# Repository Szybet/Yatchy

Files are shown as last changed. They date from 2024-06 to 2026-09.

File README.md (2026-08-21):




<h1 align="center">
  Yatchy
</h1>
<p align="center">
  <b>Y</b>our W<b>atchy</b>, fixed and improved, even made modular
</p>

<p float="left" align="middle">
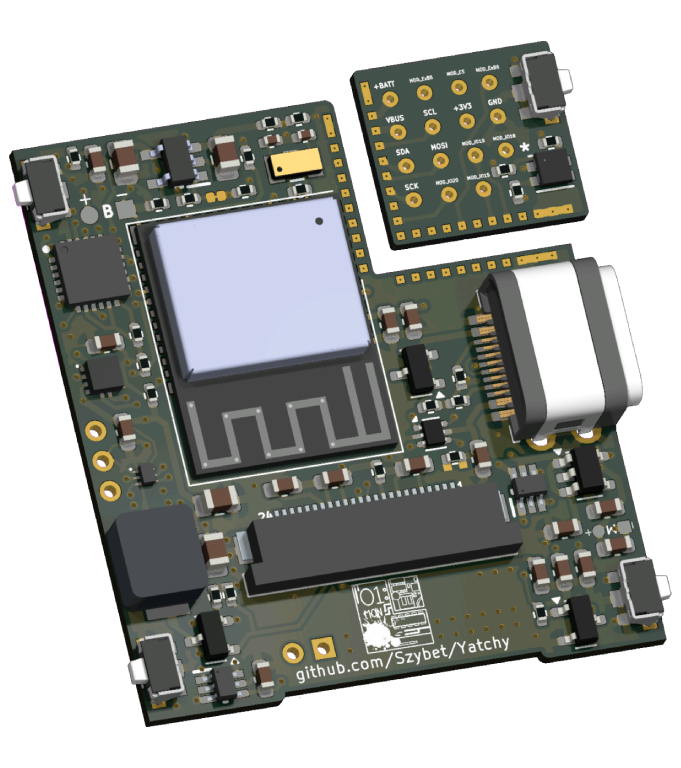
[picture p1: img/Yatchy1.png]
  
</p>

Yatchy is a DIY watch, heavily inspired by the well known [watchy](https://watchy.sqfmi.com/). It focuses on fixing known issues and expanding the potential of it.

#### Key points:
- USBC instead of micro usb
- Better buttons, they won't break easily
- [Better battery life](https://github.com/Szybet/Yatchy/blob/main/hardware/power-consumption/README.md)
- Hardware hackable, easier to self assemble from scratch
- Fixed many issues and improved minor things
- A backlight is possible, *[kind of](https://github.com/Szybet/Yatchy/blob/main/3D/cases/README.md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)* and many other "extensions"
- [Smaller](https://github.com/Szybet/Yatchy/blob/main/faq.md#dimensions) form factor

<details>
  <summary><h3>Pictures</h3></summary>
The coolest yatchy, contributed by a community member!


<sub>My Yatchy, with a [titanium anodized case, the rotated variant](https://github.com/Szybet/Yatchy/blob/main/3D/cases/JLC3D.md#anodyzed-slm-titanium-tc4-no-polishing)</sub>

<p>
  
  
</p>

<sub>The battery is on the side because it's easier for me to measure power consumption, there are [cases with the battery inside](https://github.com/Szybet/Yatchy/tree/main/3D/cases)</sub>



<sub>A clean soldering job, with some alternative components (compability!)<sub>, yes, I know there is a short on the flex cable, it fell off when cleaning after the picture</sub></sub>


Watchy one the left yatchy on the right, yatchy is smaller (yes, the battery is outside, but it would only increase height, not width/length



<sub>Picture contributed, thanks!</sub>

</details>

## Yatchy features in more detail:

<h4>For regular users</h4>

- Heavy increase in battery life, even with the screen updating every minute <sub>(The esp32c6 has a riscv lp core, which i connected to the screen, which means the device never really wakes up fully to only update the screen, not only that i fixed sqfmi flaws (Using 2 voltage dividers for example) I also use the external crystal clock for the RTC which means no RTC IC... and many more such things)</sub>
- Better buttons, more solid, shouldn't and probably won't break that much if at all. They are also very quiet. If you like the tactile feel of the original buttons, you won't like these ones. Luckly vibration motor feedback is possible.
- Solid USB-C port <sub>(It's THT soldered)</sub>
- no more usb compability problems <sub>(Because the esp32c6 uses native jtag programming)</sub>
- better detection of charging, charge finishing. <sub>(In software it was hacky on the original watchy, there were problems with it, never worked good)</sub>
- support for more wireless protocols, home automation ones, wifi 6 too
- TVS diodes, voltage spike protection - which means no more destroyed devices because watchy doesn't follow any USB spec and allows your device to burn down...
- More precise time, based on some loose math and experiments, it should drift only a minute after a month, compared to the watchy its a lot better, **from experience it's even better than that**

<details>
  <summary><h4>For advanced users</h4></summary>

- Detailed ordering and assembly [guide](https://github.com/Szybet/Yatchy/tree/main/hardware/create-your-own)
- Detailed soldering and testing [guide](https://github.com/Szybet/Yatchy/blob/main/hardware/create-your-own/assembling.md)
- **A module area**, with almost all exposed pins from the esp, power lines, and many gpio pins thanks to the expander IC - You can create your own module, increase the capability of you yatchy without modifying everything inside - solar panel module, encoder instead of the button, sd card module, frontlight module, torchlight module, speaker module, microphone module, some environmental sensors. The only limitation is your imagination (And the size of the module)
   - The default module (In the picture above) allows for for attaching small things without the need for a custom PCB
- All the components are newer, still available and produced. They are also listed, with links to mauser / tme. Ordering a Yatchy PCB and the parts, soldering them themself is possible and easier than the watchy
- All QFN packages IC's on the board have increased pad sizes, so if you are skilled enough to solder QFN packages, here it will be easier
- I used traces teardrops, so more solid traces & pads
- A [hardware test program](https://github.com/Szybet/Yatchy/tree/main/hardware/create-your-own/test-program), which allows testing if all the pads of the esp32c6, which is the hardest part to solder are soldered correctly
- JTAG debugging via usb, yay

</details>

<details>
  <summary><h4>Flaws</h4></summary>

- No battery connector, the module pads are small - so it's not for everyone, harder to use / assembly (solder!) for beginners
- There is no dedicated place for the motor, it needs a dedicated place in the case. Soldering the motor cables also is not easy
- It's watchy like but not watchy case compatible, the size and form factor is the same but the obvious obstacle is USBC, even with it the buttons are different and placed a little off to save some space
- It's a 4 layer PCB, so a bit more costly (With JLCPCB it's still cheap)
- No easy hard reset option, you will need to short pins, but you probably won't need it. <sub>When developing the Yatchy, I only once needed a full reset</sub>
- A complicated license (but still open source!)

</details>

## Software
It's fully supported by [InkWatchy](https://github.com/Szybet/InkWatchy). Maybe a rust firmware in the future? We will see...

## Hardware sources, buying, reselling, license, battery life, time accuracy
Everything explained [here](https://github.com/Szybet/Yatchy/tree/main/hardware)

## Cases, 3D files of the pcb
[Cases here](https://github.com/Szybet/Yatchy/tree/main/3D/cases) and [pcb 3D model here](https://github.com/Szybet/Yatchy/tree/main/3D/pcb)

## [FAQ](https://github.com/Szybet/Yatchy/blob/main/faq.md)

# Community
Create a github issue or get in touch with me on the discord server or matrix space (on top of this read are links)

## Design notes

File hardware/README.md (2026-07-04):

# Other related docs:
1. [Power consumption](https://github.com/Szybet/Yatchy/tree/main/hardware/power-consumption)
2. [Time accuracy](https://github.com/Szybet/Yatchy/blob/main/hardware/time-accuracy.md)
3. [Create your own](https://github.com/Szybet/Yatchy/tree/main/hardware/create-your-own)

## License
<sub>Read all of it :)</sub>

This work is licensed under a [Creative Commons (4.0 International License) Attribution—Noncommercial—Share Alike](https://creativecommons.org/licenses/by-nc-sa/4.0/)

Don't scream "IT'S NOT OPEN SOURCE", let me explain myself.

- First, this work is not a watchy fork, it's a complete redesign obviously inspired by the watchy form factor, but nothing more.
- I don't want SQFMI to steal this design and sell it. Not even if I could profit of it. His bad software, bad communication, sometimes bad and questionable hardware decisions have killed so much potential of the watchy.
- I don't want someone to just make money off it and give nothing back to the project. With that said, calm down, more on that in the commercial section below.
- I don't want for someone to rename it and take the credit for the hard work.

Is it too much to ask for? The whole issue above I have is very known in the open source world, you can see it everywhere around us, here is [Jeff](https://youtu.be/4aaF2HgTVe8?t=84) talking about it. If there appears a open source license which fixes this issue, I will switch to it. 

Oh did I mention **it's is open source anyway?\*\*\*** I share the full source, the schematic, the PCB source files, the needed* (more on it below) software. It's just not the pure open source definition, but the literal interpretation of it. Element of open source like contributing, forking etc. are still allowed and welcome, but with the restrictions above.

<details>
  <summary>Further thoughts about it:</summary>

On https://opensource.org/osd we can see, in the first point "Free Redistribution" and well, first "as a component" hardware can't be a component really, so this point doesn't apply to hardware. The whole point doesn't work for hardware, we know how the world works, it works for software, that's why [InkWatchy](https://github.com/Szybet/InkWatchy) is GPL3. Let's search further, on https://www.oshwa.org/faq/#what-license-to-use we can see the question "Won’t people rip me off?" exactly what I have been searching for! The answer is "Maybe"... ugh... Well their explanation is good but a maybe is too much for me... There is also that: https://mifactori.de/non-commercial-is-not-open-source/

The blog post just shows a general opinion / statement on the internet about this topic, some of the points there make sense to me but some not at all, like `Yes, you do. But so does every patent` Wtf even is this? Sharing something to file a patent is completly different from sharing everything to be reproductible. Also patents can't be compared to hardware things most often because patents say you created something new, but hardware is often a combination of other creations, not entirely new things. Open source is not just "It's commercial, you can ripp me off", it's more than that...

so the entire situation is a joke for me. I can't have a "open source" hardware license without someone "Maybe" ripping me off. So it looks like that:

What I want from "Open source":
- To allow people modify, build their own from scratch, even sell the hardware to some extend, do deep repairs etc. (Which I do, but I'm forced to use the `Creative Commons (4.0 International License) Attribution—Noncommercial—Share Alike` license.)

What I don't want:
- People ripping me off

Sad, it just looks like someone long time ago took a software license, applied it to hardware which doesn't work in the real world and started calling out everyone "Uh oh, it's actually not open source because you are not allowing people to ripp you off"

Rant end, here is what you are left with:

A device that is not open source from the strict definition, but has the bare source for replication available, with elements of open source allowed and the author is open about this all.

* * *

It's not only me having this opinion, other makers also share it:
- https://github.com/o7-machinehum/flipper-blackhat-a33#license

:)

</details>

Update 2026:

Prusa released the [Open community license](https://github.com/OpenCommunityLicence/OpenCommunityLicence) which is basically what I'm saying above but I allow a bit of commerciallity, so that's cool, if they release a plugin like the Micro Business one, but smaller (Nano business?) then I would switch fully to it, so it's less confussion.

## The design of the Yatchy
Yatchy was designed to:
- Be created by yourself. That means it's adjusted to be hand solderable. Sooo that means changed footprints for easier hand soldering. If you can solder SMD without a problem and QFN packets aren't scary for you, but BGA is a bit, then it's for you
- Extremely hackable and modular. The main point is the module and all exposed pads for it
- Optimisation of the ammount of different components, so cheaper
- I tried to use widely available IC's and components. For example, while using some highly mauser only specific IC could improve power consumption a small bit, I preffered the simplicity and availability of the current design

Those design choices have their own flaws:
- It's not possible to order a assembled yatchy from a manufacturer. Not only because of the module, but the modified footprints have not adjusted solder mask (And I don't have the experience and money to test it). **Also to be clear, a stencil is also untested, probably won't work for the reasons explained a sentence ago, you have been warned.** - And with that in mind, let's go to the commercial section

## Commercial
As mentioned above, It's not possible to manufacture yatchy on a mass scale (The original vision ones, doing a "regular" one, sure i gues). I don't even want to, I'm a student, I won't just start a company. I plan to sell a few Yatchy to community members and that's it.

But if you plan to create a Yatchy for yourself (because you have the skills required) you are fully allowed to do so! I will support it fully, you should also consider creating some for people who can't do that. I will fully support it too! Just remember to contribute some docs, code, help, small donation if you create some more and it will be fine :D

So "Commercial use" for the yatchy as in: using it as a cash grab, without giving anything back, which is not allowed.

If you plan to really mass produce them, then we should talk I ques.

**So you want to create your own? There is a doc for that: [Creating your own](https://github.com/Szybet/Yatchy/blob/main/hardware/create-your-own/README.md)**

## The ability to enforce the license
First some explanation:

Yatchy uses esp32c6 which has a lpcore which allows for updating time on the screen in a more efficient way, in a seperate program.

So all this talking is cool but it's just on paper, I can't enforce it, let's be real. That's why I will lock the full source code of the Yatchy lp program until I make back of what I invested. It costed more than I hoped for. Yatchy can still fully function without the lp core, just the battery life will be worse. I will share the source code partially to all yatchy users (also from other potential sellers) to allow to modify it, like the font used. Then I will simply compile it for them. **Yes, it could be converted into a binary library with a header api**, it was simply not done yet as the program is complicated and has a complicated structure. So that scenario is upon a possible request

More details [here](https://github.com/Szybet/Yatchy/blob/main/hardware/lpcore.md)

## The source files
Kicad version 9.0.3 is suggested.

In the kicad folder inside this directory are the design files for the yatchy v1, not yet tested

they (PCB's) are also a bit messy, not fully profesionall, but they do the job, I hope, as I will order them

Yes, the source files reference watchy in a few places, that's because the name "Yatchy" came after, at first this project was planned to be a small watchy fork.

Schematic, iBom can be seen here: https://szybet.github.io/Yatchy/hardware/read-only/index.html

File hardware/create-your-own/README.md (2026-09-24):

## **A reminder, all of this is provided without any warranty. If something goes wrong and the PCB is bad, wrong components, not my fault**

# [Ordering components & Price](./ordering.md)

# Viewing the PCB & schematic
It's available [here](https://szybet.github.io/Yatchy/hardware/read-only/index.html) but I advice using kicad directly anyway, as this site could be outdated

or [kicanvas](https://kicanvas.org/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)!

# [Assembling Yatchy](./assembling.md)

## Binner.io
~~I started using Binner.io, if you want to manage your Yatchy parts in it, [here](https://github.com/Szybet/Yatchy/blob/main/hardware/BinnerParts.xlsx) is the export with all the parts. Yes, it could be outdated.~~ Don't use it: https://github.com/replaysMike/Binner/issues/397 :(

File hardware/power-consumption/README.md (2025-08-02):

## Note
Obiously this is outdated, constant updates and improvements will make those numbers better (not by a lot but hey), but probably not make it worse (not by a lot but hey) so this is just a very general overview

## TLDR: Please read this document to understand that measuring battery life is challenging. The best-case scenario calculations are provided at the end. This document explains the results, emphasizing that they do not tell the whole story. Your actual battery life may be worse than indicated, and I want to clarify that I take no responsibility for this (For anything really)

Once again, **once again** and ***once again and again*** those measurements are not in lab quality - I measured things again after a few months and it showed 3 times more. Did the humidity change? Did saturn catch mercury in a 10 degrees of happiness? Did the meassuring tool catch some dust? Idk? **What I can say I just used it for a while and those results are reasonably mirrored in real life, so take this doc as a best case scenario**. Also did I mention using different components from different batches can result in worse battery life from nowhere? That's also fun, so your Yatchy can work worse. Or better :)

Ok, first, measuring power at such low values is extremely hard, temperature, humidity can affect the values. Not only that, your touch, sight, planet position, random things can affect the results. What I'm trying to say, it's extremely hard, those are not 100% scientific values. But I took them many times to make sure they are similar and they have been taken on the nordic power profiler kit II, so it's valid enough I think.

The best example of problems I'm facing is that I used some nail polish to make it more water resistant, this improved the power consumption by -20uA. It could be that, my best ques at least... It's really random and hard

[Here](https://github.com/Szybet/Yatchy/blob/main/hardware/power-consumption/Where%20is%20my%20current%20-%20The%20game.pdf) you can see my latest fight with the demons of power consumption, the enemy who stabbed me from the back was... the LED diode (But I fixed it, now it's a lot better).

Also, a funny video demonstrating how measuring such low currents is hard, it's just my hand, no magnets or anything

https://github.com/user-attachments/assets/14860d4f-65ae-4cec-a94b-b5c265fb9386

Now that we know to not worship those results, some important things first:
- Yatchy obviously uses the lp core
- Those are only during time updates, not interacting with the watch. Any interaction will obviously drain a lot of battery, so the final battery consumption will be heavily based how much you just look at the time or just interact with the watch
- The `.doc` files in this dir can be used to calculate the power consumption for your settings, battery. But to understand what is going on there, first you need to read the rest of this document. **Oh and the docs screenshoots are at the bottom of this document if you don't want to change anything but you are too lazy to look it up**
- Those files are chaotic, I know, I don't care, they do their job
- For watchyv2-calculations.ods to match this: https://github.com/Szybet/InkWatchy/wiki/InkWatchy-battery-life-measurements you need to take into account that the measurments there had a night delay, while those calculations don't. To make those results match, set the wakeups in one hour to 43. Yatchy doesn't need such optimisations, that's why I skip them ;)

Devices used:
- Yatchy v1 without an accelerometer. If you want to "simulate" adding of the acc, add a few uA to the full sleep value
- Watchy v2, regular one.

Description of functioning of those devices

Yatchy:
- "Regular lp core time update" Is the most regular time update, it happens most often, almost every minute
- "First time update lp core" Happens after "hp core update"
- "hp core update" Is when the main program, in this case InkWatchy is launched. You can control how often this happens, at default it's every 29 minutes so 2 times an hour. It takes the most amount of battery, but it's important as it updates other things on the watch, not only the time.

Watchy:
- Here it's just "hp core update" all the time, as Watchy v2 (or even v3) can't use the lp/ulp core to update the time

# Conclusions
I'm happy with it

Now some images that explain the values in the docs

# Yatchy
Full sleep


Lp core regular time update


Lp core first time update


Hp core wakeup (In the future, it could be 1s smaller)


# Watchy v2
Full sleep

Umm this looks a bit much, well, power consumption magic, maybe my connections is somewhere off, maybe something something is off. Previous reads, which I don't have saved gived me reads of around 130-160uA so let's treat it like this, this picture is anomaly

Hp core wakeup (It matches in timing the one from Yatchy & 


## SS
yatchy calculations:

watchy calculations:


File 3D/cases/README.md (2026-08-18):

# Yatchy cases
If you create your own model, fork one, or anything else, please (in addition to putting it in your repository, on a 3D model website, if you feel like it, etc.) contribute it here so it won't get lost in the ether of poor search engines. Sharing files that can be modified easily (STEPs, not STLs) is also suggested, but not required.

### The files are in the folders in this directory

### JLC3D
If someone doesn't have a printer or wants some premium quality (materials), [Here is a review of JLC3D for yatchy cases](./JLC3D.md) (Not sponsored)

<h1>$${\color{red}Patches}$$</h1>
Because of the tight tolerances and different printers, filaments, some cases might have alternative parts that might fix your issues, read their description and decide for yourself, generally, I would advice using them

## Szybet's side case
<p align="center">
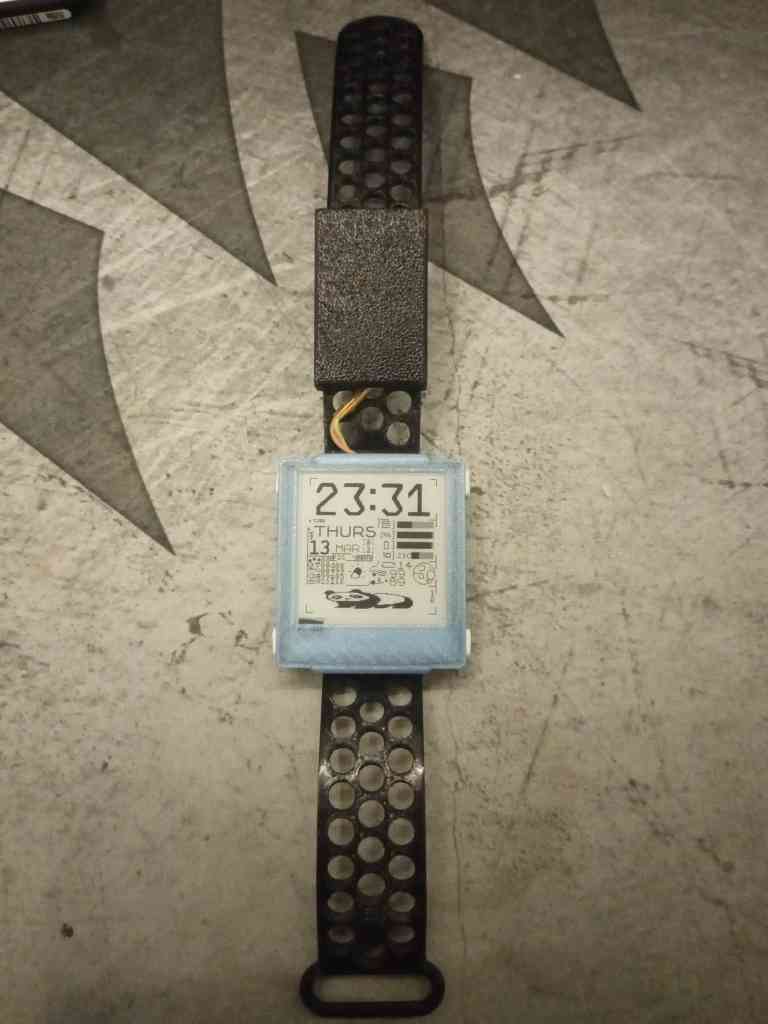
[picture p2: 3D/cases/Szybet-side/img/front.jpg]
  
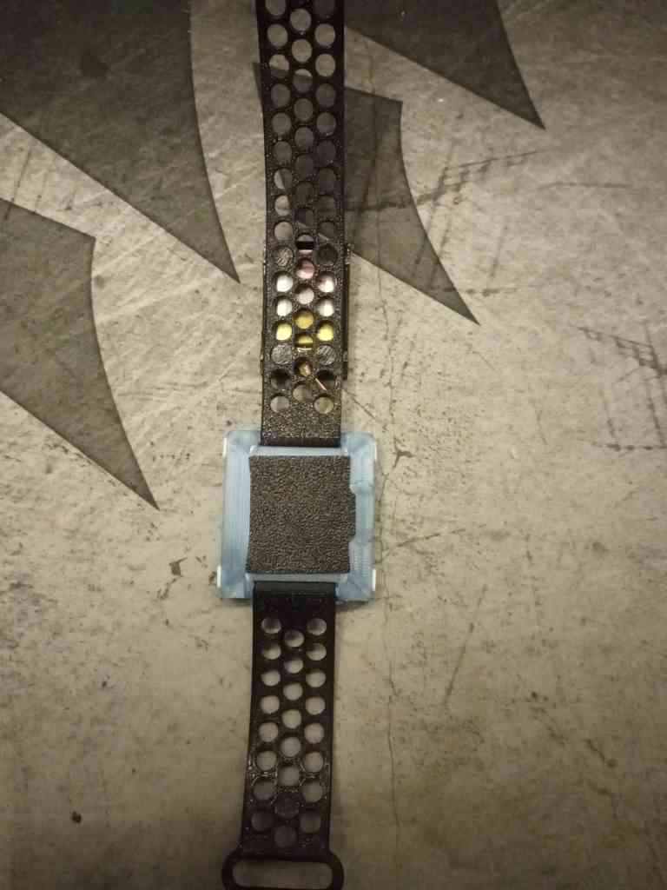
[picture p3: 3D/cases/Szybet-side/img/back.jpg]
  
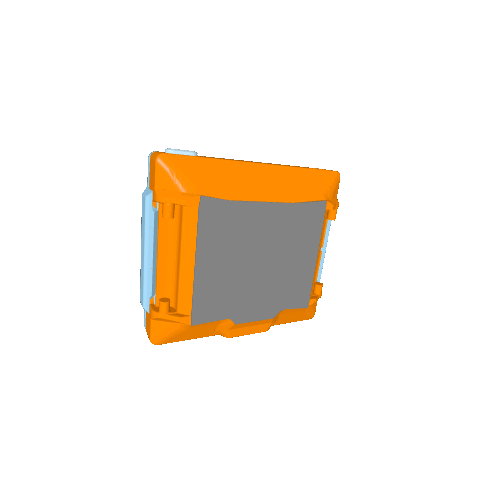
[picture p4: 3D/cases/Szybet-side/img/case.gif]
  
</p>

<details>
<summary>Fit and dissasembly demo</summary>
  
<p align="center">

https://github.com/user-attachments/assets/d5af4c48-378c-4553-9d58-3c49acbb4d74

</p>

</details>

Notes:
- Yes, it's designed for the battery to be on the side (and more space for module hackery), yes you can modify it for your needs
- The top snaps into the bottom case, no screws, it's tight and easy to dismantle
- The strap & battery case is printed from a flexible material, TPU in this example.
- Requires a 0.2 nozzle, a **very good 3D printer**. The tolerances are very tight. - for the case, the layer adhesion must be good otherwise it could break when buttons are inserted. (Semi transparent PETG has good layer adhesion, I think)
- The motor cover is for this motor: https://pl.aliexpress.com/item/1005004948677826.html?gatewayAdapt=glo2pol
- The module led cover is for the led to redirect the light to the side. I used a silver marker for better effect
- The side battery case has many files in it, they all should be printed as they are
- Needs strong layer adhesion, otherwise it will break near the edges. Some glue on the inside or transparent PETG does the job
- Patches nr 1 apply

License:

[Creative Commons (4.0 International License) Attribution—Noncommercial—Share Alike](https://creativecommons.org/licenses/by-nc-sa/4.0/)

### Szybet's brick case
<div align="center" style="white-space: nowrap; overflow-x: auto;">
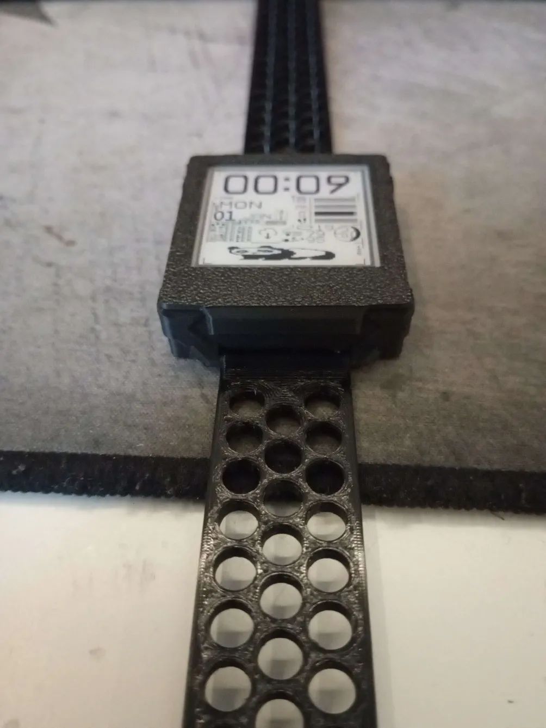
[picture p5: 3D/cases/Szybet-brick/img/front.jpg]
  
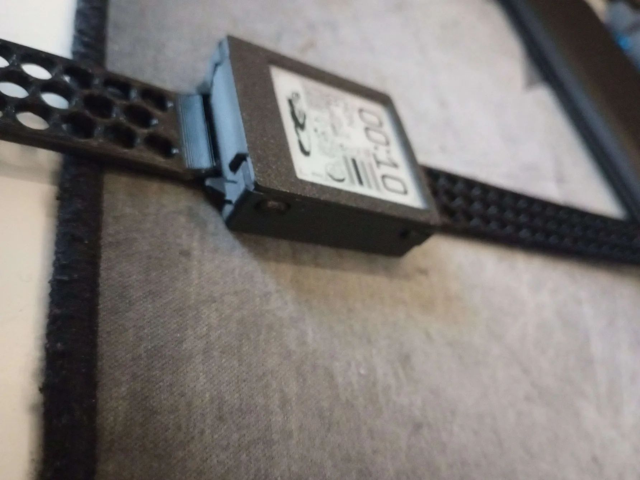
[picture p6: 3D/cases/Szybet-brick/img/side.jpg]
  
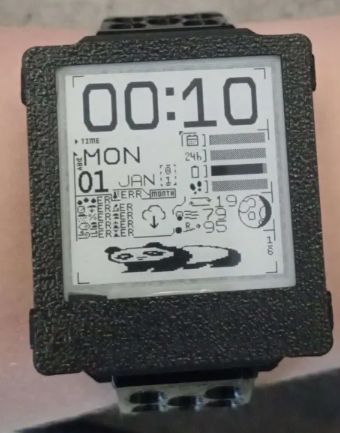
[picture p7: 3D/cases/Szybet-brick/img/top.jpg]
  
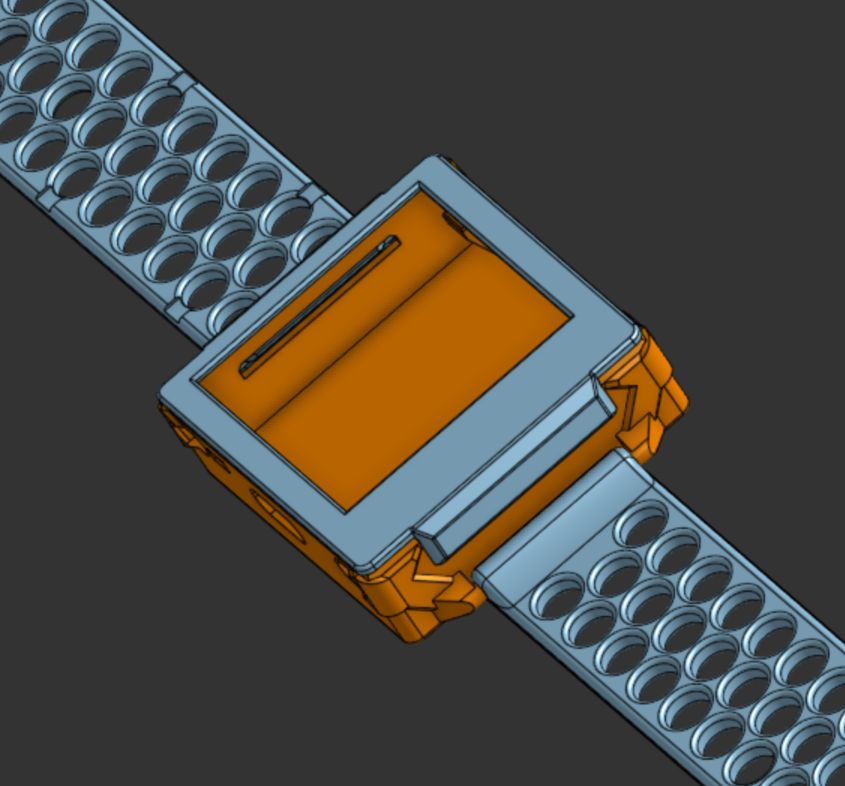
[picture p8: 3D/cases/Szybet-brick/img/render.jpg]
  
</div>

Notes:
- This is a fork of "Szybet's side case", most of the notes from there apply here (license too), the design of the buttons, top is the same
- Yes, it's a simple brick, based on the side case, it's a base for modifying it for other cases with the battery inside
- The texture on the corners is for making them stronger, less breakable
- The strap still has cutouts for attaching something to them
- If the battery is inserted in a wrong way and the cables will touch the buttons, they might get stuck
- Patches nr 1 apply

### KitKat's rotated case
<div align="center" style="white-space: nowrap; overflow-x: auto;">
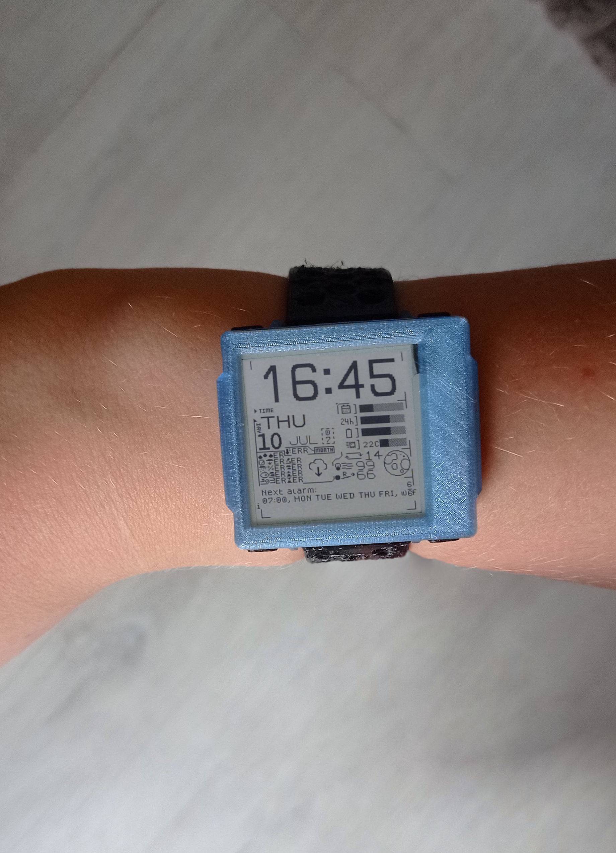
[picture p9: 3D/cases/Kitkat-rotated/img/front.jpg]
  
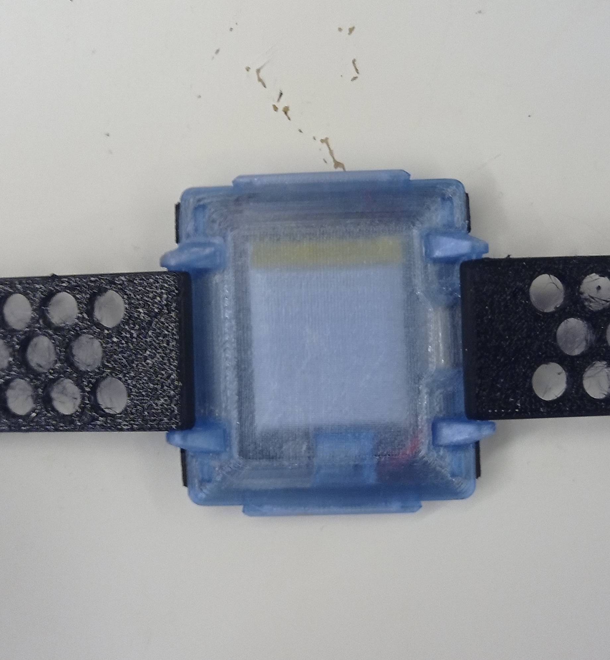
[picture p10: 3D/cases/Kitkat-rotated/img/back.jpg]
  
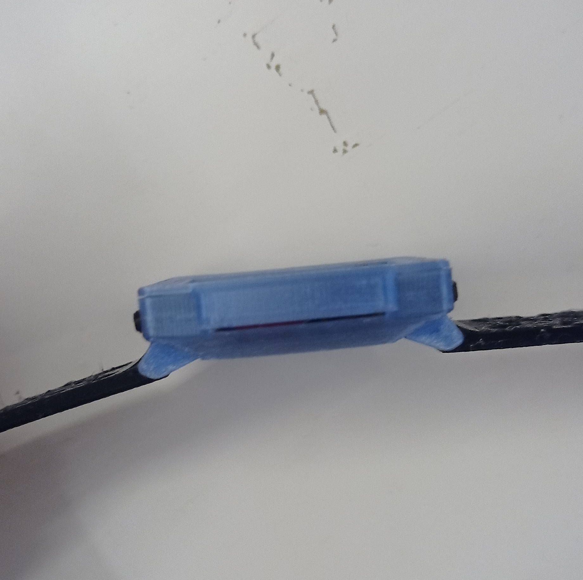
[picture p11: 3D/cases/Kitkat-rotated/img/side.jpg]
  
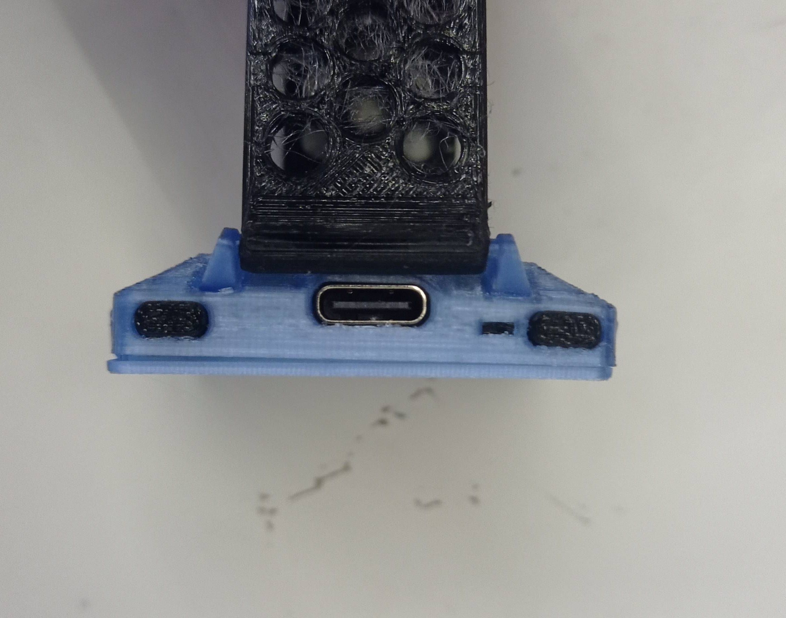
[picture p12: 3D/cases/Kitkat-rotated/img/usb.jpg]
  
</div>
<div align="center" style="white-space: nowrap; overflow-x: auto;">
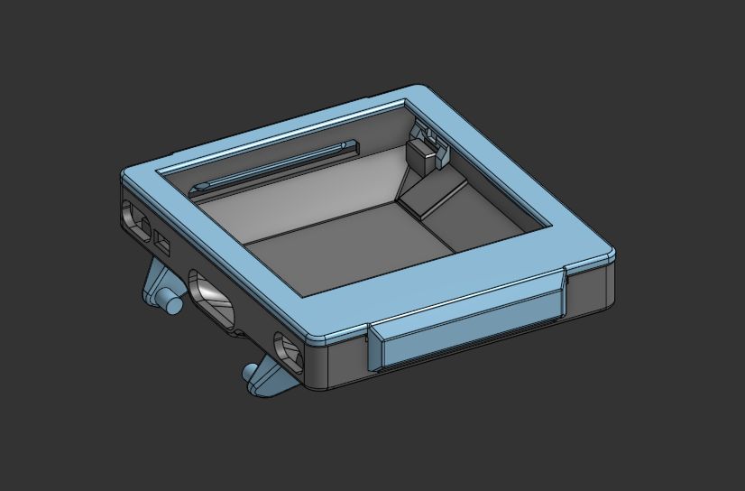
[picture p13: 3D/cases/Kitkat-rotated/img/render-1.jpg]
  
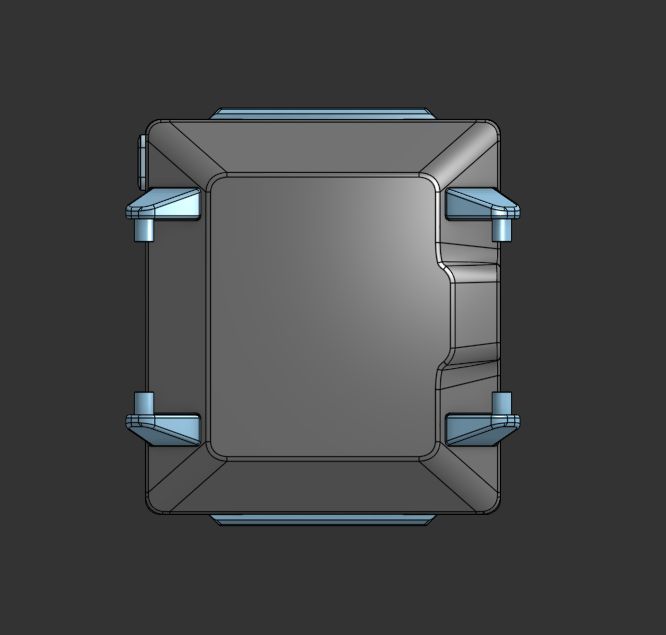
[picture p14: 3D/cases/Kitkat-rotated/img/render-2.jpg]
  
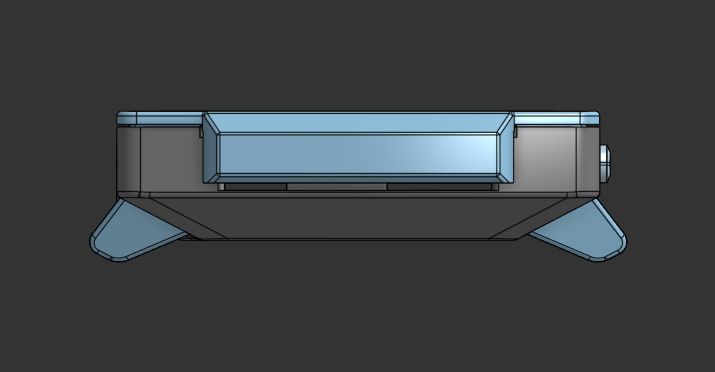
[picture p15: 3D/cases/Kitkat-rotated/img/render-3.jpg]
  
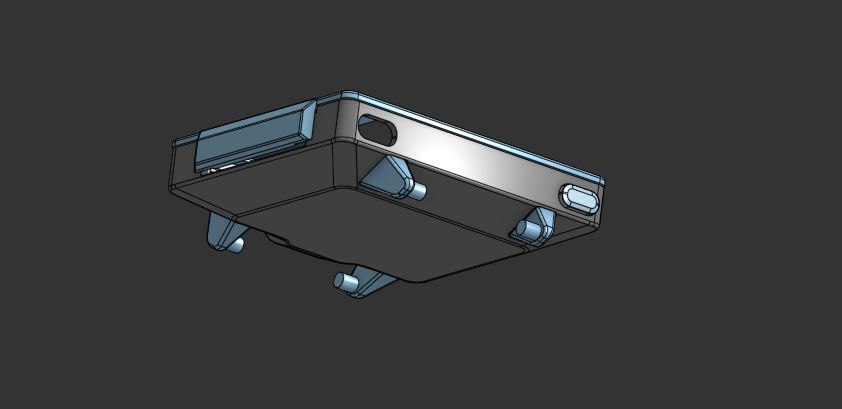
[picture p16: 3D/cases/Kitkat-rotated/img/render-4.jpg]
  
</div>

**The Images above are for the 150Mah case version**
<div align="center" style="white-space: nowrap; overflow-x: auto;">
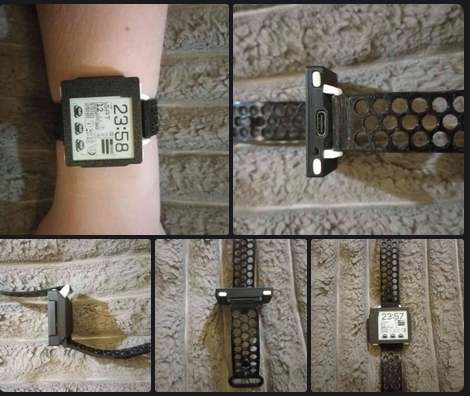
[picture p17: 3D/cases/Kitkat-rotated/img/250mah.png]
  
</div>

**The Image above is for the 250 mah case version**

#### Proof of concept: Glow in the dark transparent filament (With the rotated case)
<div align="center">

https://github.com/user-attachments/assets/10055fae-86bb-440f-bbc3-9d33e8c1605a

</div>
  
- Kind of a backlight, I can read the time. It could be improved in many ways (Increase led brightness, use a reflective tape inside the case)
- The glow in the dark filament looks better in reality than on camera

Notes (About this case in general):
- The 250 mah battery is 30 x 20 x 5 mm and the 150 mah battery is 25 x 20 x 4 mm
- The strap holders on the 250 mah version are assymetric
- This is a fork of "Szybet's side case", most of the notes from there apply here (license too), the design of the buttons, top is the same
- Requires changing the config in Inkwatchy so the screen is rotated properly
- The pieces that hold the straps need to be glued onto the main body using superglue
- The strap still has cutouts for attaching something to them
- The battery fits inside but requires short wires for it to fit properly 
- The motor is attached to the inside of the case which can make it more difficult to dissasemble
- Larger USB-C plugs may not fit due to strap clearance
- case_front_v2 and better_strap_dot from patches 1 applies
- Those are pictures of a prototype
- **The buttons are objectively easier to access**
- The LED now shines outside of your wrist, not on it                                                                                                                                         

### Glaucon1984's Brick case remix
<div align="center" style="white-space: nowrap; overflow-x: auto;">
  
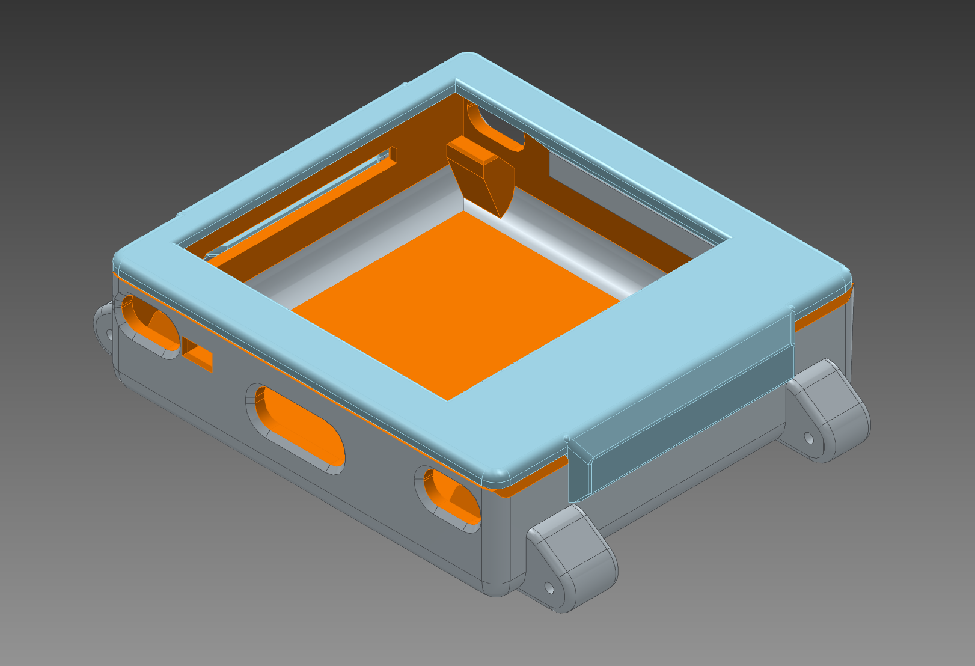
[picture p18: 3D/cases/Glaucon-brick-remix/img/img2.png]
  
  
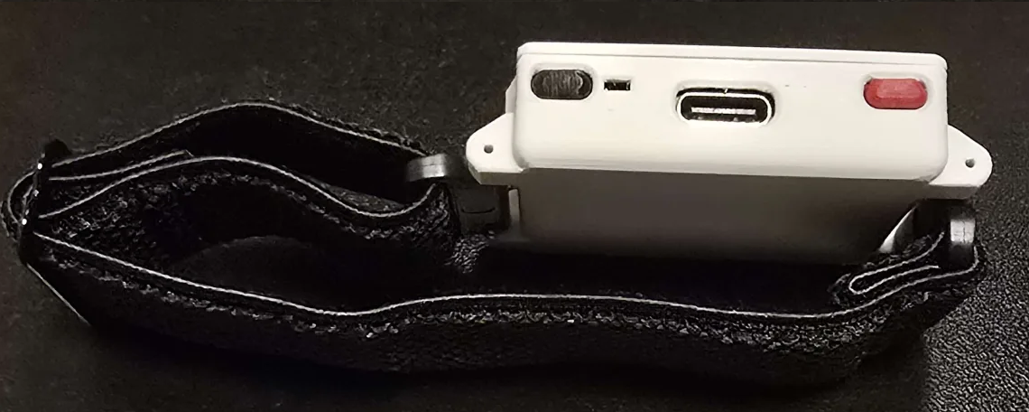
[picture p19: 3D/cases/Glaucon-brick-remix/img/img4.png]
  
</div>

Notes:
- The main purpose of this remix is to be able to use regular watch straps, make the case a bit stronger and have smoother edges, these are the main changes:
- Based on Szybet's brick case
- Made thicker walls and bottom
- Smooth edges
- Added prongs to attach a 22mm strap
  - It uses a standard 22mm watch strap, the one in the picture is this one: https://www.amazon.co.uk/dp/B0C2414BMX (nothing special about it, I think it was one of the cheapest ones)  
- Added some geometry to centre the circuit board
- The front panel hides a bit more of the bottom of the screen (you can see the picture)
- Buttons are slightly longer to account for the thicker walls in the case
- The holes for the buttons and the USB-C port are chamfered to hide the imperfection from 3D-printing supports
- The top case is slightly thicker
- The 3MF contains print settings, but just in case, it must be printed with a 0.2 mm nozzle. It's been tested only with PLA and it works great. I recommend a 0.6 mm layer heigh for precision. There's very little infill in the model but I would recommend to use gyroid at 30%. The watch case should be printed on the flat side of each part, the buttons should have this side touching the build plate:


- Creator's [makerworld page](https://makerworld.com/en/@glaucon1984) and [makerworld page for this case](https://makerworld.com/en/models/1798293-yatchy-brick-case-remix)

### Glowy's Thicc boi  

<div align="center" style="white-space: nowrap; overflow-x: auto;">
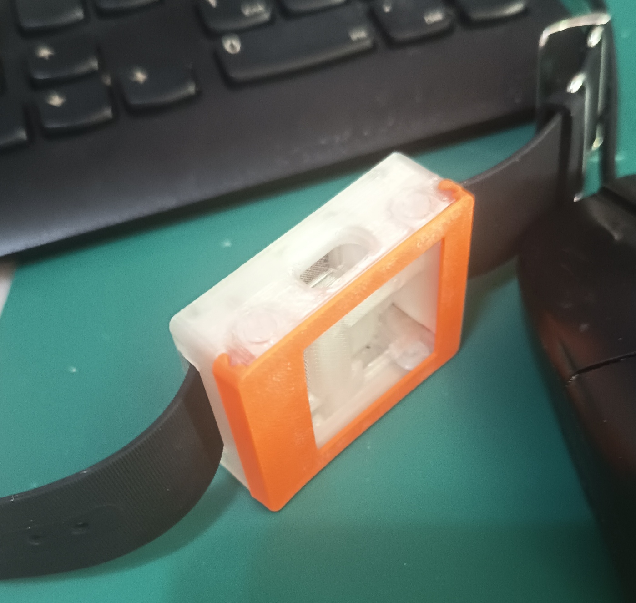
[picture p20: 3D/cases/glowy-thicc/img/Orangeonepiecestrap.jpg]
  
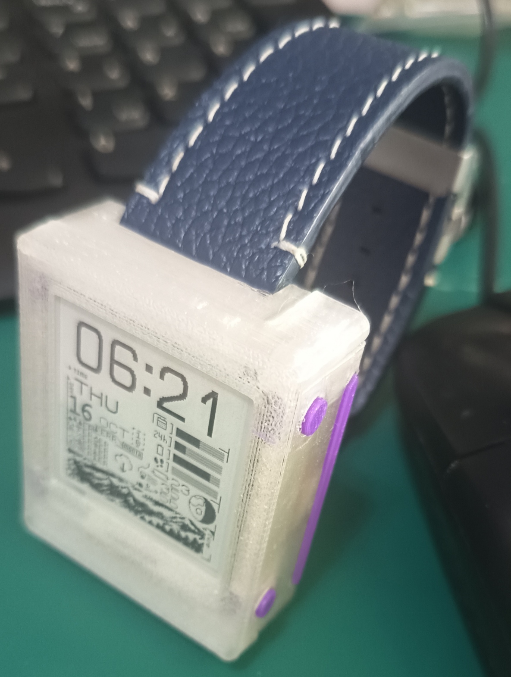
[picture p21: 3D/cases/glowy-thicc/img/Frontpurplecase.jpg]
  
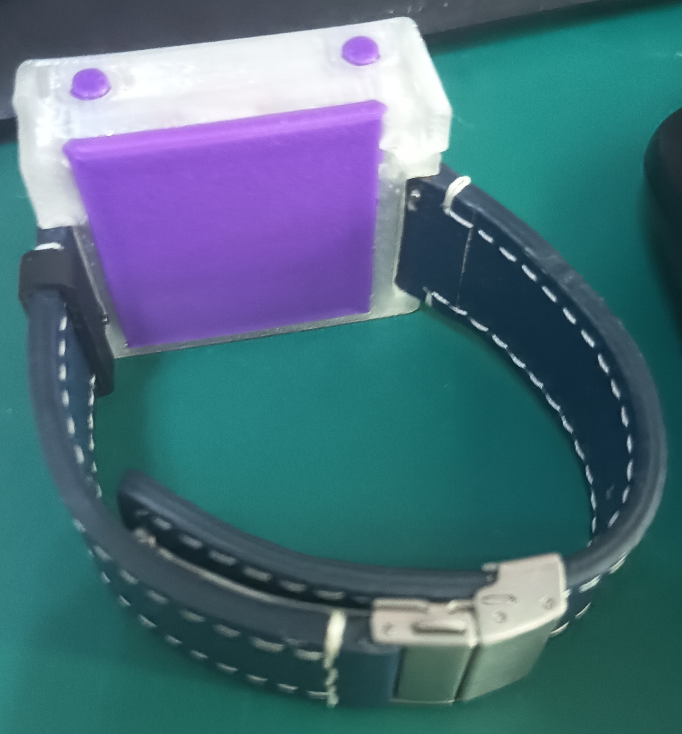
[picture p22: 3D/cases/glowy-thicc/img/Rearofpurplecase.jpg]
  
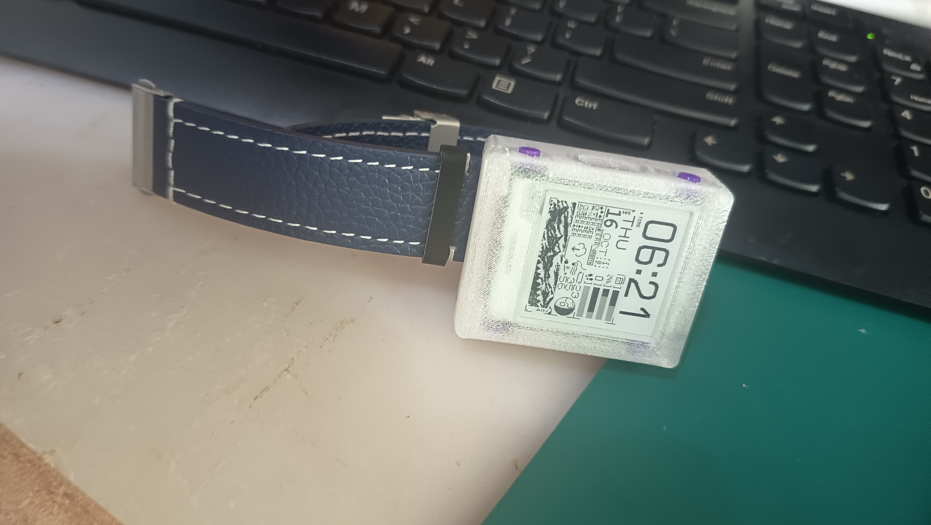
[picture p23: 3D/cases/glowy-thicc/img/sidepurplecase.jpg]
  
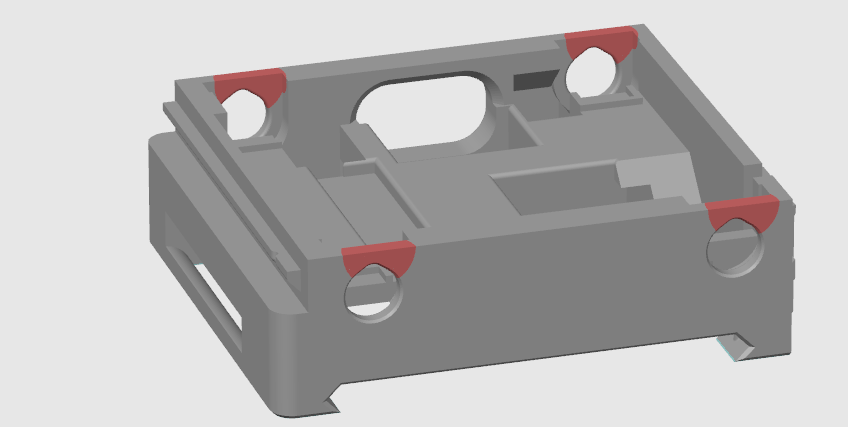
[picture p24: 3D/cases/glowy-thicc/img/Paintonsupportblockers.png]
  
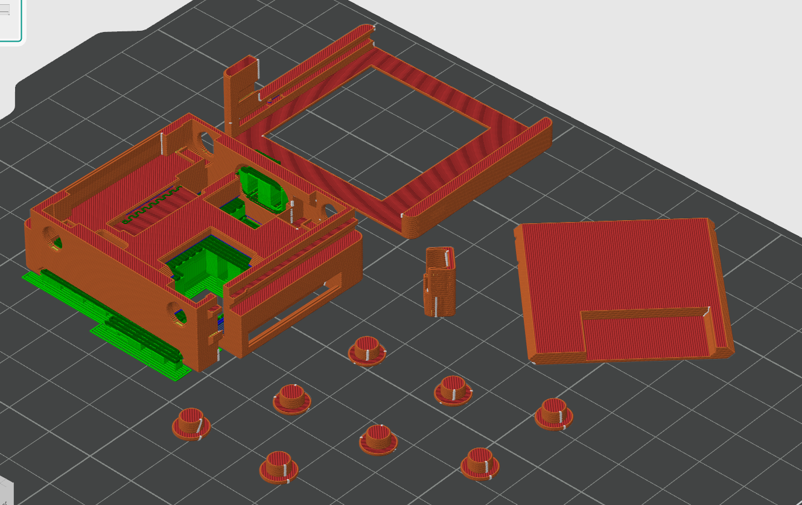
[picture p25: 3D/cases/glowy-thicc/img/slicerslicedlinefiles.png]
  
</div>

**Notes:**  
- This design was **created entirely from scratch**, not based on any previous Yatchy case or remix.  
- The **walls are thicker**, offering more protection and a sturdy feel.  
- A **light-reflecting patch** allows illumination through translucent filament — or use aluminum tape to redirect the light outward instead of into your hand.  
- The **faceplate is easily removable and customizable**, and no glue is needed during assembly.  
- Designed for **quick part swaps and battery replacements** without modifying the model.  
- The case remains **comfortable and ergonomic** despite its thicker construction.  
- The **battery compartment** fits packs up to *33.9 × 25.9 × 5.4 mm* (tested with a 250 mAh cell).  
- The case has been **impact tested** — with an acrylic faceplate, it even survived a 200 fps 1 g projectile.  
- The **strap shown** in the pictures is a *24 mm leather watch strap*,  [this one on Aliexpress](https://www.aliexpress.com/item/1005005510563576.htmlhttps://www.aliexpress.com/item/1005005510563576.html) — though any standard 24 mm strap works fine.
- For the one piece strap you can use any 22 mm x 1.6~mm thick strap [this one on Aliexpress](https://www.aliexpress.com/item/1005007712667222.htmlhttps://www.aliexpress.com/item/1005007712667222.html)

If any issues arise, or you would like to use another type of strap, feel free to reach out on Printables or Discord, glowyglowbug.  

**View on Printables:**  
Thicc Yatchy Case (https://www.printables.com/model/1443956-thicc-yatchy-case)

**Watch the Demo:**  
Watch the Demo (https://www.youtube.com/watch?v=wA29wyvOd8w)

### Michal's gameboy
<div align="center" style="white-space: nowrap; overflow-x: auto;">
  
  
</div>

- More info at: https://github.com/Michal-Szczepaniak/watchy-case/tree/master
- Fits the 450mAh 303040 LiPo
- Inspired by the watchy gameboy case

### Case comparison
- without top case or the pieces that hold the straps

| Case | Height (mm) |
|---|---|
| Kitkat's Rotated 250 mAh version | 10.29477 |
| Kitkat's Rotated 150 mAh version | 8.70611 |
| Szybet's Side | 9.55611 |
| Szybet's and Glaucon1984's Brick | 10.96346 |
| Glowy's Thicc Boi | 15.3 |
| Michal's gameboy | 11.2 |

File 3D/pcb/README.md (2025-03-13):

This model is a simplified (so not so heavy, while keeping geometry) model of v1 Yatchy pcb, screen and flex cable.

Notes:
- not the V1.1, if you want a more precise one, just export it from Kicad.
- also the module is included with it
- you might want to add a small offset from the pcb to the screen, as double sided tape is in between. In practice, if your tolerances are right (so, any, small ones) this should just work and be tight

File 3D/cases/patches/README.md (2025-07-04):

## 1
- case_front_v2.step - a more tighter version of the front part of the case. Useful when tolerances are bad enough that buttons click each other
- motor_cover_thinner.step - Thinner motor cover, harder to use and place but takes less space
- better_strap_dot.stl - easier to insert strap dot

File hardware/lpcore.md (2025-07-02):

## A more technical explanation

The ESP32-C6 in Yatchy has an LP core, which is a coprocessor optimized for efficiency and runs in RTC memory. It has a maximum of 16KB of memory (without any allocation) or just 8KB for easy compatibility with Watchy firmware, which uses the other 8KB.  

I wrote a program in Rust for this core that displays the time on the screen. This required setting up or modifying:  
- Getting Rust to run on it  
- Log mechanics (to monitor what's happening, disabled in release)  
- RTC memory handling (basic communication with the HP core, i.e., the main program)  
- RTC register access to retrieve time  
- Software SPI (since there's no native SPI)  
- Display driver  
- Minimalist font rendering via partial updates with a small buffer  
- HPCore wakeup  

All of this fits in ~~just 8KB (technically 7KB).~~ Now in 9KB (For better fonts)

It was quite a bit of work, and no one else has done it before. However, for reasons I outlined in my repo—mainly to prevent others from copying the design and selling it without giving anything back—I plan to release only the font rendering part.

Oh, and once I recover the money I invested in developing Yatchy, I'll release everything publicly—no questions asked.

## Font

Because of size constaints, the font is simply some points connecting in lines, like that:

```rust
pub fn draw_zero(fb: &mut wepd::Framebuffer<NUMBER_WIDTH, NUMBER_HEIGHT>) {
    let start = Point::new(6, 4);
    let right_top = Point::new(26, 4);
    let right_t = Point::new(29, 10);
    let right_b = Point::new(29, 38);
    let right_bottom = Point::new(26, 44);
    let left_bottom = Point::new(6, 44);
    let left = Point::new(3, 38);
    let left_top = Point::new(3, 10);

    let points = [
        start,
        right_top,
        right_t,
        right_b,
        right_bottom,
        left_bottom,
        left,
        left_top,
        start,
    ];
    draw_lines(&points, fb);
}
```

But thanks to a [contribution from someone](https://github.com/themkoi) there is now svg to code above automatic conversion, so there are many fonts and they are easier to modify and add. They also look better now, as someone tinkered more with them.

### Creating your own font
(for your own watchface, or simply to adjust for inkfield)

The svg files are up to request, but there are some thing to keep in mind while modifying them:

TODO

***

Let's showcase the ones that are there now, keep in mind:
- Those are codenames and probably outdated codenames
- They are all based on one design, only with minor changes

### Font2


### Font2_bold


### Font_szybet


### Font2_opt


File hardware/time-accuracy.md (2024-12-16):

Test devices:
- watchy v2 with PCF8536 (which in my experience worked better than for other v2 users) 
- yatchy with 20 ppm quartz

Further notes:
- This test is just me making `currentSeconds - ntpCorrectSeconds` in clock debug menu, no fancy scientific stuff
- There are no drift corrections applied, they would help with the stable temperature test but not with the changing temperature test.

## In room temperature
Test time: 1d 9h 27m

Drift:
- watchy v2 - 19 seconds
- yatchy - 2 seconds

Conclusions:
- This watchy v2 would drift a full minute after around 3 days, which matches my experience and usage of it
- This yatchy would drift a full minute after around 31 days, which matches my calculations

## In normal, temperature changing usage
So, outdoor, indoor like a lot, around 0°C

Test time: 20h 6m

Drift:
- watchy v2 - 11 seconds
- yatchy - 4 seconds

Conclusions:

Both drift more, as this test took less time. Yatchy drifts more than I thought but less than some thought and I feared. So yes, the drift will depend on your usage and the temperature outside. But it's still better than watchy.

## End conclusions & Future
It's a bit worse than I thought, but it's okay, but you should decide for your own. I will probably in the future use 5ppm quartz instead of 20ppm ones. The 5 ppm are harder to source, but are 4 times better than the 20ppm ones (Any 32khz quartz will fit, it just needs to be 12.5pF)

If you feel like it, you could just create a module / do some hacky soldering an attach a modern rtc ic to yatchy via the module pins and use that ;)

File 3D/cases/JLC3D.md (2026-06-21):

### SLM Titanium TC4

|  |  |  |
| --- | --- | --- |

<sub>the inside is coated with nail polish in this picture for it to not conduct electricity</sub>

##### Anodyzed SLM Titanium TC4 (No polishing)
|  |  |  |
| :---: | :---: | :---: |

### SLA 8001 Resin transparent
|  |  |  |
| --- | --- | --- |

|  |  |  |
| --- | --- | --- |

### MJF PA12-HP Nylon
|  |  |  |  |
| --- | --- | --- | --- |

### SLA JLC Black Resin
|  |  |  |
| --- | --- | --- |

### FDM Transparent TPU
|  |
| ---------------------------------------------------------------------------------------------------------------------- |

### Notes:
- The case printed is a modified rotated case, with a thicker bottom
- Almost all of the cases are a bit deformed, that's normal, as the whole case was in the "warning" section, as it's thin everywhere. They are still usable, sometimes some tools are needed to adjust them (hot glue, dremel, hot air, forge, file(the tool), death star)
- It's really cheap, just shipping costs a lot
- Toleramces are tough anyway, order only checked design that you are sure about

Invidual notes for choosen technologies:

**Titanium TC4:**
- The surface is not perfect but good enough, anodyzing, electro polish is also an option for chemistry knowing people
- It conducts electricity, so it's advised to coat it with something in the inside. I did with nail polish, but it turned sluggish and yellow so I removed it (works so far, but assemble was stressfull, not advised), but the process was fun:

https://github.com/user-attachments/assets/9837bda7-dd3d-4c27-bf5d-23caa2c6a187

- Top cover is not possible, as it's metal, obviously
- Motor place needed to be dremelled to fit the motor, so needs more adjusting if anyone plans to order it (as nothing will bend even a little)
- The only case where a deformation hurts the most, luckly it fitted for me
- Wifi signal is 30% worse, so still perfectly usable

**SLA 8001 Resin transparent:**
- It looks the best, it's perfect quality
- A bit on the squishy side :D
- ~~I hope it doesn't turn yellow at some point~~ It did after 5 months of use. Also it broke on one screen edge, for some reason...

**MJF PA12-HP Nylon:**
- Interesting texture, stiff but solid, cool
- I tried SLS nylon some time ago and the tolerances were horrible. Maybe they fixed it, MJF is fine

**SLA JLC Black Resin:**
- Looks almost perfectly smooth, some places are less smooth then others
- Pretty stiff
- A bit transparent when wall is thin
- but cool anyway
- The front case broke for me after a while of using, so less strong than FDM

**FDM Transparent TPU:**
- The quality is good, but it's FDM soooo don't go with transparent, go with black or something
- Suprisingly expensive compared to others, and it's just regular FDM?

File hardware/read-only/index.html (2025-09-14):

# Yatchy Project Hardware Files

## Yatchy

### Interactive Bill of Materials (iBOM)

- An interactive bill of materials for Yatchy.
  View iBOM

### Schematic (PDF)

- Main schematic in PDF format.
  View PDF

### Schematic (SVG)

- Scalable vector schematic.
  View SVG

## Module Default

### Interactive Bill of Materials (iBOM)

- Interactive bill of materials for the default module.
  View iBOM

### Schematic (PDF)

- Schematic of the default module in PDF format.
  View PDF

### Schematic (SVG)

- Scalable vector schematic of the default module.
  View SVG

## Module BTBMHM

### Interactive Bill of Materials (iBOM)

- Interactive bill of materials for the BTBMHM module.
  View iBOM

### Schematic (PDF)

- Schematic of the BTBMHM module in PDF format.
  View PDF

### Schematic (SVG)

- Scalable vector schematic of the BTBMHM module.
  View SVG

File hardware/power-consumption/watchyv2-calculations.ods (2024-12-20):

Power consumptions in certain situations | uA | in ms | Whole time took, ms |  | settings | value | other
Full sleep | 130 | - | 3438000 |  | Wakeups per hour | 60 | Whole time 1h in ms | 3600000
hp core update | 32500 | 2700 | 162000 |  | Battery capacity In mAh | 200
Final power consumption in uA: | 1586.65
Battery life in h | 126.052 |  |  | calculations
Battery life formatted | 0 months, 5 days 6.1 h |  |  |  | uA x time
 |  |  |  |  | 446940000
 |  |  |  |  | 5265000000
 |  |  |  | Sum | 5711940000

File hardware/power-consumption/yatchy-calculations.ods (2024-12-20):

Power consumptions in certain situations | uA | in ms | Whole time took, ms |  | settings | value | other
Full sleep | 44 | - | 3550000 |  | Wakeups every x minutes | 29 | Whole time 1h in ms | 3600000
Regular lp core time update | 2800 | 500 | 28000 |  | Battery capacity In mAh | 200
First time update lp core | 2500 | 7500 | 15000
hp core update | 16000 | 3500 | 7000
Final power consumption in uA: | 106.694
Battery life in h | 1874.52 |  |  | calculations
Battery life formatted | 2 months, 18 days 2.5 h |  |  |  | wakeups in hour | 2
 |  |  |  |  | uA x time
 |  |  |  |  | 156200000
 |  |  |  |  | 78400000
 |  |  |  |  | 37500000
 |  |  |  |  | 112000000
 |  |  |  | Sum | 384100000

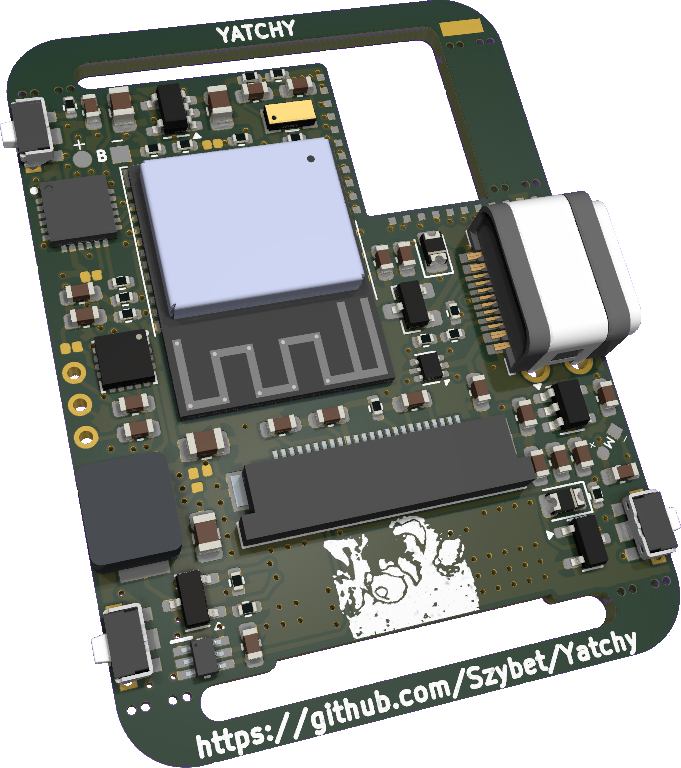
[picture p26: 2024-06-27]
img/Yatchy.png

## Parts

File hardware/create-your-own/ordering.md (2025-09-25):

## **A reminder, all of this is provided without any warranty. If something goes wrong and the PCB is bad, wrong components, not my fault**

# Ordering components & Price
There is a spreadsheet for it: https://github.com/Szybet/Yatchy/blob/main/hardware/components-calc.ods

**I already miscalculated the components in this spreadsheet a few times, so here is another disclaimer for you:**

While it's scary, simply checking with the latest Kicad files is a good idea anyway.

You need to adjust all values for yourself, after that it will give you a approximation of how much will it cost. Why it's not precise?
- Sometimes you need to order 1 component where the minimum is 5, so you order 5 (That's the case with pcb's)
- Sometimes it's advised to buy spare components if you screw something up (I Usually buy spares for all of them)
- Sometimes when ordering minimum + spares you hit the next price point, then it drops
- Sometimes, prices change
- Random taxes, discounts, shipping magic etc.
- Ordering things for more than 1 yatchy will make things cheaper, again, price tresholds, again, economy of scale (Small scale but scale). Also shipping will be splitteb between yatchies

So it's save to say it's precise up to +-15$, maybe even 20$

If you feel extra insecure and you don't trust me **(You shouldn't)** check the kicad files if the document misses a component

For me, the cost is arround 70-80$, without the labour and things like solder / flux

Also to note, mauser is not required, I was able to buy everything with TME + falstad (Without the accelerometer, lol). Also digikey looks like it has all the components

#### Note about accelerometers
the PCB supports both BMA530 and BMA456 (even BMA423... but this one is impossible to get). Generally, only BMA456 is suggested, the BMA530 is there as a backup if BMA456 is not available. Sadly, BMA530 is harder to solder, it's basically BGA (but BMA530 is 2 times more precise than BMA456, while BMA456 is 2 times more precise than BMA423 - the precission doesn't really matter for normal usage / step tracking)

### Choosing alternative components
If you want to choose alternative components (we are talking about capacitors / resistors, for transistors etc. you are on your own) follow this:
1. Follow the excel file, not the BOM file.
2. Generally, 5% tolerance is good, but there are exceptions:
- For the quartz capacitors, get the max possible tolerance (1%?)
- For screen circuit things, get better tolerances if it doesn't cost you much, because if something will not work, it will be hell to debug

### Motor
There is no dedicated place for the vibration motor. So it's simply yeet it on top of components (Isolation in between!). Also a small one is advised. I bought these ones: https://aliexpress.com/item/1005004948677826.html smallest ones I could find, they work, they do their job

# Ordering the PCB
### Warning
The PCB you are ordering might not be real life tested as I apply patches regularly but I don't order them, so as everything, all of this is provided without any warranty 

1. Install kicad version (specified in hardware/README.md) or later
2. Install this plugin https://github.com/bouni/kicad-jlcpcb-tools
3. Clone the repo / open the pcb project so you will see something like this (PCB on the pic is outdated)
- Of you don't understand the above, here is a step by step:
   - Get all the files from this repo, for example like this (Download zip)



   - Extract it
   - Open in kicad the file "Yatchy.kicad_pro"
   - Then in kicad open the pcb file



4. Click this:



5. Click this



6. Now in the logs you will see where the magic zip file is



7. Log into JLCPCB with an account
8. Go to https://jlcpcb.com/ and add the zip file



9. You should see something like this



10. Now make sure those settings are matched:
- Layers: 4
- PCB Thickness: 1.0mm
- Mark on PCB: Remove mark (If it charges you more money for this option, then just switch back to Order number)

The rest defaults should be fine, but you can explore and check if everything is fine. A huge red flag is when it costs a lot (>12$ let's say), it shouldn't.

Now repeat the process with the module you want to attach, then order them rogether (The default module is here: https://github.com/Szybet/Yatchy/tree/main/hardware/kicad/modules/default)

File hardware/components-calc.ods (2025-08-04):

Component | component name | Quantity for one Yatchy | Price for one in $ (at lowest quantity price from mouser) | Price of components For one yatchy | tme link | mouser links
MCU | ESP32-C6-MINI-1-N4 | 1 | $2.51 | $2.51 | https://www.tme.eu/pl/details/esp32-c6-mini-1-n4/moduly-iot-wifi-bluetooth/espressif/ | https://www.mouser.com/ProductDetail/Espressif-Systems/ESP32-C6-MINI-1-N4?qs=Jm2GQyTW%2FbjiJX9bVadqSw%3D%3D
voltage regulator | TLV75533PDBVR | 1 | $0.32 | $0.32 | https://www.tme.eu/pl/details/tlv75533pdbvr/stabilizatory-napiecia-nieregulowane-ldo/texas-instruments/ | https://www.mouser.com/ProductDetail/Texas-Instruments/TLV75533PDBVR?qs=55YtniHzbhAKEwqeO2xJXQ%3D%3D | https://eu.mouser.com/ProductDetail/Texas-Instruments/TLV75733PDYDR?qs=ZcfC38r4PovvOY4HwNOrpQ%3D%3D | better alternative
Flex connector | SFV24R-4STBE1HLF/C | 1 | $0.48 | $0.48 | https://www.tme.eu/pl/details/sfv24r-4stbe1hlf_c/zlacza-ffc-fpc-raster-0-5mm/amphenol-communications-solutions/sfv24r-4stbe1hlf/ | https://www.mouser.com/ProductDetail/Amphenol-FCI/SFV24R-4STBE1HLF?qs=QjFvEcVG8GQ6%252BQ2kqwpo9g%3D%3D
TVS diodes | STS521050B331 | 3 | $0.27 | $0.81 | https://www.tme.eu/pl/details/sts521050b331-ea/diody-tvs-smd-dwukierunkowe/eaton-electric/sts521050b331/ | https://www.mouser.com/ProductDetail/Eaton-Electronics/STS521050B331?qs=DPoM0jnrROWVGwJAwV8sJA%3D%3D
usb c connector | USB4730-GF-A-KIT | 1 | $2.43 | $2.43 | https://www.tme.eu/pl/details/usb4730-gf-a-kit/zlacza-usb-i-ieee1394/global-connector-technology-gct/ | https://www.mouser.com/ProductDetail/GCT/USB4730-GF-A-KIT?qs=Z%252BL2brAPG1IoU%252BBwnQ%2FE8Q%3D%3D
Battery charger | MCP73831T-2ATI/OT | 1 | $0.76 | $0.76 | https://www.tme.eu/pl/details/mcp73831t-2ati_ot/kontrolery-baterii-i-akumulatorow-uklady/microchip-technology/ | https://www.mouser.com/ProductDetail/Microchip-Technology/MCP73831T-2ATI-OT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
Buttons | EVPAKE31A | 4 | $0.57 | $2.28 | https://www.tme.eu/pl/details/evpake31a/mikroprzelaczniki-tact/panasonic/ | https://www.mouser.com/ProductDetail/Panasonic/EVP-AKE31A?qs=EU6FO9ffTwe%252BJzX5LvvHqA%3D%3D
0,1µF/25V capacitor | CC0603KRX7R8104 | 5 | $0.10 | $0.50 | https://www.tme.eu/pl/details/cc0603krx7r8104/kondensatory-mlcc-smd/yageo/cc0603krx7r8bb104/ | https://www.mouser.com/ProductDetail/YAGEO/CC0603KRX7R8BB104?qs=AgBp2OyFlx%252B4QOgEm%2Fb3YQ%3D%3D
4,7µF/50V capacitor | CL21A475KBQNNNE | 4 | $0.20 | $0.80 | https://www.tme.eu/pl/details/cl21a475kbqnnne/kondensatory-mlcc-smd/samsung/ | https://www.mouser.com/ProductDetail/Samsung-Electro-Mechanics/CL21A475KBQNNNE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
1µF/50V capacitor | C1608X5R1H105KAB | 10 | $0.14 | $1.40 | https://www.tme.eu/pl/details/c1608x5r1h105kab/kondensatory-mlcc-smd/tdk/c1608x5r1h105k080ab/ | https://www.mouser.com/ProductDetail/TDK/C1608X5R1H105K080AB?qs=NRhsANhppD%252BLmxnPDqAv3A%3D%3D
10µF/25V capacitor | GRM188R61E106KA73J | 1 | $0.28 | $0.28 | https://www.tme.eu/pl/details/grm188r61e106ka73j/kondensatory-mlcc-smd/murata/ | https://www.mouser.com/ProductDetail/Murata-Electronics/GRM188R61E106KA73J?qs=5aG0NVq1C4xEV8YyiSS7mg%3D%3D
18pF/50V capacitor | 04025A180FAT2A | 2 | $0.50 | $1.00 | https://www.tme.eu/pl/details/04025a180fat2a/kondensatory-mlcc-smd/kyocera-avx/ | https://www.mouser.com/ProductDetail/KYOCERA-AVX/04025A180FAT2A?qs=tGdZP2ZdRP3fTrCUmwWkrw%3D%3D
5.1k/0.1W resistor | ERJ2GEJ512X | 5 | $0.10 | $0.50 | https://www.tme.eu/pl/details/erj2gej512x/rezystory-smd/panasonic/ | https://www.mouser.com/ProductDetail/Panasonic/ERJ-2GEJ512X?qs=H7k1u0Mp9JRPI6U5wQ9G8w%3D%3D
10k/62.5mW resistor | AA0402JR-0710KL | 2 | $0.10 | $0.20 | https://www.tme.eu/pl/details/aa0402jr-0710kl/rezystory-smd/yageo/ | https://www.mouser.com/ProductDetail/YAGEO/AA0402JR-0710KL?qs=xr7y9OPABx3CCYSFp51edw%3D%3D
1k/0.1W resistor | ERJ2GEJ102X | 2 | $0.10 | $0.20 | https://www.tme.eu/pl/details/erj2gej102x/rezystory-smd/panasonic/ | https://www.mouser.com/ProductDetail/Panasonic/ERJ-2GEJ102X?qs=6%252BUraArZVSD3KiPIyQqOzg%3D%3D
806k/0.1W resistor | ERJ2RKF8063X | 2 | $0.10 | $0.20 | https://www.tme.eu/pl/details/erj2rkf8063x/rezystory-smd/panasonic/ | https://www.mouser.com/ProductDetail/Panasonic/ERJ-2RKF8063X?qs=iBwFsHVUAOfyQY3B09OGhA%3D%3D
300k/0.1W resistor | ERJ2RKF3003X | 1 | $0.10 | $0.10 | https://www.tme.eu/pl/details/erj2rkf3003x/rezystory-smd/panasonic/ | https://www.mouser.com/ProductDetail/Panasonic/ERJ-2RKF3003X?qs=YMBIwoNQYdWIe2pK7q5euA%3D%3D
10M/0.1W resistor | ERJ2GEJ106X | 1 | $0.10 | $0.10 | https://www.tme.eu/pl/details/erj2gej106x/rezystory-smd/panasonic/ | https://www.mouser.com/ProductDetail/Panasonic/ERJ-2GEJ106X?qs=6%252BUraArZVSBCZmk3hNWmDQ%3D%3D
100k/0.1W resistor | ERJ2GEJ104X | 5 | $0.10 | $0.50 | https://www.tme.eu/pl/details/erj2gej104x/rezystory-smd/panasonic/ | https://www.mouser.com/ProductDetail/Panasonic/ERJ-2GEJ104X?qs=6%252BUraArZVSCJP%2FfQqKULtw%3D%3D
3/0.1W resistor | ERJ2GEJ3R0X | 1 | $0.10 | $0.10 | https://www.tme.eu/pl/details/erj2gej3r0x/rezystory-smd/panasonic/ | https://www.mouser.com/ProductDetail/Panasonic/ERJ-2GEJ3R0X?qs=YMBIwoNQYdVf89MEAo18sQ%3D%3D
10uH/2.1A inductor | HPI0530-100 | 1 | $0.40 | $0.40 | https://www.tme.eu/pl/details/hpi0530-100/dlawiki-smd-mocy/ferrocore/ | https://www.mouser.com/ProductDetail/Vishay/IFSC2020BZER100M01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
3 schotchy diodes | BAT54TW-7-F | 2 | $0.32 | $0.64 | https://www.tme.eu/pl/details/bat54tw-7-f/diody-schottky-smd/diodes-incorporated/ | https://www.mouser.com/ProductDetail/Diodes-Incorporated/BAT54TW-7-F?qs=L5VEu7YQllu6J%252BSuuoewUw%3D%3D
N-Mosfet | AO3400A | 1 | $0.39 | $0.39 | https://www.tme.eu/pl/details/ao3400a/tranzystory-z-kanalem-n-smd/alpha-omega-semiconductor/ | https://www2.mouser.com/ProductDetail/Diodes-Incorporated/DMN3052L?qs=Ledwo0gu0jj5VJliI6LTSw%3D%3D | https://eu.mouser.com/ProductDetail/Infineon-Technologies/IRLML6344TRPBF?qs=9%2BKlkBgLFf2w4qS48UOXVw%3D%3D | possible replacement not checked
P-Mosfet | FDN304PZ | 1 | $0.88 | $0.88 | https://www.tme.eu/pl/details/fdn304pz/tranzystory-z-kanalem-p-smd/onsemi/ | https://www.mouser.com/ProductDetail/onsemi-Fairchild/FDN304PZ?qs=MA%252B40jw2YMpyjgZQyVD8yA%3D%3D
Crystal | 9HT10D-32.768KDZF | 1 | $0.52 | $0.52 | https://www.tme.eu/pl/details/9ht10d-32.768kdzf/rezonatory-kwarcowe-smd/txc/9ht10d-32-768kdzf-t/ | Untested → | https://www2.mouser.com/ProductDetail/ECS/ECX-.327-CDX-1293?qs=Mv7BduZupUhhIpiFqP8JVA%3D%3D
NPN transistor | BC817-25,215 | 1 | $0.10 | $0.10 | https://www.tme.eu/pl/details/bc817-25.215/tranzystory-npn-smd/nexperia/bc817-25-215/ | https://www.mouser.com/ProductDetail/Nexperia/BC817-25215?qs=me8TqzrmIYUj67JkTBzlfg%3D%3D
Gpio expander | MCP23018-E/MJ | 1 | $2.40 | $2.40 | -- | https://www.mouser.com/ProductDetail/Microchip-Technology/MCP23018-E-MJ?qs=rTzW0HAgjYMWkSwZCYFBCg%3D%3D
rgb | CLMVC-FKA-CL1D1L71BB7C3C3 | 1 | $0.23 | $0.23 | -- | https://www.mouser.com/ProductDetail/Cree-LED/CLMVC-FKA-CL1D1L71BB7C3C3?qs=fSnNYG2PaKLJAXXrLOgMiQ%3D%3D
300/62.5mW resistor | AC0402JR-07330RL | 3 | $0.10 | $0.30 | https://www.tme.eu/pl/details/erj2gej301x/rezystory-smd/panasonic/ | https://www.mouser.com/ProductDetail/YAGEO/AC0402JR-07330RL?qs=ygRr%2FtkhtetxWVqYupgf1A%3D%3D
BMA456 or BMA530 |  | 1 | $1.66 | $1.66 | -- | httpshttps://www.mouser.com/ProductDetail/Bosch-Sensortec/BMA530 or
screen | GDEY0154D67 | $8.21 | YOU SHOULD STILL CHECK WITH THE LATEST KICAD FILES THIS IS JUST A APPROXIMATION DON’T ORDER COMPONENTS BASED ONLY ON THIS DO ANYTHING (ORDERING) AT YOUR OWN RISK!
screen shipping |  | $2.22
pcb |  | $2.63
pcb shipping |  | $9.98
battery |  | $4.19
battery shipping |  | $0.00
Tax | 23.00%
Tax price | $5.29
Shipping cost Of components | $10.00
Price of only components Without tax | $23.00
Price of only components With Tax | $28.29
price with tax and Pcb screen and battery | $43.32
Price of all with shipping | $65.52
assembly cost | $30.00
final shipping cost | $10.00
Final price | $105.52

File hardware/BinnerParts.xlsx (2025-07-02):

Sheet: Parts
PartId | Quantity | LowStockThreshold | Cost | Currency | PartNumber | DigiKeyPartNumber | MouserPartNumber | ArrowPartNumber | TmePartNumber | Description | PartTypeId | MountingTypeId | PackageType | ProductUrl | ImageUrl | LowestCostSupplier | LowestCostSupplierUrl | ProjectId | Keywords | DatasheetUrl | Location | BinNumber | BinNumber2 | Manufacturer | ManufacturerPartNumber | SwarmPartNumberManufacturerId | UserId | SymbolName | FootprintName | ExtensionValue1 | ExtensionValue2 | DateCreatedUtc
37542 | 0 | 5 | 0.1 | USD | 100nF |  | CC0603KRX7R8BB104 |  |  | 0.1uF | 2 | 2 |  | https://www.mouser.com/ProductDetail/YAGEO/CC0603KRX7R8BB104?qs=AgBp2OyFlx%252B4QOgEm%2Fb3YQ%3D%3D | https://www.mouser.com/images/vishay/images/VJ_Commercial_DSL.JPG | Mouser | https://www.mouser.ca/ProductDetail/TAIYO-YUDEN/MAJCU168BB7104KTEA01?qs=ZcfC38r4PovJ4zMRJqa98Q%3D%3D | 0 |  |  |  |  |  |  | CC0603KRX7R8BB104 | 0 | 14319 |  |  |  |  | 2025-05-13 15:44
37543 | 0 | 1 | 0.28 | USD | 10uF |  | GRM188R61E106KA73J |  |  |  | 2 | 2 |  | https://www.mouser.com/ProductDetail/Murata-Electronics/GRM188R61E106KA73J?qs=5aG0NVq1C4xEV8YyiSS7mg%3D%3D | https://www.mouser.com/images/murata/images/GCM_series_SPL.jpg | Mouser | https://www.mouser.ca/ProductDetail/KYOCERA-AVX/KGM05CS60J106MH?qs=9vOqFld9vZXSfhl2b2Q2gQ%3D%3D | 0 |  |  |  |  |  | Murata Electronics | GRM188R61E106KA73J | 0 | 14319 |  |  |  |  | 2025-05-12 22:14
37544 | 0 | 2 | 0.5 | USD | 18pF |  | 04025A180FAT2A |  |  |  | 2 | 2 |  | https://www.mouser.com/ProductDetail/KYOCERA-AVX/04025A180FAT2A?qs=tGdZP2ZdRP3fTrCUmwWkrw%3D%3D |  |  |  | 0 |  |  |  |  |  |  | 04025A180FAT2A | 0 | 14319 |  |  |  |  | 2025-05-12 22:18
37545 | 0 | 10 | 0.14 | USD | 1uF |  | C1608X5R1H105KAB |  |  |  | 2 | 2 |  | https://www.mouser.com/ProductDetail/TDK/C1608X5R1H105K080AB?qs=NRhsANhppD%252BLmxnPDqAv3A%3D%3D |  |  |  | 0 |  |  |  |  |  |  | C1608X5R1H105KAB | 0 | 14319 |  |  |  |  | 2025-05-12 22:20
37546 | 0 | 4 | 0.2 | USD | 4.7uF |  | CL21A475KBQNNNE |  |  |  | 2 | 2 |  | https://www.mouser.com/ProductDetail/Samsung-Electro-Mechanics/CL21A475KBQNNNE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 |  |  |  | 0 |  |  |  |  |  |  | CL21A475KBQNNNE | 0 | 14319 |  |  |  |  | 2025-05-12 22:21
37548 | 0 | 1 | 0.32 | USD | TLV75533PDBVR | 296-50411-1-ND | TLV75533PDBVR |  |  | IC REG LINEAR 3.3V 500MA SOT23-5 Linear Voltage Regulator IC Positive Fixed 1 Output 500mA SOT-23-5 | 27 | 2 |  | https://www.mouser.com/ProductDetail/Texas-Instruments/TLV75533PDBVR?qs=55YtniHzbhAKEwqeO2xJXQ%3D%3D | https://mm.digikey.com/Volume0/opasdata/d220001/medias/images/5790/296%7E4214839%7EDBV%7E5_.jpg | DigiKey | https://www.digikey.pl/en/products/detail/texas-instruments/TLV75533PDBVR/9356541 | 0 |  |  |  |  |  | Texas Instruments | TLV75533PDBVR | 0 | 14319 |  |  |  |  | 2025-05-13 16:28
37549 | 0 | 2 | 0.48 | USD | SFV24R-4STBE1HLF | 609-5202-1-ND | SFV24R-4STBE1HLF/C |  |  | CONN FPC TOP 24POS 0.5MM R/A 24 Position FPC Connector Contacts, Top 0.020" (0.50mm) Surface Mount, Right Angle | 13 | 2 |  | https://www.digikey.pl/en/products/detail/amphenol-cs-fci/SFV24R-4STBE1HLF/4270657 | https://mm.digikey.com/Volume0/opasdata/d220001/medias/images/2266/SFV24R-4STBE1HLF.JPG | DigiKey | https://www.digikey.pl/en/products/detail/amphenol-cs-fci/SFV24R-4STBE1HLF/4270657 | 0 | connector,mount,sfv24r-4stbe1hlf,conn,fpc,top,24pos,none | https://cdn.amphenol-cs.com/media/wysiwyg/files/documentation/datasheet/flex/flexconnectors_050mm_sfvr.pdf |  |  |  | Amphenol ICC (FCI) | SFV24R-4STBE1HLF | 0 | 14319 |  |  |  |  | 2025-05-13 16:17
37550 | 0 | 3 | 0.27 | USD | STS521050B331 | 283-STS521050B331CT-ND |  |  |  | TVS DIODE 5VWM 18VC SOD523 18V Clamp 20A (8/20µs) Ipp Tvs Diode Surface Mount SOD-523 | 73 | 2 | SC-79, SOD-523 | https://www.mouser.com/ProductDetail/Eaton-Electronics/STS521050B331?qs=DPoM0jnrROWVGwJAwV8sJA%3D%3D | https://mm.digikey.com/Volume0/opasdata/d220001/medias/images/6295/283%7ESOD523%7E%7E2.jpg | DigiKey | https://www.digikey.pl/en/products/detail/eaton-electronics-division/STS521050B331AH/24612361 | 0 | diode,ic,mount,sts521050b331,tvs,5vwm,18vc,sod523,surfacemount |  |  |  |  | Eaton - Electronics Division | STS521050B331 | 0 | 14319 |  |  |  |  | 2025-05-13 16:20
37551 | 0 | 1 | 2.51 | USD | ESP32-C6-MINI-1-N4 | 1965-ESP32-C6-MINI-1-N4CT-ND | ESP32-C6-MINI-1-N4 |  |  | RF TXRX MOD BT WIFI PCB TH SMD 802.15.4, Bluetooth, WiFi 802.11ax, Bluetooth v5.0, Zigbee® Transceiver Module 2.4GHz PCB Trace Surface Mount | 15 | 2 | 53-SMD Module | https://www.mouser.com/ProductDetail/Espressif-Systems/ESP32-C6-MINI-1-N4?qs=Jm2GQyTW%2FbjiJX9bVadqSw%3D%3D | https://mm.digikey.com/Volume0/opasdata/d220001/medias/images/4908/MFG_ESP32-C6-MINI-1-N4.jpg | DigiKey | https://www.digikey.pl/en/products/detail/espressif-systems/ESP32-C6-MINI-1-N4/17885796 | 0 | module,mount,esp32-c6-mini-1-n4,rf,txrx,mod,bt,surfacemount | https://www.espressif.com/sites/default/files/documentation/esp32-c6-mini-1_mini-1u_datasheet_en.pdf |  |  |  | Espressif Systems | ESP32-C6-MINI-1-N4 | 0 | 14319 |  |  |  |  | 2025-05-13 16:26
37552 | 0 | 1 | 0.44 | USD | USBLC6-2P6 | 497-5026-1-ND | USBLC6-2P6 |  |  | Old TVS diode. TVS DIODE 5.25VWM 17VC SOT666 17V Clamp 5A (8/20µs) Ipp Tvs Diode Surface Mount SOT-666 | 73 | 2 | SOT-563, SOT-666 | https://www.mouser.pl/ProductDetail/STMicroelectronics/USBLC6-2P6?qs=6ARB0lp6jlViGcbUSvj1Mw%3D%3D | https://mm.digikey.com/Volume0/opasdata/d220001/medias/images/4837/USBLC6-2P6.JPG | DigiKey | https://www.digikey.pl/en/products/detail/stmicroelectronics/USBLC6-2P6/1007440 | 0 | diode,ic,mount,usblc6-2p6,tvs,5.25vwm,17vc,sot666,surfacemount | https://www.st.com/content/ccc/resource/technical/document/datasheet/06/1d/48/9c/6c/20/4a/b2/CD00050750.pdf/files/CD00050750.pdf/jcr:content/translations/en.C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 |  |  |  | STMicroelectronics | USBLC6-2P6 | 0 | 14319 |  |  |  |  | 2025-05-13 16:19
37553 | 0 | 1 | 2.43 | USD | USB4730-GF-A-KIT | 2073-USB4730-GF-A-KITCT-ND | USB4730-GF-A-KIT |  |  | USB 2.0 TYPE C RECEPTACLE KIT, G USB-C (USB TYPE-C) USB 2.0 Receptacle Connector 24 (16+8 Dummy) Position Surface Mount, Right Angle; Through Hole | 13 | 1 |  | https://www.mouser.com/ProductDetail/GCT/USB4730-GF-A-KIT?qs=Z%252BL2brAPG1IoU%252BBwnQ%2FE8Q%3D%3D | https://mm.digikey.com/Volume0/opasdata/d220001/medias/images/5731/MFG_2073-USB4730-GF-A-KIT.jpg | DigiKey | https://www.digikey.pl/en/products/detail/gct/USB4730-GF-A-KIT/21838842 | 0 | connector,kit,mount,usb4730-gf-a-kit,usb,2.0,type,c,none | https://gct.co/files/drawings/USB4730.pdf |  |  |  | GCT | USB4730-GF-A-KIT | 0 | 14319 |  |  |  |  | 2025-05-13 16:16
37554 | 0 | 1 | 0.76 | USD | MCP73831T-2ATI/OT | MCP73831T-2ATI/OTCT-ND |  |  |  | IC BATT CNTL LI-ION 1CEL SOT23-5 Charger IC Lithium Ion/Polymer SOT-23-5 | 34 | 2 | SC-74A, SOT-753 | https://www.digikey.pl/en/products/detail/microchip-technology/MCP73831T-2ATI-OT/964303 | https://mm.digikey.com/Volume0/opasdata/d220001/medias/images/6658/150%7EC04-091%7ECT%2COT%7E5.jpg | DigiKey | https://www.digikey.pl/en/products/detail/microchip-technology/MCP73831T-2ATI-OT/964303 | 0 | ic,mcp73831t-2ati/ot,batt,cntl,li-ion,1cel,surfacemount | https://ww1.microchip.com/downloads/en/DeviceDoc/MCP73831-Family-Data-Sheet-DS20001984H.pdf |  |  |  | Microchip Technology | MCP73831T-2ATI/OT | 0 | 14319 |  |  |  |  | 2025-05-13 16:17
37555 | 0 | 4 | 0.59 | USD | EVPAKE31A | P123437CT-ND | EVPAKE31A |  |  | SWITCH TACTILE SPST-NO 0.02A 15V Tactile Switch SPST-NO Side Actuated Surface Mount, Right Angle | 11 | 1 |  | https://www.mouser.com/ProductDetail/Panasonic/EVP-AKE31A?qs=EU6FO9ffTwe%252BJzX5LvvHqA%3D%3D | https://mm.digikey.com/Volume0/opasdata/d220001/medias/images/903/EVP-AKB11A.JPG | DigiKey | https://www.digikey.pl/en/products/detail/panasonic-electronic-components/EVP-AKE31A/8568272 | 0 | ic,switch,mount,evp-ake31a,tactile,spst-no,0.02a,15v,none | https://www3.panasonic.biz/ac/cdn/e/control/switch/light-touch/catalog/sw_lt_eng_3819s_side.pdf |  |  |  | Panasonic Electronic Components | EVP-AKE31A | 0 | 14319 |  |  |  |  | 2025-05-13 16:15
37556 | 0 | 2 | 0.1 | USD | 806k |  | ERJ2RKF8063X |  |  |  | 1 | 2 |  | https://www.mouser.com/ProductDetail/Panasonic/ERJ-2RKF8063X?qs=iBwFsHVUAOfyQY3B09OGhA%3D%3D | https://mm.digikey.com/Volume0/opasdata/d220001/medias/images/5034/MFG_CR1206FB820KS1.jpg | DigiKey | https://www.digikey.pl/en/products/detail/nextgen-components/CR0603JB5K1S01/18158117 | 0 |  |  |  |  |  |  | ERJ2RKF8063X | 0 | 14319 |  |  |  |  | 2025-05-13 15:52
37557 | 0 | 2 | 0 | USD | 10k |  | AA0402JR-0710KL |  |  |  | 1 | 2 |  | https://www.mouser.com/ProductDetail/YAGEO/AA0402JR-0710KL?qs=xr7y9OPABx3CCYSFp51edw%3D%3D |  |  |  | 0 |  |  |  |  |  |  | AA0402JR-0710KL | 0 | 14319 |  |  |  |  | 2025-05-13 15:51
37558 | 0 | 2 | 0.1 | USD | 1k |  | ERJ2GEJ102X |  |  |  | 1 | 2 |  | https://www.mouser.com/ProductDetail/Panasonic/ERJ-2GEJ102X?qs=6%252BUraArZVSD3KiPIyQqOzg%3D%3D |  |  |  | 0 |  |  |  |  |  |  | ERJ2GEJ102X | 0 | 14319 |  |  |  |  | 2025-05-13 16:06
37559 | 0 | 1 | 0.1 | USD | 300k |  | ERJ2RKF3003X |  |  |  | 1 | 2 |  | https://www.mouser.com/ProductDetail/Panasonic/ERJ-2RKF3003X?qs=YMBIwoNQYdWIe2pK7q5euA%3D%3D |  |  |  | 0 |  |  |  |  |  |  | ERJ2RKF3003X | 0 | 14319 |  |  |  |  | 2025-05-13 15:53
37560 | 0 | 1 | 0.1 | USD | 10M |  | ERJ2GEJ106X |  |  |  | 1 | 2 |  | https://www.mouser.com/ProductDetail/Panasonic/ERJ-2GEJ106X?qs=6%252BUraArZVSBCZmk3hNWmDQ%3D%3D |  |  |  | 0 |  |  |  |  |  |  | ERJ2GEJ106X | 0 | 14319 |  |  |  |  | 2025-05-13 15:50
37561 | 0 | 5 | 0.1 | USD | 100k |  | ERJ2GEJ104X |  |  |  | 1 | 2 |  | https://www.mouser.com/ProductDetail/Panasonic/ERJ-2GEJ104X?qs=6%252BUraArZVSCJP%2FfQqKULtw%3D%3D |  |  |  | 0 |  |  |  |  |  |  | ERJ2GEJ104X | 0 | 14319 |  |  |  |  | 2025-05-13 15:59
37562 | 0 | 1 | 0.1 | USD | 3R |  | ERJ2GEJ3R0X |  |  |  | 1 | 2 |  | https://www.mouser.com/ProductDetail/Panasonic/ERJ-2GEJ3R0X?qs=YMBIwoNQYdVf89MEAo18sQ%3D%3D |  |  |  | 0 |  |  |  |  |  |  | ERJ2GEJ3R0X | 0 | 14319 |  |  |  |  | 2025-05-13 15:47
37563 | 0 | 1 | 0 | USD | 10uH Coil |  | HPI0530-100 |  |  |  | 3 | 2 |  | https://www.mouser.com/ProductDetail/Vishay/IFSC2020BZER100M01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 |  |  |  | 0 |  |  |  |  |  |  | HPI0530-100 | 0 | 14319 |  |  |  |  | 2025-05-13 16:09
37564 | 0 | 2 | 0.32 | USD | 3 schotky diodes |  | BAT54TW-7-F$0.32 |  |  |  | 64 | 2 |  | https://www.mouser.com/ProductDetail/Diodes-Incorporated/BAT54TW-7-F?qs=L5VEu7YQllu6J%252BSuuoewUw%3D%3D |  |  |  | 0 |  |  |  |  |  |  | BAT54TW-7-F | 0 | 14319 |  |  |  |  | 2025-05-13 16:18
37565 | 0 | 1 | 0.46 | USD | AO3400A | 785-1000-1-ND | AO3400A |  |  | MOSFET N-CH 30V 5.7A SOT23-3L N-Channel 30 V 5.7A (Ta) 1.4W (Ta) Surface Mount SOT-23-3 | 75 | 2 | 3-SMD, SOT-23-3 Variant | https://www2.mouser.com/ProductDetail/Diodes-Incorporated/DMN3052L?qs=Ledwo0gu0jj5VJliI6LTSw%3D%3D | https://mm.digikey.com/Volume0/opasdata/d220001/medias/images/6348/785%7EPO-00001%7E%7E3.jpg | DigiKey | https://www.digikey.pl/en/products/detail/evvo/AO3400A-EV/26221089 | 0 | mount,mosfet,ao3400a,n-ch,30v,5.7a,sot23-3l,surfacemount | https://mm.digikey.com/Volume0/opasdata/d220001/medias/docus/1133/AO3400A_ds.pdf |  |  |  | Alpha & Omega Semiconductor Inc. | AO3400A | 0 | 14319 |  |  |  |  | 2025-05-13 16:25
37566 | 0 | 1 | 0.88 | USD | FDN304PZ | FDN304PZCT-ND | FDN304PZ |  |  | MOSFET P-CH 20V 2.4A SUPERSOT3 P-Channel 20 V 2.4A (Ta) 500mW (Ta) Surface Mount SOT-23-3 | 75 | 2 | TO-236-3, SC-59, SOT-23-3 | https://www.mouser.com/ProductDetail/onsemi-Fairchild/FDN304PZ?qs=MA%252B40jw2YMpyjgZQyVD8yA%3D%3D | https://mm.digikey.com/Volume0/opasdata/d220001/medias/images/6164/488%7EMKT-MA03B%7E%7E3.jpg | DigiKey | https://www.digikey.pl/en/products/detail/onsemi/FDN304PZ/975235 | 0 | mount,mosfet,fdn304pz,p-ch,20v,2.4a,supersot3,surfacemount | https://www.onsemi.com/pub/Collateral/FDN304PZ-D.PDF |  |  |  | onsemi | FDN304PZ | 0 | 14319 |  |  |  |  | 2025-05-13 16:25
37567 | 0 | 1 | 0.7 | USD | Quartz ECX-.327-CDX-1293 |  | ECX-.327-CDX-1293 |  |  |  | 9 | 2 |  | https://eu.mouser.com/ProductDetail/ECS/ECX-.327-CDX-1293?qs=Mv7BduZupUhhIpiFqP8JVA%3D%3D | https://mm.digikey.com/Volume0/opasdata/d220001/medias/images/4322/MFG_J31SMT-A-D-K-32K768.jpg | DigiKey | https://www.digikey.pl/en/products/detail/jauch-quartz/J31SMT-A-D-K-32K768/14663444 | 0 |  |  |  |  |  |  |  | 0 | 14319 |  |  |  |  | 2025-05-13 16:13
37568 | 0 | 1 | 0.1 | USD | BC817-25 | 2156-BC817-25LT1-ONTR-ND | BC817-25,215 |  |  | TRANS NPN 45V 0.5A SOT23-3 Bipolar (BJT) Transistor NPN 45 V 500 mA 100MHz 300 mW Surface Mount SOT-23-3 (TO-236) | 6 | 2 | TO-236-3, SC-59, SOT-23-3 | https://www.mouser.com/ProductDetail/Nexperia/BC817-25215?qs=me8TqzrmIYUj67JkTBzlfg%3D%3D | https://mm.digikey.com/Volume0/opasdata/d220001/medias/images/5883/488%7E318-08%7EET%2CL%2CLT%2CSF%2CSN%7E3.jpg | DigiKey | https://www.digikey.pl/en/products/detail/mcc-micro-commercial-components/BC817-25-TP/1959411 | 0 | transistor,mount,bjt,bc817-25lt1,trans,npn,45v,0.5a,surfacemount | https://www.onsemi.com/pdf/datasheet/bc817-16lt1-d.pdf |  |  |  | onsemi | BC817-25LT1 | 0 | 14319 |  |  |  |  | 2025-05-13 16:12
37569 | 0 | 1 | 2.04 | USD | MCP23018-E/MJ | MCP23018-E/MJ-ND | MCP23018-E/MJ |  |  | IC XPNDR 3.4MHZ I2C 24QFN I/O Expander 16 I2C 3.4 MHz 24-QFN (4x4) | 14 | 2 | 24-VFQFN Exposed Pad | https://www.mouser.com/ProductDetail/Microchip-Technology/MCP23018-E-MJ?qs=rTzW0HAgjYMWkSwZCYFBCg%3D%3D | https://mm.digikey.com/Volume0/opasdata/d220001/medias/images/4849/150_24-VFQFN%20Exposed%20Pad.jpg | DigiKey | https://www.digikey.pl/en/products/detail/microchip-technology/MCP23018-E-MJ/1999503 | 0 | ic,mcp23018-e/mj,xpndr,3.4mhz,i2c,24qfn,surfacemount | https://ww1.microchip.com/downloads/aemDocuments/documents/APID/ProductDocuments/DataSheets/MCP23018-Data-Sheet-DS20002103.pdf |  |  |  | Microchip Technology | MCP23018-E/MJ | 0 | 14319 |  |  |  |  | 2025-05-13 16:27
37570 | 0 | 1 | 0.23 | USD | RGB CLMVC-FKA-CL1D1L71BB7C3C3 | CLMVC-FKA-CL1D1L71BB7C3C3CT-ND | CLMVC-FKA-CL1D1L71BB7C3C3 |  |  | LED RGB CLEAR 4PLCC SMD Red, Green, Blue (RGB) 622nm Red, 530nm Green, 470nm Blue LED Indication - Discrete 2V Red, 3V Green, 3V Blue 4-SMD, J-Lead | 5 | 2 | 4-SMD, J-Lead | https://www.mouser.com/ProductDetail/Cree-LED/CLMVC-FKA-CL1D1L71BB7C3C3?qs=fSnNYG2PaKLJAXXrLOgMiQ%3D%3D | https://mm.digikey.com/Volume0/opasdata/d220001/medias/images/902/MFG_CLMVC-FKA-CL1D1L71BB7C3C3.jpg | DigiKey | https://www.digikey.pl/en/products/detail/cree-led/CLMVC-FKA-CL1D1L71BB7C3C3/4794065 | 0 | ic,led,scr,clmvc-fka-cl1d1l71bb7c3c3,rgb,clear,4plcc,smd,surfacemount | https://downloads.cree-led.com/files/ds/h/HB-CLMVC-FKA.pdf |  |  |  | Cree LED | CLMVC-FKA-CL1D1L71BB7C3C3 | 0 | 14319 |  |  |  |  | 2025-05-13 16:10
37571 | 0 | 3 | 0.1 | USD | 330R |  | AC0402JR-07330RL |  |  |  | 1 | 2 |  | https://www.mouser.pl/ProductDetail/YAGEO/AC0402JR-07330RL?qs=ygRr%2FtkhtetxWVqYupgf1A%3D%3D | https://mm.digikey.com/Volume0/opasdata/d220001/medias/images/6585/MFG_CR12JA330R.jpg | DigiKey | https://www.digikey.pl/en/products/detail/yageo/RC0402JR-13330RL/14008183 | 0 |  |  |  |  |  |  | AC0402JR-07330RL | 0 | 14319 |  |  |  |  | 2025-05-13 16:05
37572 | 0 | 1 | 1.96 | USD | BMA456 | 828-1075-1-ND | BMA456 |  |  | ACCEL 2-16G I2C/SPI 12LGA Accelerometer X, Y, Z Axis ±2g, 4g, 8g, 16g 5.06Hz ~ 684Hz 12-LGA (2x2) | 10 | 2 | 12-WFLGA | https://www.mouser.pl/ProductDetail/Bosch-Sensortec/BMA456?qs=sGAEpiMZZMu3sxpa5v1qroZc48vGwABcDz2hlBU72LM%3D | https://mm.digikey.com/Volume0/opasdata/d220001/medias/images/6336/828%7E12LGA-.70-2X2%7E%7E12.jpg | DigiKey | https://www.digikey.pl/en/products/detail/bosch-sensortec/BMA456/7401315 | 0 | sensor,bma456,accel,2-16g,i2c/spi,12lga,surfacemount |  |  |  |  | Bosch Sensortec | BMA456 | 0 | 14319 |  |  |  |  | 2025-05-13 16:13
37601 | 0 | 5 | 0.1 | USD | 5.1k |  | ERJ2GEJ512X |  |  |  | 1 | 2 |  | https://www.mouser.com/ProductDetail/Panasonic/ERJ-2GEJ512X?qs=H7k1u0Mp9JRPI6U5wQ9G8w%3D%3D | https://mm.digikey.com/Volume0/opasdata/d220001/medias/images/639/0805-RMCF-Series.jpg | DigiKey | https://www.digikey.pl/en/products/detail/stackpole-electronics-inc/RMCF0805JT1K10/1757802 | 0 |  |  |  |  |  |  | ERJ2GEJ512X | 0 | 14319 |  |  |  |  | 2025-05-13 16:03

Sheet: PartTypes
PartTypeId | ParentPartTypeId | Name | DateCreatedUtc | UserId | OrganizationId
12 | 0 | Cable | 2022-04-14 21:26 | 0 | 0
2 | 0 | Capacitor | 2022-04-14 21:26 | 0 | 0
13 | 0 | Connector | 2022-04-14 21:26 | 0 | 0
9 | 0 | Crystal | 2022-04-14 21:26 | 0 | 0
4 | 0 | Diode | 2022-04-14 21:26 | 0 | 0
16 | 0 | Evaluation | 2022-04-14 21:26 | 0 | 0
17 | 0 | Hardware | 2022-04-14 21:26 | 0 | 0
14 | 0 | IC | 2022-04-14 21:26 | 0 | 0
3 | 0 | Inductor | 2022-04-14 21:26 | 0 | 0
201 | 0 | Kit | 2022-04-14 21:26 | 0 | 0
5 | 0 | LED | 2022-04-14 21:26 | 0 | 0
15 | 0 | Module | 2022-04-14 21:26 | 0 | 0
18 | 0 | Other | 2022-04-14 21:26 | 0 | 0
7 | 0 | Relay | 2022-04-14 21:26 | 0 | 0
1 | 0 | Resistor | 2022-04-14 21:26 | 0 | 0
10 | 0 | Sensor | 2022-04-14 21:26 | 0 | 0
11 | 0 | Switch | 2022-04-14 21:26 | 0 | 0
8 | 0 | Transformer | 2022-04-14 21:26 | 0 | 0
6 | 0 | Transistor | 2022-04-14 21:26 | 0 | 0
202 | 2 | CapacitorKit | 2022-04-14 21:26 | 0 | 0
39 | 2 | CeramicCapacitor | 2022-04-14 21:26 | 0 | 0
40 | 2 | ElectrolyticCapacitor | 2022-04-14 21:26 | 0 | 0
41 | 2 | FilmCapacitor | 2022-04-14 21:26 | 0 | 0
42 | 2 | MicaCapacitor | 2022-04-14 21:26 | 0 | 0
43 | 2 | NonPolarizedCapacitor | 2022-04-14 21:26 | 0 | 0
45 | 2 | PaperCapacitor | 2022-04-14 21:26 | 0 | 0
199 | 2 | SafetyCapacitor | 2022-04-14 21:26 | 0 | 0
44 | 2 | SupercapacitorCapacitor | 2022-04-14 21:26 | 0 | 0
200 | 2 | TantalumCapacitor | 2022-04-14 21:26 | 0 | 0
46 | 2 | VariableCapacitor | 2022-04-14 21:26 | 0 | 0
74 | 4 | CrystalDiode | 2022-04-14 21:26 | 0 | 0
203 | 4 | DiodeKit | 2022-04-14 21:26 | 0 | 0
69 | 4 | GunnDiode | 2022-04-14 21:26 | 0 | 0
66 | 4 | LargeSignalDiode | 2022-04-14 21:26 | 0 | 0
68 | 4 | PeltierDiode | 2022-04-14 21:26 | 0 | 0
64 | 4 | Schottky | 2022-04-14 21:26 | 0 | 0
67 | 4 | Shockley | 2022-04-14 21:26 | 0 | 0
65 | 4 | SmallSignalDiode | 2022-04-14 21:26 | 0 | 0
71 | 4 | StepRecoveryDiode | 2022-04-14 21:26 | 0 | 0
73 | 4 | TransientVoltageSuppressionDiode | 2022-04-14 21:26 | 0 | 0
70 | 4 | TunnelDiode | 2022-04-14 21:26 | 0 | 0
72 | 4 | VaractorDiode | 2022-04-14 21:26 | 0 | 0
63 | 4 | Zener | 2022-04-14 21:26 | 0 | 0
124 | 16 | Alchitry | 2022-04-14 21:26 | 0 | 0
125 | 16 | Amica | 2022-04-14 21:26 | 0 | 0
119 | 16 | Arduino | 2022-04-14 21:26 | 0 | 0
141 | 16 | AsusTinker | 2022-04-14 21:26 | 0 | 0
132 | 16 | BasicEvaluation | 2022-04-14 21:26 | 0 | 0
120 | 16 | BeagleBoard | 2022-04-14 21:26 | 0 | 0
135 | 16 | LattePanda | 2022-04-14 21:26 | 0 | 0
123 | 16 | Launchpad | 2022-04-14 21:26 | 0 | 0
131 | 16 | MikroElektronika | 2022-04-14 21:26 | 0 | 0
121 | 16 | NVidiaJetson | 2022-04-14 21:26 | 0 | 0
134 | 16 | Odriod | 2022-04-14 21:26 | 0 | 0
142 | 16 | OtherEvaluation | 2022-04-14 21:26 | 0 | 0
126 | 16 | Particle | 2022-04-14 21:26 | 0 | 0
129 | 16 | Pic | 2022-04-14 21:26 | 0 | 0
133 | 16 | Pine | 2022-04-14 21:26 | 0 | 0
140 | 16 | PocketBeagle | 2022-04-14 21:26 | 0 | 0
128 | 16 | Qwiic | 2022-04-14 21:26 | 0 | 0
118 | 16 | RaspberryPi | 2022-04-14 21:26 | 0 | 0
138 | 16 | RockPi | 2022-04-14 21:26 | 0 | 0
136 | 16 | Seeeduino | 2022-04-14 21:26 | 0 | 0
137 | 16 | SiliconLabs | 2022-04-14 21:26 | 0 | 0
127 | 16 | Sparkfun | 2022-04-14 21:26 | 0 | 0
130 | 16 | STM32 | 2022-04-14 21:26 | 0 | 0
122 | 16 | Teensy | 2022-04-14 21:26 | 0 | 0
139 | 16 | Udoo | 2022-04-14 21:26 | 0 | 0
143 | 17 | Adapter | 2022-04-14 21:26 | 0 | 0
150 | 17 | BallBearing | 2022-04-14 21:26 | 0 | 0
158 | 17 | Belt | 2022-04-14 21:26 | 0 | 0
151 | 17 | Bracket | 2022-04-14 21:26 | 0 | 0
149 | 17 | Coupler | 2022-04-14 21:26 | 0 | 0
192 | 17 | Enclosure | 2022-04-14 21:26 | 0 | 0
160 | 17 | Fan | 2022-04-14 21:26 | 0 | 0
148 | 17 | Gear | 2022-04-14 21:26 | 0 | 0
177 | 17 | Grommet | 2022-04-14 21:26 | 0 | 0
159 | 17 | Hub | 2022-04-14 21:26 | 0 | 0
157 | 17 | Mount | 2022-04-14 21:26 | 0 | 0
146 | 17 | Nut | 2022-04-14 21:26 | 0 | 0
155 | 17 | Plate | 2022-04-14 21:26 | 0 | 0
156 | 17 | RawMaterial | 2022-04-14 21:26 | 0 | 0
162 | 17 | Robotics | 2022-04-14 21:26 | 0 | 0
144 | 17 | Screw | 2022-04-14 21:26 | 0 | 0
152 | 17 | Shaft | 2022-04-14 21:26 | 0 | 0
153 | 17 | Spacer | 2022-04-14 21:26 | 0 | 0
176 | 17 | Spring | 2022-04-14 21:26 | 0 | 0
147 | 17 | Standoff | 2022-04-14 21:26 | 0 | 0
154 | 17 | Tube | 2022-04-14 21:26 | 0 | 0
145 | 17 | Washer | 2022-04-14 21:26 | 0 | 0
161 | 17 | Wheel | 2022-04-14 21:26 | 0 | 0
26 | 14 | ADC | 2022-04-14 21:26 | 0 | 0
20 | 14 | Amplifier | 2022-04-14 21:26 | 0 | 0
30 | 14 | AudioIc | 2022-04-14 21:26 | 0 | 0
25 | 14 | ClockIc | 2022-04-14 21:26 | 0 | 0
31 | 14 | ComparatorIc | 2022-04-14 21:26 | 0 | 0
32 | 14 | CounterIc | 2022-04-14 21:26 | 0 | 0
36 | 14 | DataAcquisitionIc | 2022-04-14 21:26 | 0 | 0
33 | 14 | DividerIc | 2022-04-14 21:26 | 0 | 0
37 | 14 | EmbeddedIc | 2022-04-14 21:26 | 0 | 0
28 | 14 | EnergyMeteringIc | 2022-04-14 21:26 | 0 | 0
163 | 14 | FlipFlopIc | 2022-04-14 21:26 | 0 | 0
35 | 14 | FPGA | 2022-04-14 21:26 | 0 | 0
23 | 14 | InterfaceIc | 2022-04-14 21:26 | 0 | 0
29 | 14 | LedDriverIc | 2022-04-14 21:26 | 0 | 0
22 | 14 | LogicIc | 2022-04-14 21:26 | 0 | 0
21 | 14 | MemoryIc | 2022-04-14 21:26 | 0 | 0
24 | 14 | Microcontroller | 2022-04-14 21:26 | 0 | 0
19 | 14 | OpAmp | 2022-04-14 21:26 | 0 | 0
34 | 14 | PMIC | 2022-04-14 21:26 | 0 | 0
38 | 14 | SpecializedIc | 2022-04-14 21:26 | 0 | 0
27 | 14 | VoltageRegulatorIc | 2022-04-14 21:26 | 0 | 0
164 | 3 | AdjustableInductor | 2022-04-14 21:26 | 0 | 0
55 | 3 | AirCoreInductor | 2022-04-14 21:26 | 0 | 0
60 | 3 | BobbinInductor | 2022-04-14 21:26 | 0 | 0
57 | 3 | FerriteCoreInductor | 2022-04-14 21:26 | 0 | 0
204 | 3 | InductorKit | 2022-04-14 21:26 | 0 | 0
56 | 3 | IronCoreInductor | 2022-04-14 21:26 | 0 | 0
58 | 3 | IronPowderInductor | 2022-04-14 21:26 | 0 | 0
59 | 3 | LaminatedCoreInductor | 2022-04-14 21:26 | 0 | 0
62 | 3 | MultiLayerCeramicInductor | 2022-04-14 21:26 | 0 | 0
61 | 3 | ToroidalInductor | 2022-04-14 21:26 | 0 | 0
115 | 15 | ArduinoShield | 2022-04-14 21:26 | 0 | 0
112 | 15 | CurrentVoltageModule | 2022-04-14 21:26 | 0 | 0
116 | 15 | EvaluationModule | 2022-04-14 21:26 | 0 | 0
113 | 15 | ExperimentModule | 2022-04-14 21:26 | 0 | 0
117 | 15 | OtherModule | 2022-04-14 21:26 | 0 | 0
114 | 15 | RaspberryPiShield | 2022-04-14 21:26 | 0 | 0
111 | 15 | WirelessModule | 2022-04-14 21:26 | 0 | 0
81 | 7 | ElectromagneticRelay | 2022-04-14 21:26 | 0 | 0
89 | 7 | HighVoltageRelay | 2022-04-14 21:26 | 0 | 0
82 | 7 | LatchingRelay | 2022-04-14 21:26 | 0 | 0
84 | 7 | ReedRelay | 2022-04-14 21:26 | 0 | 0
88 | 7 | RotaryRelay | 2022-04-14 21:26 | 0 | 0
87 | 7 | SequenceRelay | 2022-04-14 21:26 | 0 | 0
83 | 7 | SolidStateRelay | 2022-04-14 21:26 | 0 | 0
86 | 7 | ThermalRelay | 2022-04-14 21:26 | 0 | 0
85 | 7 | TimeRelay | 2022-04-14 21:26 | 0 | 0
47 | 1 | CarbonFilmResistor | 2022-04-14 21:26 | 0 | 0
193 | 1 | CeramicResistor | 2022-04-14 21:26 | 0 | 0
194 | 1 | CurrentSenseResistor | 2022-04-14 21:26 | 0 | 0
195 | 1 | HighFrequencyResistor | 2022-04-14 21:26 | 0 | 0
48 | 1 | MetalFilmResistor | 2022-04-14 21:26 | 0 | 0
196 | 1 | MetalFoilResistor | 2022-04-14 21:26 | 0 | 0
50 | 1 | MetalOxideResistor | 2022-04-14 21:26 | 0 | 0
51 | 1 | MetalStripResistor | 2022-04-14 21:26 | 0 | 0
198 | 1 | Potentiometer | 2022-04-14 21:26 | 0 | 0
52 | 1 | PowerResistor | 2022-04-14 21:26 | 0 | 0
53 | 1 | ResistorArray | 2022-04-14 21:26 | 0 | 0
197 | 1 | ResistorKit | 2022-04-14 21:26 | 0 | 0
54 | 1 | VariableResistor | 2022-04-14 21:26 | 0 | 0
49 | 1 | WirewoundResistor | 2022-04-14 21:26 | 0 | 0
185 | 10 | AccelerationSensor | 2022-04-14 21:26 | 0 | 0
184 | 10 | AirQualitySensor | 2022-04-14 21:26 | 0 | 0
179 | 10 | AudioSensor | 2022-04-14 21:26 | 0 | 0
107 | 10 | BiometricSensor | 2022-04-14 21:26 | 0 | 0
106 | 10 | CapacitiveSensor | 2022-04-14 21:26 | 0 | 0
167 | 10 | ColorSensor | 2022-04-14 21:26 | 0 | 0
99 | 10 | CurrentSensor | 2022-04-14 21:26 | 0 | 0
102 | 10 | DistanceSensor | 2022-04-14 21:26 | 0 | 0
108 | 10 | EnvironmentSensor | 2022-04-14 21:26 | 0 | 0
170 | 10 | FlowSensor | 2022-04-14 21:26 | 0 | 0
103 | 10 | ForceSensor | 2022-04-14 21:26 | 0 | 0
169 | 10 | GasSensor | 2022-04-14 21:26 | 0 | 0
187 | 10 | GyroscopeSensor | 2022-04-14 21:26 | 0 | 0
182 | 10 | HallEffectSensor | 2022-04-14 21:26 | 0 | 0
168 | 10 | HumiditySensor | 2022-04-14 21:26 | 0 | 0
98 | 10 | ImagingSensor | 2022-04-14 21:26 | 0 | 0
188 | 10 | InclineSensor | 2022-04-14 21:26 | 0 | 0
191 | 10 | InfraredSensor | 2022-04-14 21:26 | 0 | 0
97 | 10 | LightSensor | 2022-04-14 21:26 | 0 | 0
180 | 10 | LiquidSensor | 2022-04-14 21:26 | 0 | 0
101 | 10 | LoadSensor | 2022-04-14 21:26 | 0 | 0
181 | 10 | MagneticSensor | 2022-04-14 21:26 | 0 | 0
105 | 10 | MotionSensor | 2022-04-14 21:26 | 0 | 0
110 | 10 | OtherSensor | 2022-04-14 21:26 | 0 | 0
166 | 10 | Photodiodes | 2022-04-14 21:26 | 0 | 0
186 | 10 | PositionSensor | 2022-04-14 21:26 | 0 | 0
165 | 10 | PressureSensor | 2022-04-14 21:26 | 0 | 0
172 | 10 | ProximitySensor | 2022-04-14 21:26 | 0 | 0
109 | 10 | RadiationSensor | 2022-04-14 21:26 | 0 | 0
104 | 10 | RfSensor | 2022-04-14 21:26 | 0 | 0
96 | 10 | SensorAssembly | 2022-04-14 21:26 | 0 | 0
183 | 10 | SmokeSensor | 2022-04-14 21:26 | 0 | 0
189 | 10 | SpeedSensor | 2022-04-14 21:26 | 0 | 0
173 | 10 | TemperatureSensor | 2022-04-14 21:26 | 0 | 0
171 | 10 | TiltSensor | 2022-04-14 21:26 | 0 | 0
174 | 10 | TouchSensor | 2022-04-14 21:26 | 0 | 0
175 | 10 | UltrasonicSensor | 2022-04-14 21:26 | 0 | 0
190 | 10 | VibrationSensor | 2022-04-14 21:26 | 0 | 0
100 | 10 | VoltageSensor | 2022-04-14 21:26 | 0 | 0
95 | 8 | AudioTransformer | 2022-04-14 21:26 | 0 | 0
92 | 8 | IsolationTransformer | 2022-04-14 21:26 | 0 | 0
94 | 8 | RfTransformer | 2022-04-14 21:26 | 0 | 0
93 | 8 | SolidStateTransformer | 2022-04-14 21:26 | 0 | 0
90 | 8 | StepDownTransformer | 2022-04-14 21:26 | 0 | 0
91 | 8 | StepUpTransformer | 2022-04-14 21:26 | 0 | 0
178 | 6 | BJT | 2022-04-14 21:26 | 0 | 0
79 | 6 | DIAC | 2022-04-14 21:26 | 0 | 0
76 | 6 | IGBT | 2022-04-14 21:26 | 0 | 0
77 | 6 | JFET | 2022-04-14 21:26 | 0 | 0
75 | 6 | MOSFET | 2022-04-14 21:26 | 0 | 0
78 | 6 | SCR | 2022-04-14 21:26 | 0 | 0
80 | 6 | TRIAC | 2022-04-14 21:26 | 0 | 0

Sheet: Projects
ProjectId | Name | Description | Location | Color | Notes | DateCreatedUtc | DateModifiedUtc | UserId

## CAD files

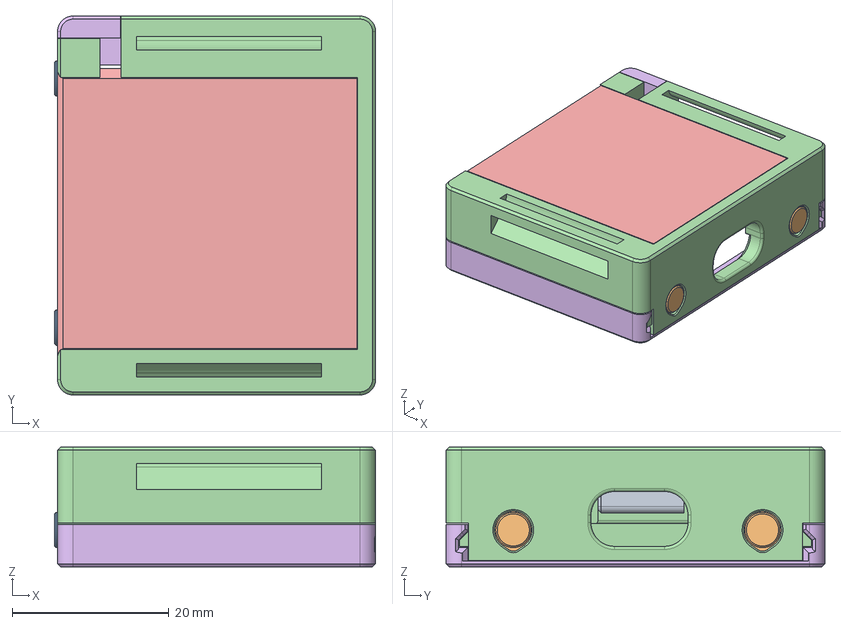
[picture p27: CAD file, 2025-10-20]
3D/cases/glowy-thicc/3D/thicc-case-for-20mm-one-piece-strap.step
41.0 x 48.4 x 15.3 mm
button (1)

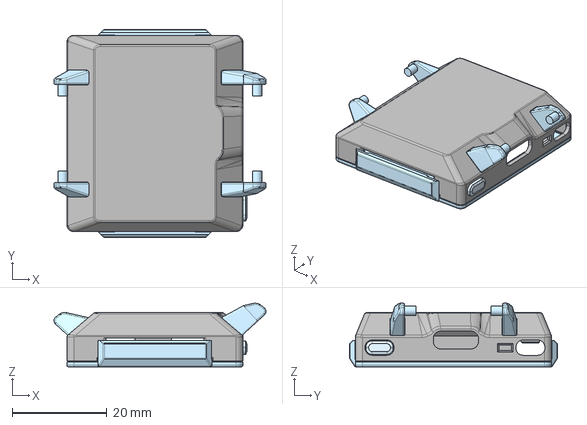
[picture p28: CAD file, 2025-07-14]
3D/cases/Kitkat-rotated/3D/rotated-250mah.step
44.7 x 43.8 x 13.4 mm

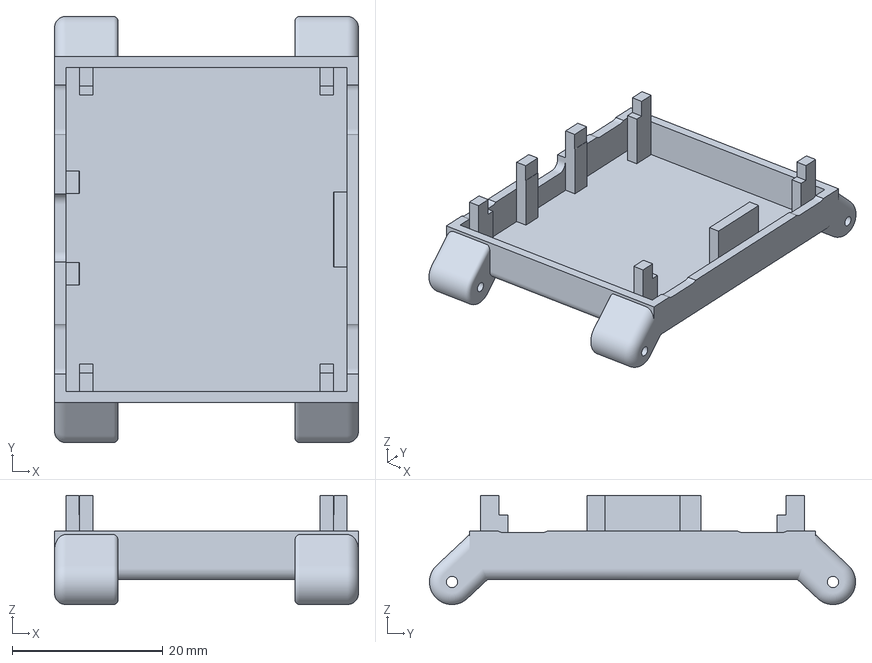
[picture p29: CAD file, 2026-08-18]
3D/cases/Michal-gameboy/3D/michal-gameboy-bottom.3mf
40.4 x 56.6 x 14.5 mm

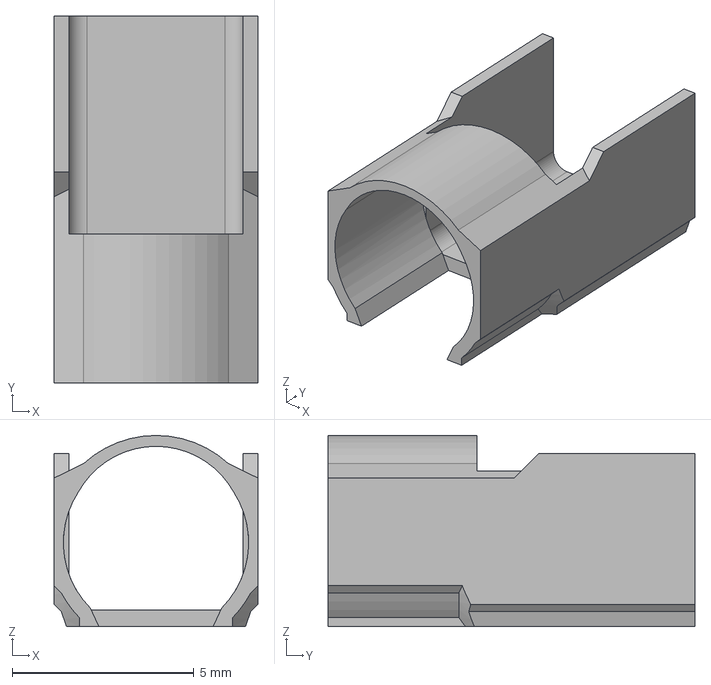
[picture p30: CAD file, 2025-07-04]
3D/cases/patches/1/motor_cover_thinner.step
5.61 x 10.1 x 5.26 mm

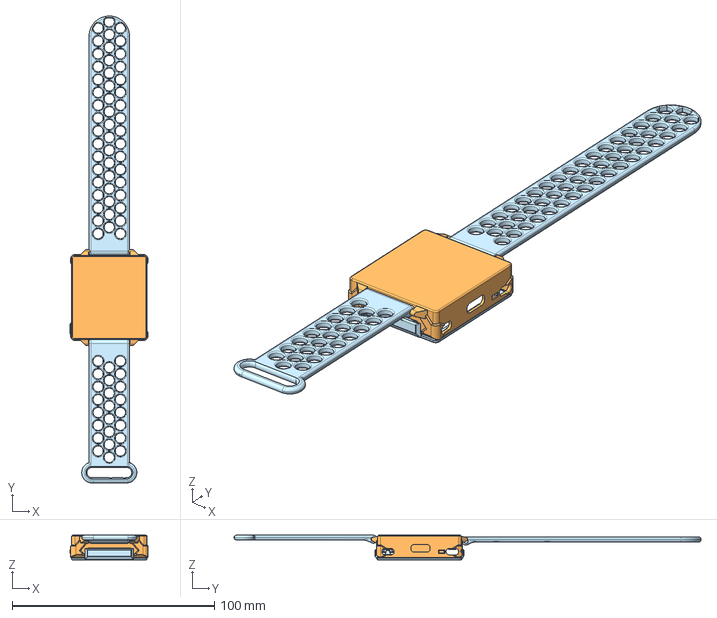
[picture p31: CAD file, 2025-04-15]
3D/cases/Szybet-brick/3D/Brick case for 30x20x5mm.step
38.5 x 230.8 x 12.2 mm

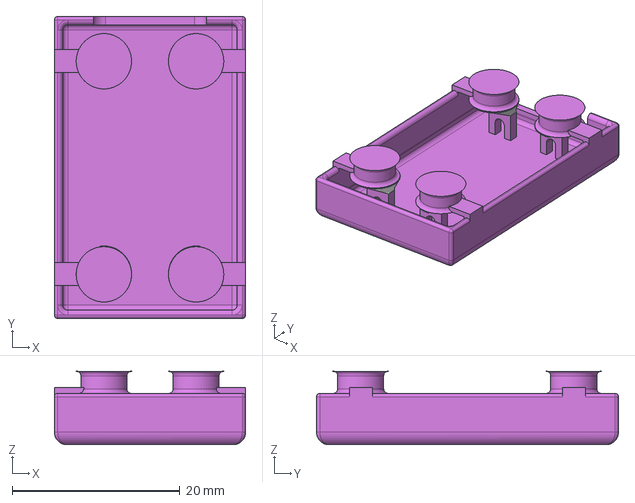
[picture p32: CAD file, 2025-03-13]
3D/cases/Szybet-side/3D/side battery case.step
22.8 x 36.0 x 8.76 mm

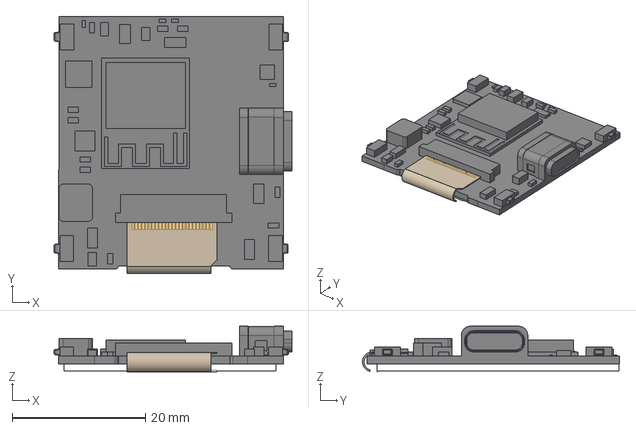
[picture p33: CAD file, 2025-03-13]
3D/pcb/Yatchy_pcb.step
35.7 x 38.6 x 6.85 mm

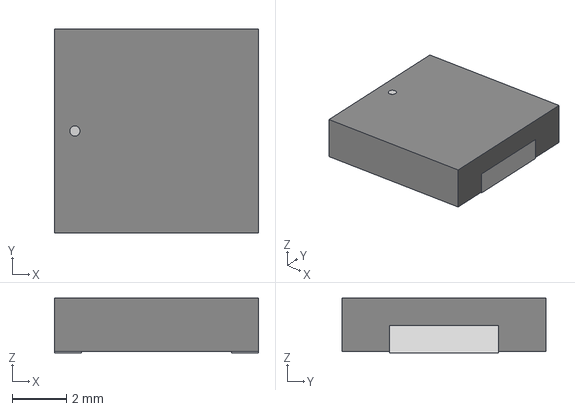
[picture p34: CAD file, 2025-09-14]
hardware/kicad/Yatchy/3d-Models/AST0760_MAL.step
7.49 x 7.49 x 2.01 mm

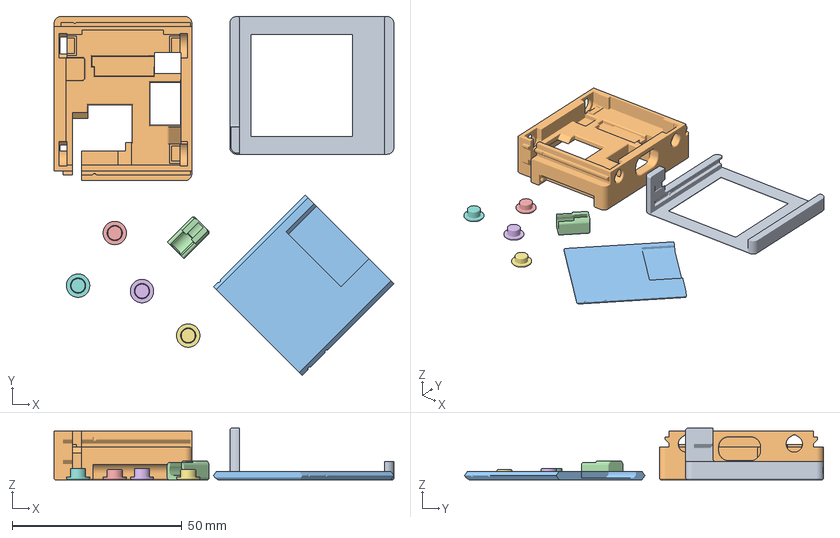
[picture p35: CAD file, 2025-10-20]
3D/cases/glowy-thicc/3D/yatchycase.3mf
100.1 x 105.8 x 15.3 mm
COMPOUND-SOLID-3
COMPOUND-SOLID-1
COMPOUND-SOLID-2
button (1)-SOLID-2
button (1)-SOLID-3
button (1)-SOLID-1
button (1)-SOLID-4

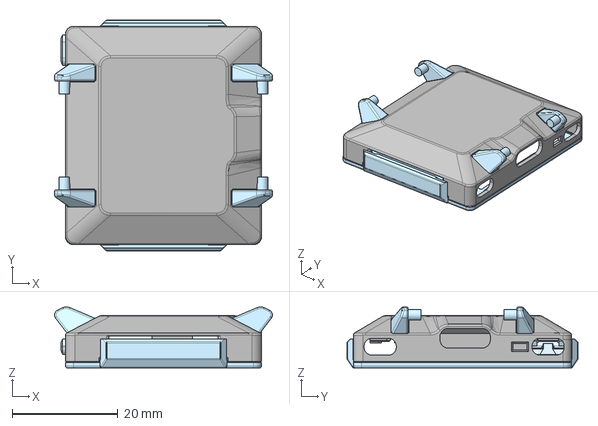
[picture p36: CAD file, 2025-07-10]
3D/cases/Kitkat-rotated/3D/rotated-150mah.step
41.3 x 43.8 x 11.6 mm

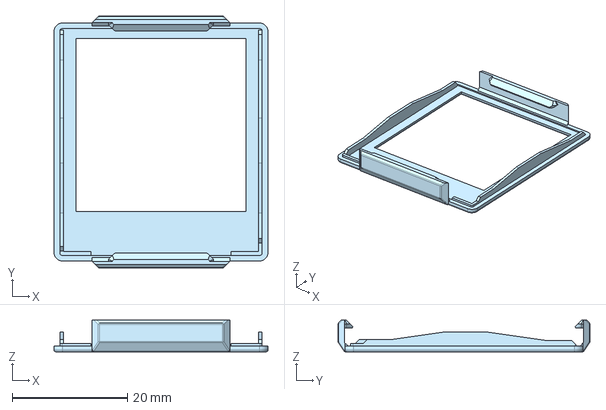
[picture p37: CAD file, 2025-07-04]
3D/cases/patches/1/case_front_v2.step
37.2 x 43.8 x 5.50 mm

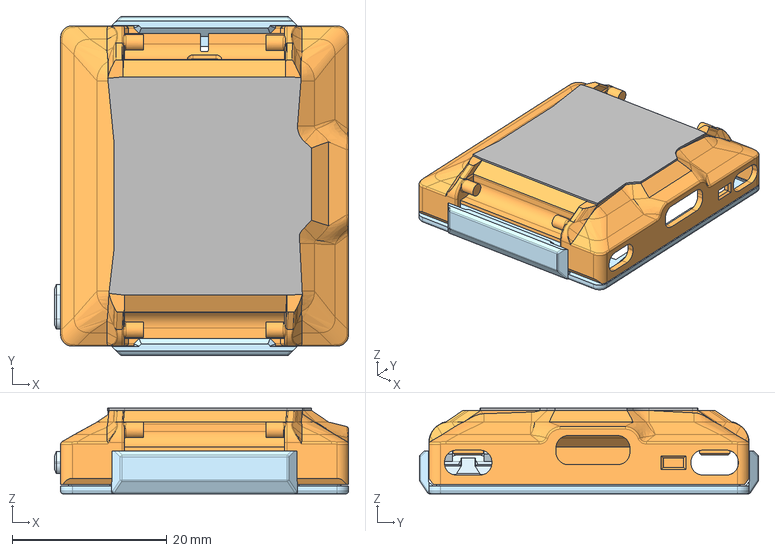
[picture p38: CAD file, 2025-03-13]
3D/cases/Szybet-side/3D/side case.step
38.0 x 43.8 x 11.1 mm

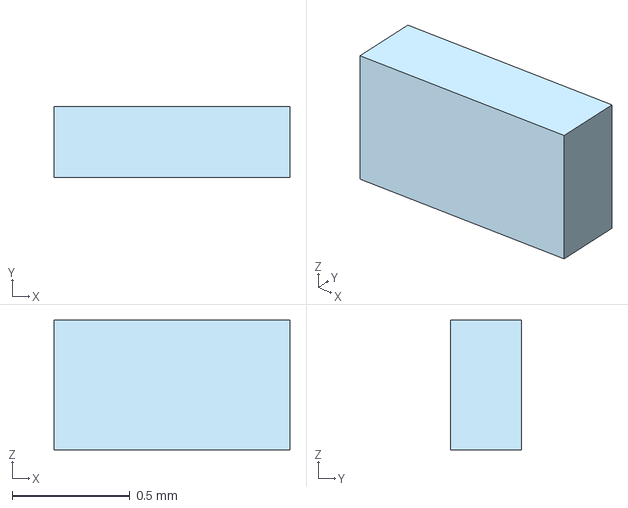
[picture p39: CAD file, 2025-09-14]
hardware/kicad/Yatchy/3d-Models/IN-S42DS.step
1.00 x 0.3 x 0.55 mm

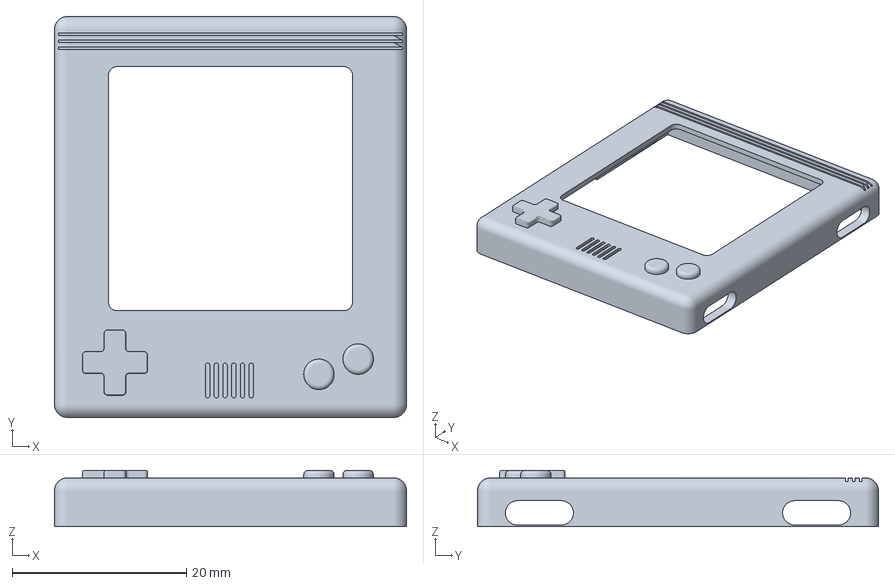
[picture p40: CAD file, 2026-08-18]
3D/cases/Michal-gameboy/3D/michal-gameboy-top.3mf
40.4 x 46.0 x 6.46 mm

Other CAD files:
3D/cases/Michal-gameboy/3D/michal-gameboy.FCStd
3D/cases/glowy-thicc/3D/coverintegratedbatter.step
3D/cases/patches/1/better_strap_dot.stl
3D/cases/Szybet-side/3D/motor cover.step
3D/cases/Szybet-side/3D/module led cover.step
3D/cases/Szybet-side/3D/strap.step
hardware/kicad/Yatchy/3d-Models/BAT54TW-7-F.stp
hardware/kicad/Yatchy/3d-Models/BMA456.stp
hardware/kicad/Yatchy/3d-Models/BMA530.stp
hardware/kicad/Yatchy/3d-Models/CLMVC-FKA-CL1D1L71BB7C3C3_CRE.step
hardware/kicad/Yatchy/3d-Models/ESP32-C6-MINI-1-N4.step
hardware/kicad/Yatchy/3d-Models/EVP-AKE31A.stp
hardware/kicad/Yatchy/3d-Models/MCP23018-E_MJ.stp
hardware/kicad/Yatchy/3d-Models/MCP73831T-2ATI_OT.step
hardware/kicad/Yatchy/3d-Models/RV-3028-C7_32.768kHz_1ppm_TA_QC.stp
hardware/kicad/Yatchy/3d-Models/SFV24R-4STBE1HLF.stp
hardware/kicad/Yatchy/3d-Models/USB4730-GF-A-KIT.stp
hardware/kicad/Yatchy/3d-Models/display_eink.step
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

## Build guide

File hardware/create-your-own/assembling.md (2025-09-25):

## **A reminder, all of this is provided without any warranty. If something goes wrong and the PCB is bad, wrong components, not my fault**

#### Prototype guide, I could have skipped something, let me know if something is not clear

# Assembling Yatchy
There are 2 ways to solder a Yatchy (in a reasonable way):
- Soldering manually:
  - Allows for bigger control over the process, allows for more debugging capabilities, more testing options (I will explain it below)
  - Takes more time
  - Cheaper
- Via a stencil
  - Less debugging options, less testing options, less control of what's going on (which doesn't mean it's not possible, simply compared to manually)
  - Faster
  - More expensive

Some more notes:
- As for the skill level required, yh, idk, both are hard, here you solder everything manually but in stencil you need to repair things that didn't go well, so idk, decide for yourself
- In this guide I will focus on manual, but also say from time to time things specific to stencil. If you use stencil for soldering many yatchies, you should still solder at least one manually to understand what is going on.
- The sections are from top to bottom of order of what needs to be soldered
- Order of soldering things (in a section) is pretty much up to you and your choosing, sometimes I will note things that I suggest. Just do it so it's the easiest for you
- If a test is too hard for you, it could be skipped, but if something later doesn't work, it will be a lot harder to debug what is actually going on, it could even result in damaging more components
- I will not talk things like "If you power the device via 5V USB, you can't have a power supply connected on the battery terminals, otherwise the charger will start charging and things can go messy". Common sense, common electronical/arduino/esp32 level knowledge required
- Testing every section should be also done via power consumption - multimeter, how much current it draws, if too much, then you know the answer, it's shorted
- If soldering with stencil **please** check for shorts and problems after soldering. Seriously, the process is never perfect

Things like:
- Equipment I use, or is needed
- What soldering skills are needed
- Where to view the PCB and schematic (while soldering, you should probably open it to know which components to grab)

Are discussed in other files. I will not link them, as you should read everything anyway, so there are no suprises later.

# Yatchy "sections"
Yatchy (as any other electronic device really) consists of sections. Some depend on each other, the point is you pretty much can't (and shouldn't) (until you have the skill and knowledge to know what you are doing) debug things when soldering half of them. Also don't power the device when half of it is soldered. Things may simply not work or just damage itself (rarely)

The schematic is also splitted into those sections, but sometimes I modify the sections below for reasons

### Power


Converts either 4.2V from the battery or 5V from USB to 3.3V used by the rest of the board. You don't need other sections (Battery, USB) to provide these voltages to it, you can simply do it via a wire (where the voltages would normally be provided from). All other sections depend on this section, but if you have an external, good and stable 3.3V source, you can power it directly to the 3.3V line. I usually solder the 3.3V and GND wire here:



so if you do the wire, you can skip this section for now

### esp32c6


Pretty much the hardest section, needs to be soldered via hot plate (hot air is too hard for me). Apply solder on both sides, on the chip itself only a thin layer, place it ideally and give it a go... You can skip the main big ground pad in the middle, not really needed

**Testing**
- First, if you can, measure the power consumption. It should be around 20-30mA (just this section, more sections more power). If it's like above 50mA, you are in danger, probably a short somewhere, probably already smoked
- Second, check if there is communication:
  - if you have a UART-USB converter (if not, you can reuse an arduino, esp32 devboard, RPI for that, but I won't explain it here, google it), solder GND, RX, TX (below the flex cable), with baudrate 115200 check if there is any communication. You should see some ROM messages
  - if you soldered the USB section, if you connect the device, it should connect itself and disconnect all the time. That's normal, there is no program so it resets itself. When opening the serial device that appeared on the PC, baudrate 115200 you should also see ROM messages over and over again.
  - with UART or USB, after typing `esptool --after no_reset chip_id` (the esptool cli command) (you might need to type it many types to catch, as the esp32c6 resets) (This command resets the device into bootloader mode, this is the state that it needs to be flashed in). If it can't catch it, you might need to reset the device into bootloader mode manually with those pins:
 


Bootloader and reset pin. If you can't google it out, let me know, I will write or even record a proper tutorial

If you did not solder anything else (well you need power in any form, the USB section is allowed and optional, as told above) (so stencil users, not for you), lucky you. There is a test-program which allows for detecting shorts & checking connections with a multimeter. It's located in the test-program directory in this directory. Grab it to your PC, then:
- All of this tested only on linux. Windows could work, idk
- Install the rust programming language. Your cli should be able to execute the cargo command
- Follow the README.md in the test-program directory
- in Cargo.toml, in features section choose what you have (do you have usb, or uart (don't both), or you have i2c section. Add them to default, follow the toml syntax (or ask google/AI)
- in .cargo/config.toml comment and uncomment the `runner` line for your communication method
- if everything is correct, run in test-program directory `cargo run --release` - it should succeed and flash the program (You might need to reset it to bootloader mode), you should see logs from the program booting. Now you have a few commands to choose from (no backspace support lol):
  - `self_check_gpio` - It sets one gpio to high, the rest as inputs and checks if the inputs are high. If it says it's high, it's worth checking if there is a short (After disconnecting the device from power...). If there is not a short, cool, then it's just floating magic. Was worth to check anyway.
  - `gpioX` - Where X is number of the gpio. For available gpios for your setup, look up `src/flex_io.rs` the `pub struct FlexIo<'a>` line. If a gpio is behind a feature which you have not enabled, then it's not available to check. If you type type a gpio command, it will trigger it high and low every second. Check with a multimeter if the voltage jumps, if not, there is no connection you need to resolder the whole chip. (you can use soldering iron to maybe fix one pin, but not more, even with special footprint it's hard, but possible). To know where to connect the multimeter, open kicad and trace what goes where using the schematic and pcb view, the "`" button can be handy too.
  - `exit` - exits the current action. You need to type it after every action to switch to another

Now (+ USB section) (even with stencil) you should be able to flash and compile inkwatchy, which will die inside because nothing else is present, so we need to enable testing mode:
- in src/defines/condition.h set LP_CORE to 0 for now, later, to get the lp core, join the discord server, that where it's disributed
- follow normal inkwatchy setup, but don't flash things, just build everything
- in src/defines/config.h set DEBUG to 1, WAIT_FOR_INPUT to 1 and SIMPLE_DEEP_SLEEP_TEST to 1
- in src/other/debug/debugMain.cpp in the section of `#if SIMPLE_DEEP_SLEEP_TEST && (WAIT_FOR_INPUT || WAIT_FOR_MONITOR)` turn off everything (so to 0) (MCP, ACC, etc)
- Flash
- Open monitor
- type 123
- it should go to sleep, it won't appear in in USB until a power cycle

This will allow us to test things later

### USB


the USB pins sometimes don't want to catch solder, use more flux and higher temperature

To test it, it requires a powered, from any source esp32c6 section. Testing it is described in that section too. If USB connection doesn't work, on linux you can look up the dmesg command for more info. Probably the connection of D+ D- pins are bad, or the TVS diodes are bad. If 5V doesn't appear from a usbc-usbc charger cable, then something is wrong with the resistors.

### I2C


simply 2 resistors. Can't be tested, if gpio expander or Acc doesn't work, maybe those are bad, as they depend on this

### Gpio expander (mcp23018)


can be soldered manually or with hotplate. Make sure with microscope or magnifying glass that the pins are soldered properly

Requires i2c and esp32c6 (so also, uhm, power) sections to be tested. To test, in debugMain.cpp set IS_MCP and IS_MCP_CONFIGURATION to 1, reflash, you should see some logs about registers or failures if something is wrong. This test doesn't check connections, just if there is communication. That's why you need to make sure the pins are connected anyway!

### Screen


Here I propose soldering the flex connector first, as its the hardest. Check for shorts, check if the pins are soldered (if they can be moved a bit with idk something sharp, then its not soldered). If there is solder behind the pins, use a solder wick to catch it. Clean flux also inside the connector, open it's "brackets". Obviously the flex connector needs to be perfectly oriented, not in angle

the rest is easy, the coil at the end.

the flex cable connector needs cutting off a bit of plastic here, with a knife, scalpel:



to test, requires: esp32c6, mcp23018 (so power, i2c, usb too).

You can test the screen by inserting it "straight", not on the back. Look up pictures in the repo on how far it should be inserted. Be carefull while inserting it, apply the force equally when closing the brackets. For detaching use thin tweezers, toothpick and do it slowly, as too much force can break the connector

to test, in debugMain.cpp enable IS_SCREEN (+ mcp things are also needed) after flashing and everything, a black-white circle should appear on the screen. Grey screen indicates problems. even one loose pin can break everything. The mcp23018 also needs to work for the screen to work

### Acc


As noted elsewhere, either bma456 or bma530. Requires i2c section, obviously esp32c6 (so power) too.

Requires hotplate soldering, just as the esp32c6 (apply on both sides, etc)

to test, enable IS_ACC in debugMain.cpp and read logs after flashing and everything

### Crystal/Quartz


Don't solder the resistor for too long, as the pins of the esp32c6 could get desoldered themself. Apart from that, it's easy, the crystal is solderable by hand with a soldering iron

To test it, it's more complicated, it's explained in `initRTC()` in the file `src/hardware/rtc/rtc.cpp`. In the end you should get a value, read the rest there and compare it. If it's really bad, maybe on of the capacitors is not soldered properly, or something?

Remember to revert these changes made to the files later

### Charging circuit


Requires well every section basically, maybe not acc or crystal

Make sure these 2 resistors are both soldered properly, in correct order, have conduct and correct resistance. If something is wrong, on connecting power it could fry your board.



To test, well, later with a working LED from the module, connect the battery and charge it from USB. The led should be yellow when charging, when it finished it should be green, when disconnecting it should be red for a short second. Also observe regular logs from DEBUG while running inkwatchy (so disable the debugMain.cpp options). Also check temperature of the chip while charging, shouldn't be hot.

### Motor circuit


Requires power, esp32c6

to test, either in debugMain.cpp enable the motor option, or just later with buttons. (also solder the motor obviously)

### Buttons
Nothing to tell or to show here really. They require mcp23018, esp32c6 and charging circuit (as in, also, either soldered battery or 5V connected, so normal) (yes) to work. To test, well, you should know how to test buttons with a multimeter ;D

### Module


should be pretty much soldered last

Depending on your module, the specifics could be different. but soldering it to the main pcb should be the same. First, place both PCB's on something really flat (I use sheet metal). Make sure they don't wiggle, if so, fix it (solder from tht holes) with a solder wick. Then lock them in place using tape, but don't cover the pins below. Also make sure the pcb's connect properly, if there are imperfections, fix them with sand paper or a knife

now that everything is perfect, in place, add a lot of solder to the 2 pins on the sides, so it will be pretty solid and connected well. After that, connect the rest of the pins. Make sure not to short things. I prefer a short wire that I tinned before, then cut it off & add more solder then, some prefer only solder no wires. The point is, you should add a bit of solder between the pads to also reinforce it

I need to say this too (lol): do the connections on the side of the PCB where components are, not on the back, as that's where the screen is.

doing a hotplate after attaching the module risks things, obviously, but I did it, maybe you can too

The LED on the default module is suggested to be soldered on the hot plate as it's fragile. To test the led, there is an option in debugMain.cpp for it. It should appear white, if not, at least one of the connections is broken

### Screen2 (as in, on the back)
1. Apply double sided tape (as in, one that is not thin, not thick, idk 1mm to the back. Don't apply it to the module area. In fact, you can leave the center also empty, so something like:



2. Connect the screen to the connector, lock it in
3. Apply it precisely, use the top edge so it's not angled, crooked

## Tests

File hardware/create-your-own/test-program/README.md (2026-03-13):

## THIS PROGRAM IS ONLY INTENDED IF YOU SOLDERED ONLY THE ESP32C6, NOTHING ELSE. IT CHANGES STATES OF THE PINS OF THE ESP32C6, FOR YOU TO MEASURE WITH A MULTIMETER IF THERE IS CONTACT / SHORT. IF YOU SOLDERED USING A STENCIL, DO NOT USE THIS PROGRAM. THIS PROGRAM REQUIRES AN ALMOST EMPTY PCB.

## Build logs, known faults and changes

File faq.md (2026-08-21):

## Frequently Asked Questions
or at least sometimes

### Contents
1. [Why no spot for the vibration motor?](https://github.com/Szybet/Yatchy/blob/main/faq.md#1-why-no-spot-for-the-vibration-motor)
2. [What soldering gear do I need?](https://github.com/Szybet/Yatchy/blob/main/faq.md#2-what-soldering-gear-do-i-need)
3. [Where can I buy a Yatchy?](https://github.com/Szybet/Yatchy/blob/main/faq.md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)

#### 1. Why no spot for the vibration motor?

No place for it really, it was more important to optimise the module area than for the motor. As yatchy is assembled by hand, it can be placed anywhere, or integrated into the side of the case, or just use as a buzzer TLDR: for hackability (both for the choosing of the motor / buzzer up to the way of designing the case, placing it where you want) and other priorities, as the cases I design have enough space (in one battery is on the strap, in the other its simply a brick case) its simply put on top of components

#### 2. What soldering gear do I need?
I don't know, depends on your skill, a madman will need a lighter and a metal rod with some tin ore to do it \s

But seriously, here is my gear I use, but keep in mind:
- For your first Yatchy, or first soldering job buy a lot of spare components, even I needed them
- Read the hardware wiki to know what skill you need, what to expect etc.
- It's old, there are for sure better alternatives today
- I'm no expert, so still the point above, there are probably better alternatives (give me some tips if you know better, but look at the point below)
- I prefer, lightly put, to pay less, a lot less when available, but I also prefer long lasting tools. The triangle is my enemy.

0_BXO-Krt9rSiopn6k
  
- Again, depending on your skill you will need better or worse gear to do the job

So it's a very general guide, something among the lines of "You need everything temperature controlled" and more. I will also count how much it costs, because I'm curious too

Also I won't mention things that are more general like tweezers, digital multimeter (Those 2 need to be sharp, the multimeter probes too), solder wick etc. Because there are hardly "bad" such products, but I also use them

1. Soldering iron: KSGER T12, 270zł
   
4173eb1783ae72dde18ef622208bfd8bebe6fe91_original

- I heard it's sometimes inside really bad quality components and it explodes, not mine, works for many years, inside looks good enough
- The smallest available soldering tip, obviously
- The coil of it beeps, I dislike beeps

2. Hot air: YIHUA 858d, 110zł
   
obraz

- You might able to use the hotplate to replace the hot air, but not the other way

4. Hot plate: MECHANIC IX5 ULTRA, 100zł

obraz

- Used to solder the esp32c6, the bma acc and the mcp23018 (mcp23018 is managable by soldering iron but me lazy), I couldn't do the esp32c6 with hot air, maybe the rest is managable with it
- Before it I used a soviet era break cooker. I'm not joking. It was very hot, somehow everything worked fine:
  
front-view-portable-single-burner-260nw-1739880107

5. Solder: Cynel proffesional Sn60Pb40, 30zł

Cyna-100g-Cynel-0-5mm-z-Topnikiem-SN60PB40-SW26

- The thinnest one, 0.5mm I think
- I love this solder and you should too, it has a bit of flux in it so it makes everything so much easier. It also has lead, that also helps (no it's not scary, educate yourself further, no, Yatchy is not created by a company so it's not banned for this use case)

6. Flux: BTFO-81-1BROQUETAS, 20zł

obraz

- Here idk if it's really the best at this price point, it just works for me
- Once I tried a fluid flux, there is no coming back

7. Flux pen: KESTER 951, 20 zł

obraz

- Usefull for hot plate soldering (where not so much flux is wanted)

8. Microscope: Those cheapest ones out there, no model, 40zł

obraz

- It's just so much better to solder with one, yes I'm blind
- I added TVS diodes and capacitors for it to not break suddenly like the last one, expensive one
- They are all shit quality up to 50$ so the cheapest one is fine anyway.



Sum: 690 zł, 182$, could be worse

#### 3. Where can I buy a Yatchy?
Yes it's a TLDR, read all the docs for more explanation.

As for 03.07.2026

Currently, Yatchies cannot be purchased directly due to technical and financial constraints.

If you can, create your own, it's open source, I can provide some help/advice

In the future, there may be additional sellers which I'm welcoming if they appear.

To summarize, if you are interested in acquiring a Yatchy, keep an eye on the discord/matrix server and consider obtaining the Yatchy role for notifications. Those who have expressed interest in the relevant thread will be considered in chronological order.

### Dimensions
A bit smaller than yatchy, but the USBC is on the thicker side (BUT THT!) if you are ordering the PCB's yourself, you can change the usbc to a smd one easily, if you believe in those pads holding for long

The PCB thickness is 1.2mm in the 3D file. A 1mm one would still work (THT!)






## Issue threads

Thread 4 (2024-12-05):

pogo pins and magnets

kriku, 2024-12-05:
hi! great work! looks amazing!

I have a suggestion

how do you think, is it possible to move type-c connector to other part, like rp2040-tiny https://www.waveshare.com/wiki/RP2040-Tiny.

I mean you don't have to update firmware frequently, and if you move out type-c circuit - it will safe a lot of space and overall thickness will be thinner.

and make pogo pins for charging

what do you think?

Szybet, 2024-12-05:
First, many people suggested pogo pins, the answer is one:
# No, kind of
And the big no is there for a reason. I had many devices using pogo pins, in all of them the pogo pins broke. Lenovo tablet, xiaomi smartwatch and countless others. It's a flawed technology. Even in new premium devices, I had enough of reddit post about the framework laptop "the keyboard module doesn't work" "try to reattach it, it was the pogo pins" - And it's only now, let's wait until they wear out and stop fully working, like they did for my devices.
Why kind of? because you can simply not solder the USBC connector to the board (saving on thickness) and just expose pogo pin pads outside the case & wires to the default module or just create a dedicated module for pogo pins, to charge it from there. 5V is exposed there, no issue in that:
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
Oh also USB-C is for charging too ;p

Closed 2024-12-05.

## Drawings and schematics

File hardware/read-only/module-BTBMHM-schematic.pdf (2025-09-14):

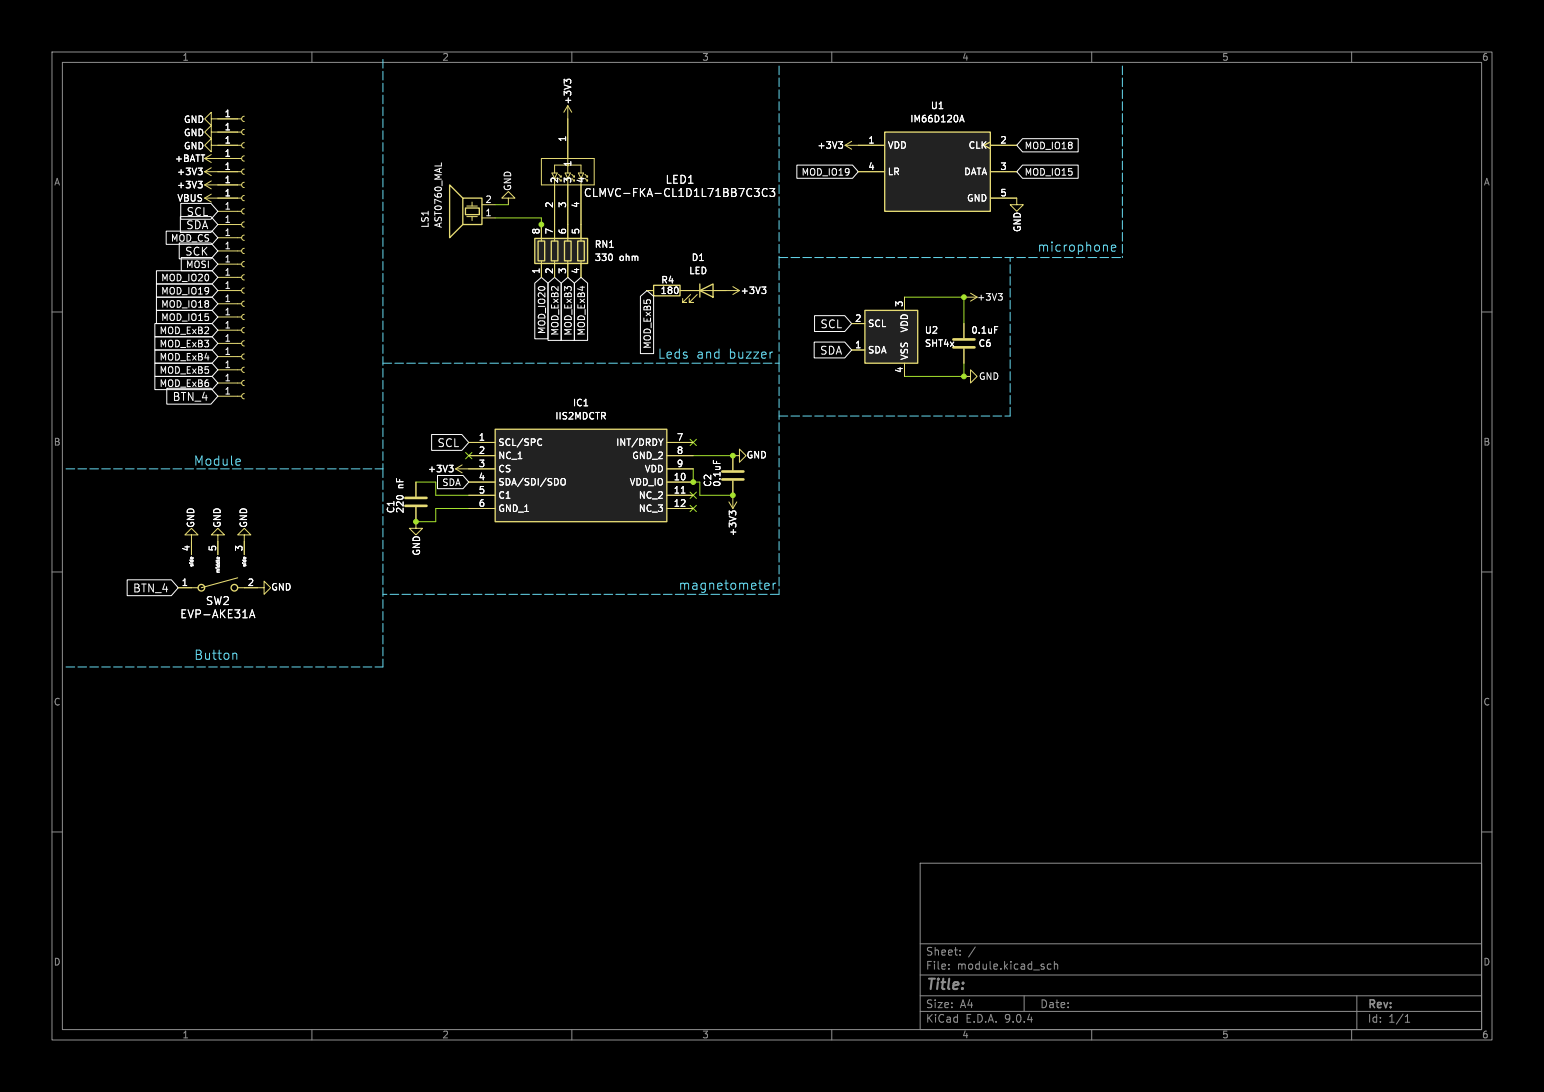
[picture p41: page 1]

Id: 1/1 Title: File: module.kicad_sch Sheet: / 11111111111111 +3V3 GND
0.1uF VBUS GND
+BATT GND

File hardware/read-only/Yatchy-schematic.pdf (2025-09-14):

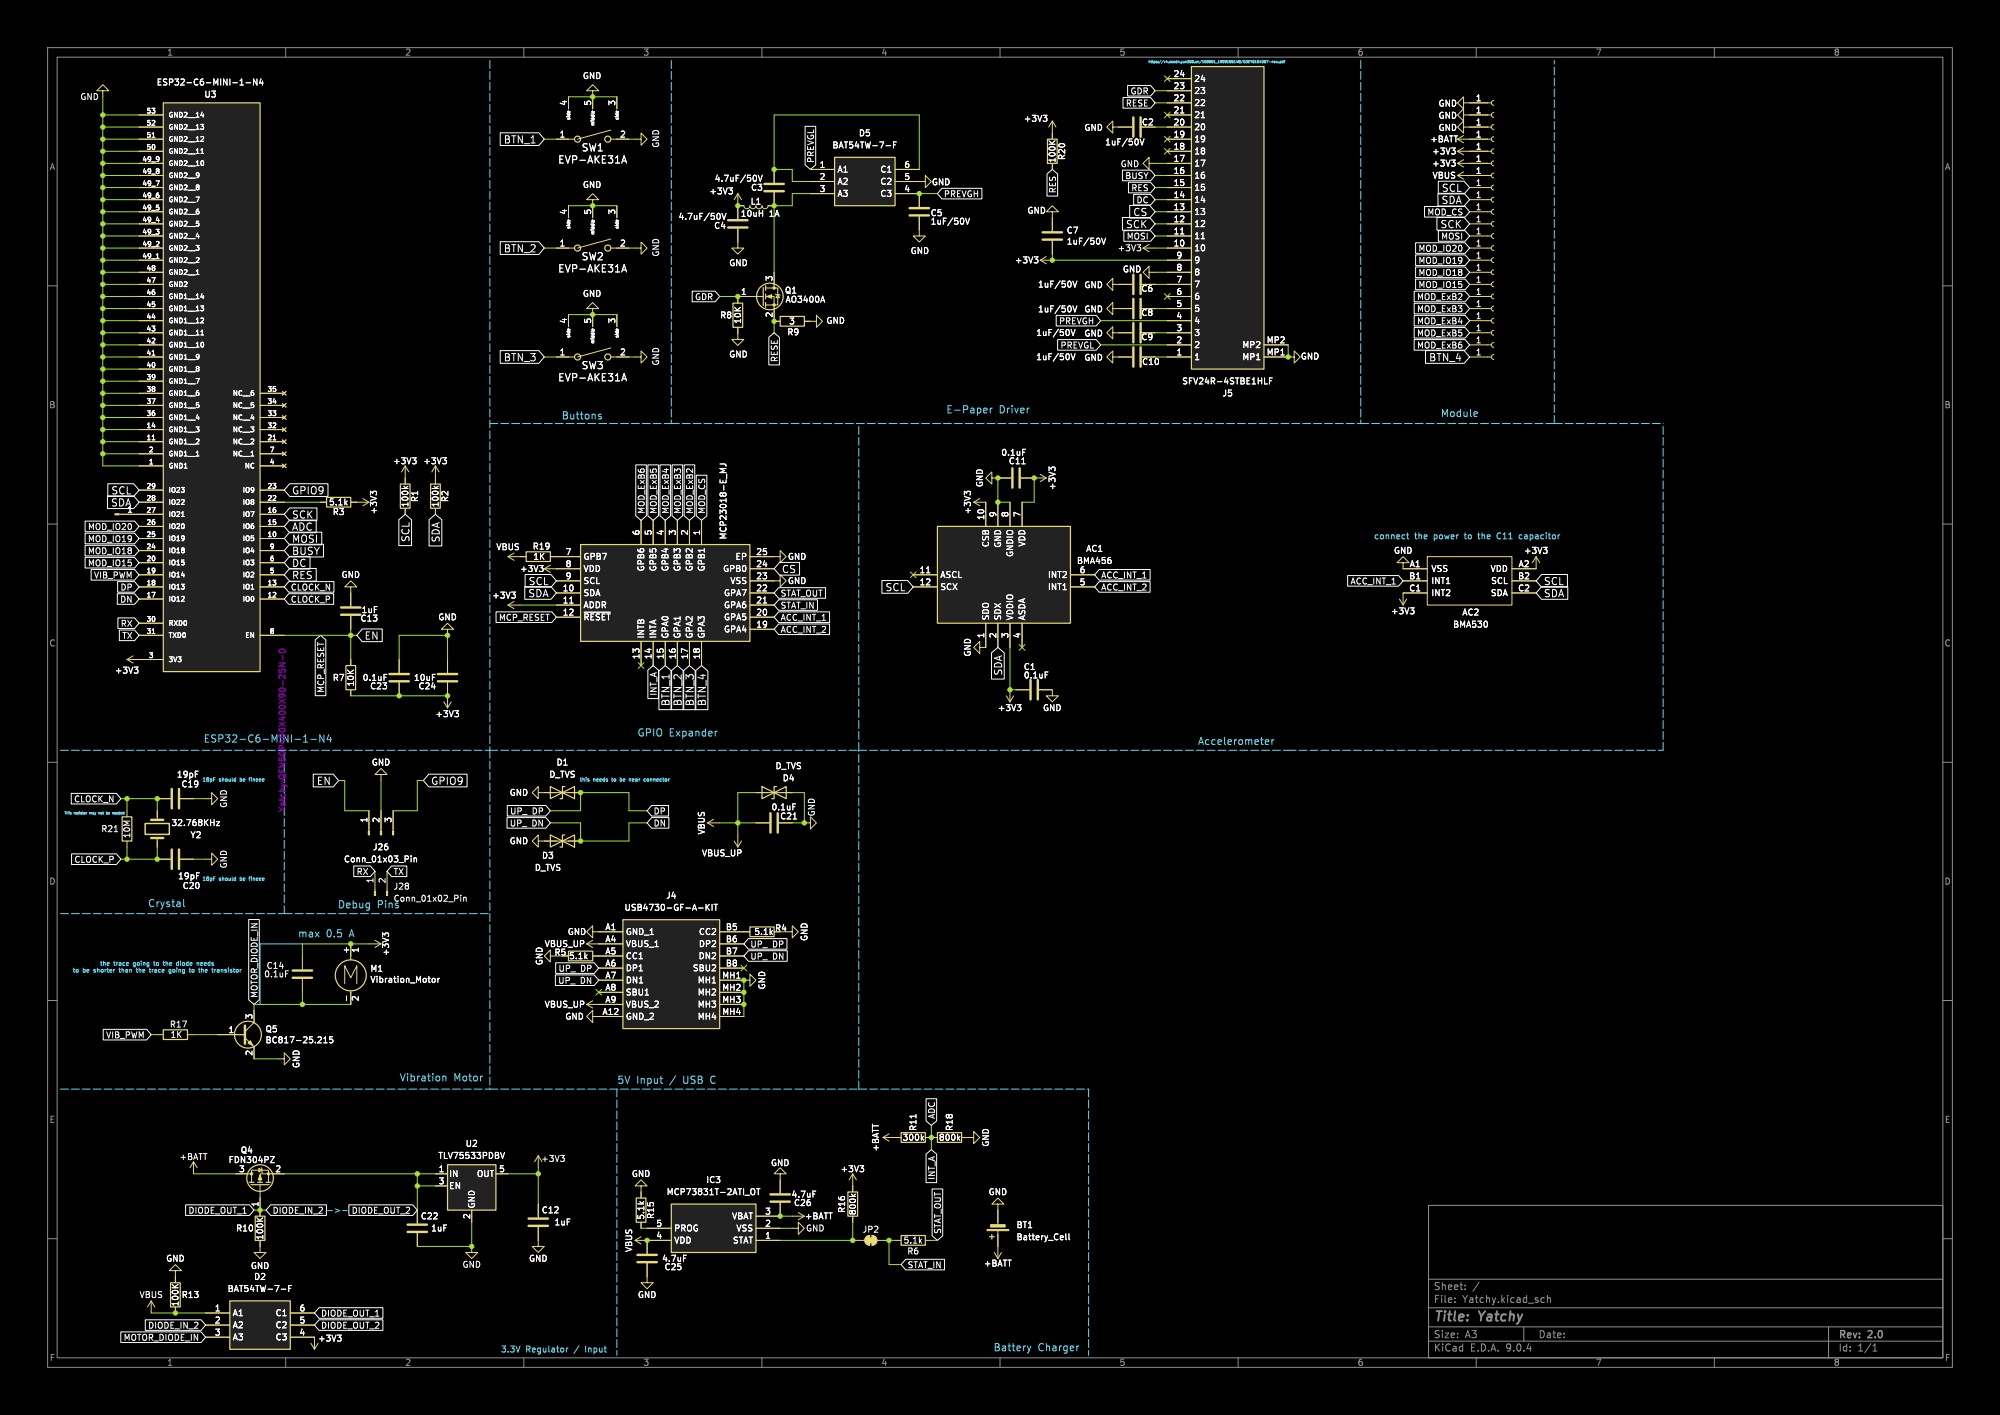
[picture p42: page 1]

this needs to be near connector Buttons

connect the power to the C11 capacitor
GND
VSS A1
INT1 B1

the trace going to the diode needs

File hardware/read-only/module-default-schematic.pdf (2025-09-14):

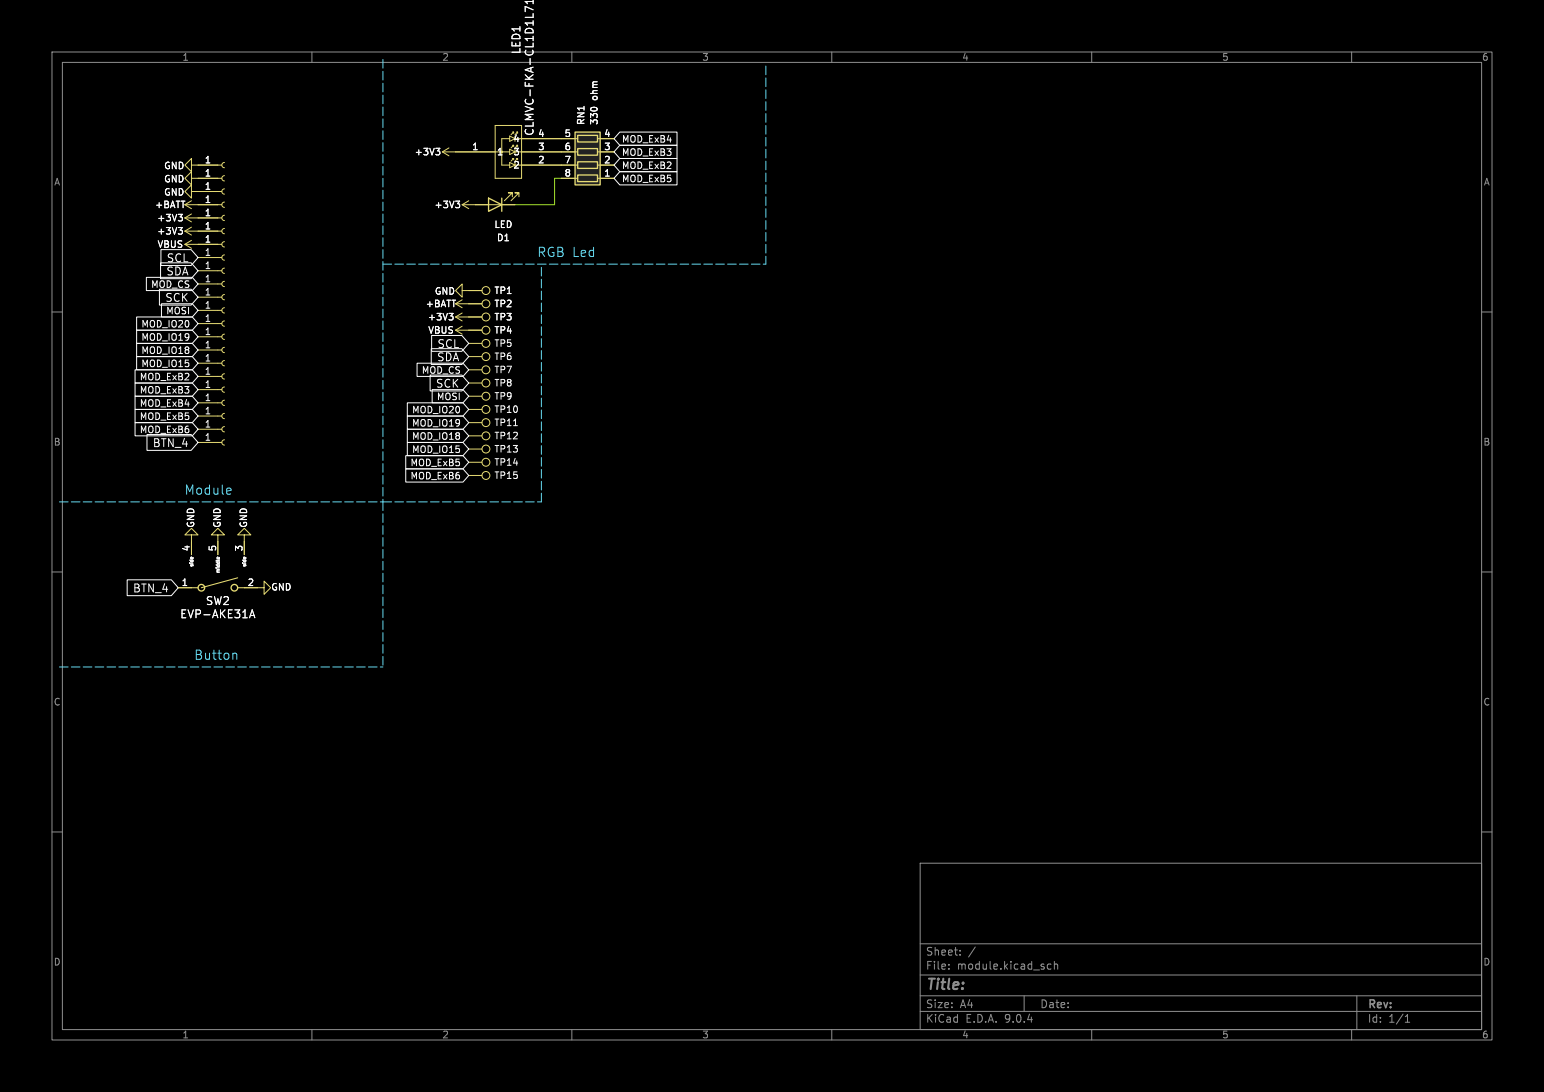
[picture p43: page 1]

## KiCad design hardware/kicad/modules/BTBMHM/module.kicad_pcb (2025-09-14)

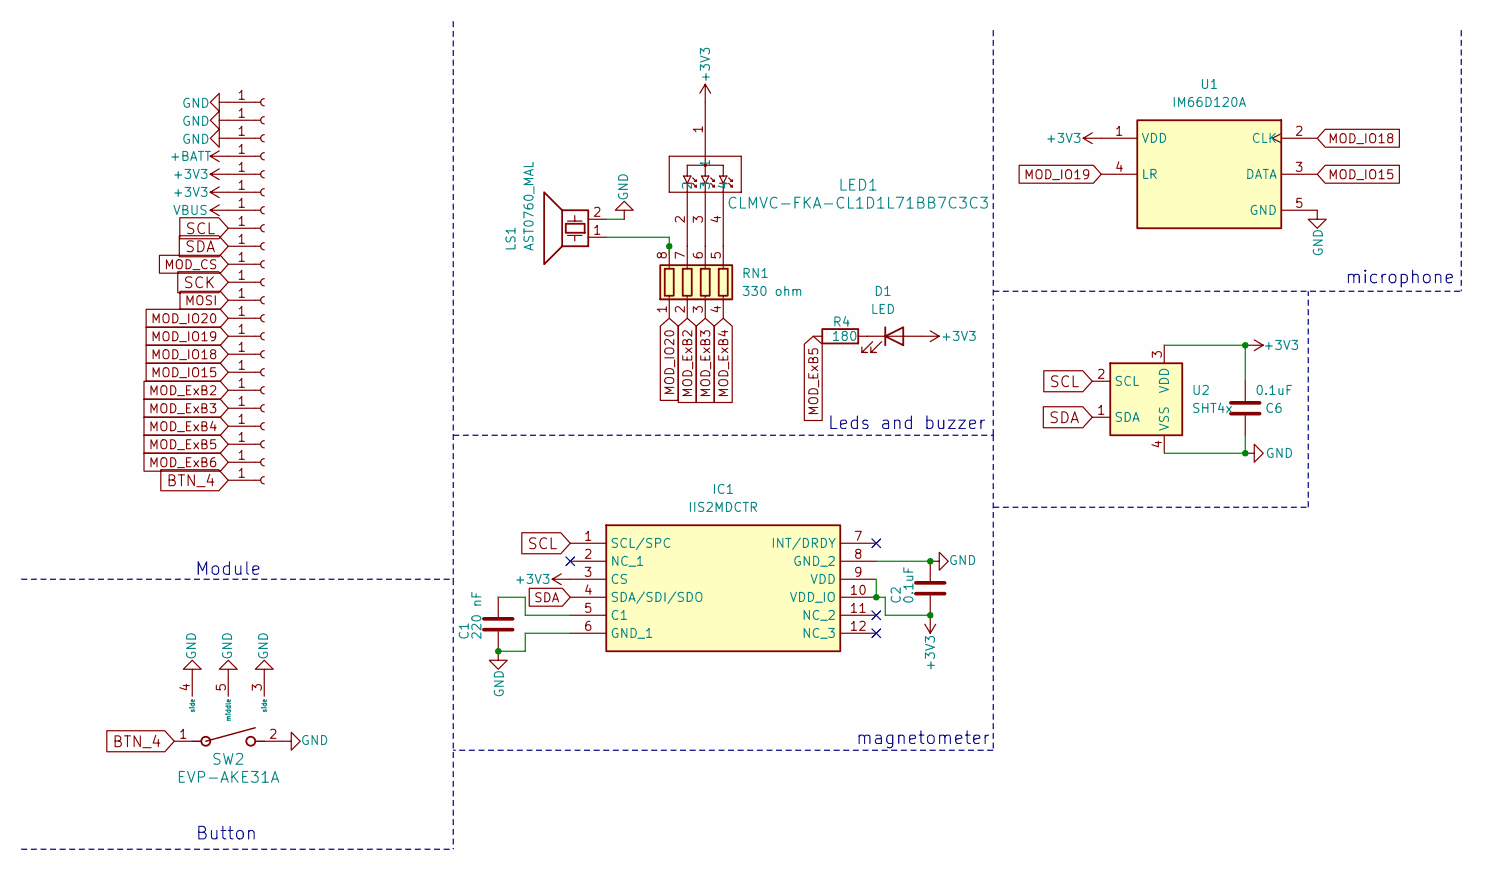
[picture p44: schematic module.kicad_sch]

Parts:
C1: 220 nF; C_0603_1608Metric
C2, C6: 0.1uF; C_0603_1608Metric
D1: LED; LED_0402_1005Metric
IC1: IIS2MDCTR; BOSCH_LGA-12; Mouser Part Number 511-IIS2MDCTR
J1, J2, J3, J4, J5, J6, J7, J8, J9, J10, J11, J12, J13, J14, J15, J16, J17, J18, J19, J20, J21, J22: MOD_CONN; mod_Connector
LED1: CLMVC-FKA-CL1D1L71BB7C3C3; CLMVC-FKA-CL1D1L71BB7C3C3_CRE
LS1: AST0760_MAL
R4: 180; R_0402_1005Metric
RN1: 330 ohm; R_Array_Concave_4x0402
SW2: EVP-AKE31A; SW_EVP-AKE31A_PAN
U1: IM66D120A; IFX-PG-TLGA-5-6-V
U2: SHT4x; Sensirion_DFN-4_1.5x1.5mm_P0.8mm_SHT4x_NoCentralPad

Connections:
+3V3: C2.2, C6.2, D1.2 (A), IC1.3 (CS), IC1.9 (VDD), IC1.10 (VDD_IO), J5.1, J6.1, LED1.1, U1.1 (VDD), U2.3 (VDD)
+BATT: J4.1
BTN_4: J22.1, SW2.1
GND: C1.2, C2.1, C6.1, IC1.6 (GND_1), IC1.8 (GND_2), J1.1, J2.1, J3.1, LS1.2, SW2.2, SW2.3 (side), SW2.4 (side), SW2.5 (middle), U1.5 (GND), U2.4 (VSS)
MOD_CS: J10.1
MOD_ExB2: J17.1, RN1.2 (R2.1)
MOD_ExB3: J18.1, RN1.3 (R3.1)
MOD_ExB4: J19.1, RN1.4 (R4.1)
MOD_ExB5: J20.1, R4.1
MOD_ExB6: J21.1
MOD_IO15: J16.1, U1.3 (DATA)
MOD_IO18: J15.1, U1.2 (CLK)
MOD_IO19: J14.1, U1.4 (LR)
MOD_IO20: J13.1, RN1.1 (R1.1)
MOSI: J12.1
unnamed: D1.1 (K), R4.2
unnamed: C1.1, IC1.5 (C1)
unnamed: LS1.1, RN1.8 (R1.2)
unnamed: LED1.2, RN1.7 (R2.2)
unnamed: LED1.3, RN1.6 (R3.2)
unnamed: LED1.4, RN1.5 (R4.2)
SCK: J11.1
SCL: IC1.1 (SCL/SPC), J8.1, U2.2 (SCL)
SDA: IC1.4 (SDA/SDI/SDO), J9.1, U2.1 (SDA)
VBUS: J7.1

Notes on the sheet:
magnetometer
microphone
Button
Leds and buzzer
Module

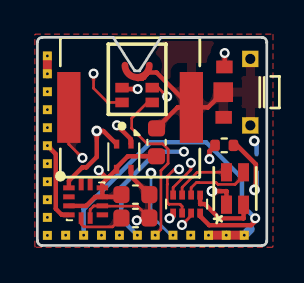
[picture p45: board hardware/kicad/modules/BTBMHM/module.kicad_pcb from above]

Board: 4 copper layers, 12.7 x 11.6 mm, 34 parts (1 on the bottom side), 19 nets.

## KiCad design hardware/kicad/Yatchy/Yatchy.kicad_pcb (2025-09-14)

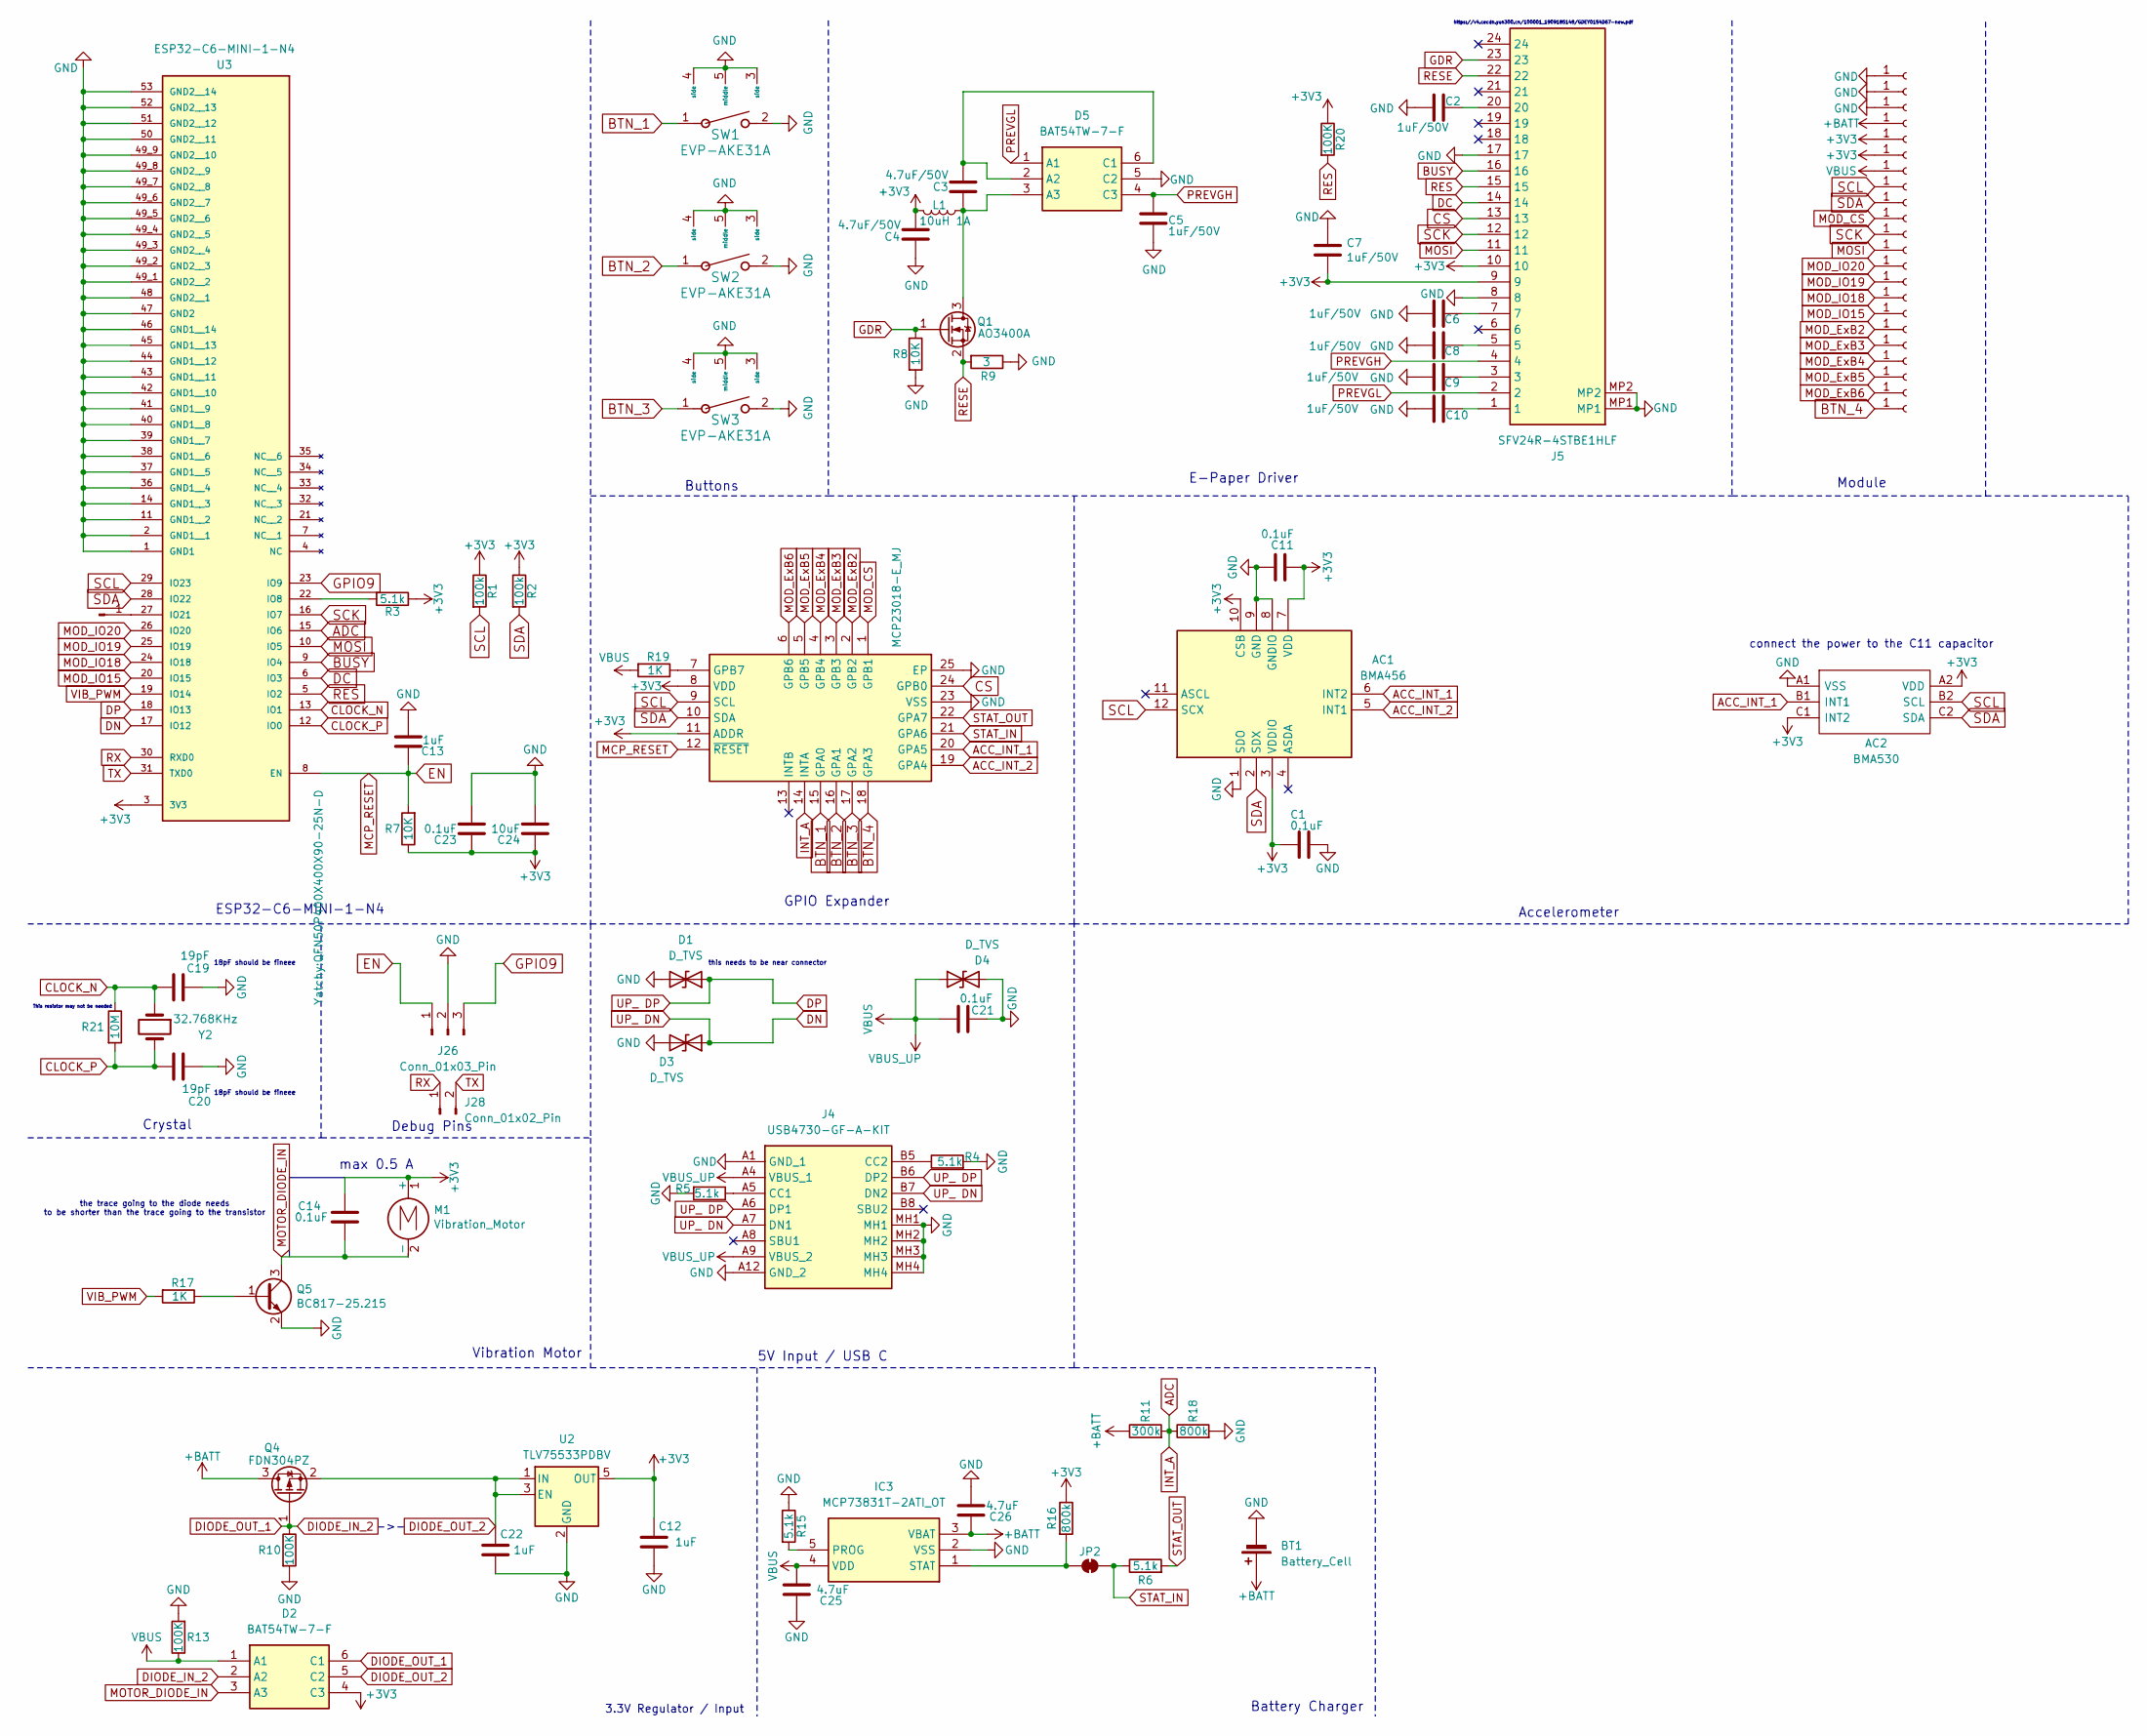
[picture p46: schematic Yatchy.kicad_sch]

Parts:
AC1: BMA456; BOSCH_LGA-12; Mouser Part Number 262-BMA456
AC2: BMA530; Mouser Part Number 262-BMA530
BT1: Battery_Cell; Battery_Header
C1, C11, C14, C21, C23: 0.1uF; C_0603_1608Metric
C2, C5, C6, C7, C8, C9, C10: 1uF/50V; C_0603_1608Metric
C3, C4: 4.7uF/50V; C_0805_2012Metric
C12, C13, C22: 1uF; C_0603_1608Metric
C19, C20: 19pF; C_0402_1005Metric
C24: 10uF; C_0603_1608Metric
C25, C26: 4.7uF; C_0805_2012Metric
D1, D3, D4: D_TVS; D_SOD-523
D2, D5: BAT54TW-7-F; SOT65P222X110-6N; Manufacturer_Part_Number BAT54TW-7-F
IC2: MCP23018-E_MJ; QFN50P400X400X90-25N-D; Manufacturer_Part_Number MCP23018-E/MJ
IC3: MCP73831T-2ATI_OT; SOT95P270X145-5N; Manufacturer_Part_Number MCP73831T-2ATI/OT
J1, J2, J3, J6, J7, J8, J9, J10, J11, J12, J13, J14, J15, J16, J19, J20, J21, J22, J23, J24, J25, J27: MOD_CONN; mod_Connector
J4: USB4730-GF-A-KIT; USB4730GFAKIT; Mouser Part Number 640-USB4730GFAKIT
J5: SFV24R-4STBE1HLF; SFV24R4STBE1HLF; Manufacturer_Part_Number SFV24R-4STBE1HLF
J17: Conn_01x01_Pin; testpoint
J26: Conn_01x03_Pin; PinHeader_1x03_P2.00mm_Horizontal_Small
J28: Conn_01x02_Pin; PinHeader_1x02_P2.00mm_Vertical
JP2: SolderJumper_2_Bridged; SolderJumper_Bridged_Small
L1: 10uH 1A; HPI0530-100
M1: Vibration_Motor; Motor_Header
Q1: AO3400A; SOT-23
Q4: FDN304PZ; SOT-23
Q5: BC817-25.215; SOT-23
R1, R2: 100k; R_0402_1005Metric
R3, R4, R5, R6, R15: 5.1k; R_0402_1005Metric
R7, R8: 10K; R_0402_1005Metric
R9: 3; R_0402_1005Metric
R10, R13, R20: 100K; R_0402_1005Metric
R11: 300k; R_0402_1005Metric
R16, R18: 800k; R_0402_1005Metric
R17, R19: 1K; R_0402_1005Metric
R21: 10M; R_0402_1005Metric
SW1, SW2, SW3: EVP-AKE31A; SW_EVP-AKE31A_PAN
U2: TLV75533PDBV; TLV75733PDYDR
U3: ESP32-C6-MINI-1-N4; XCVR_ESP32-C6-MINI-1-N4; PARTREV 1.0
Y2: 32.768KHz; XTAL_9HT10_TXC

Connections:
+3V3: AC1.3 (VDDIO), AC1.7 (VDD), AC1.10 (CSB), AC2.A2 (VDD), AC2.C1 (INT2), C1.2, C4.1, C7.2, C11.2, C12.1, C14.1, C23.1, C24.1, D2.4 (C3), IC2.8 (VDD), IC2.11 (ADDR), J5.9, J5.10, J6.1, J25.1, L1.2, M1.1 (+), R1.1, R2.1, R3.1, R7.1, R16.1, R20.1, U2.5 (OUT), U3.3 (3V3)
+BATT: BT1.1 (+), C26.2, IC3.3 (VBAT), J3.1, Q4.3 (D), R11.1
ACC_INT_1: AC1.6 (INT2), AC2.B1 (INT1), IC2.20 (GPA5)
ACC_INT_2: AC1.5 (INT1), IC2.19 (GPA4)
ADC: IC2.14 (INTA), R11.2, R18.1, U3.15 (IO6)
BTN_1: IC2.15 (GPA0), SW1.1
BTN_2: IC2.16 (GPA1), SW2.1
BTN_3: IC2.17 (GPA2), SW3.1
BTN_4: IC2.18 (GPA3), J24.1
BUSY: J5.16, U3.9 (IO4)
CLOCK_N: C19.1, R21.1, U3.13 (IO1), Y2.1
CLOCK_P: C20.1, R21.2, U3.12 (IO0), Y2.2
CS: IC2.24 (GPB0), J5.13
DC: J5.14, U3.6 (IO3)
DIODE_IN_2: D2.2 (A2), D2.6 (C1), Q4.1 (G), R10.1
DIODE_OUT_2: C22.1, D2.5 (C2), Q4.2 (S), U2.1 (IN), U2.3 (EN)
DN: D3.1 (A1), J4.A7 (DN1), J4.B7 (DN2), U3.17 (IO12)
DP: D1.1 (A1), J4.A6 (DP1), J4.B6 (DP2), U3.18 (IO13)
EN: C13.1, IC2.12 (~RESET), J26.1, R7.2, U3.8 (EN)
GDR: J5.23, Q1.1 (G), R8.1
GND: AC1.1 (SDO), AC1.8 (GNDIO), AC1.9 (GND), AC2.A1 (VSS), BT1.2 (-), C1.1, C2.2, C4.2, C5.2, C6.2, C7.1, C8.2, C9.2, C10.2, C11.1, C12.2, C13.2, C19.2, C20.2, C21.2, C22.2, C23.2, C24.2, C25.2, C26.1, D1.2 (A2), D3.2 (A2), D4.2 (A2), D5.5 (C2), IC2.23 (VSS), IC2.25 (EP), IC3.2 (VSS), J1.1, J2.1, J4.A1 (GND_1), J4.A12 (GND_2), J4.MH1, J4.MH2, J4.MH3, J4.MH4, J5.8, J5.17, J5.MP1, J5.MP2, J26.2, J27.1, Q5.2 (E), R4.2, R5.2, R8.2, R9.1, R10.2, R13.2, R15.1, R18.2, SW1.2, SW1.3 (side), SW1.4 (side), SW1.5 (middle), SW2.2, SW2.3 (side), SW2.4 (side), SW2.5 (middle), SW3.2, SW3.3 (side), SW3.4 (side), SW3.5 (middle), U2.2 (GND), U3.1 (GND1), U3.2 (GND1__1), U3.11 (GND1__2), U3.14 (GND1__3), U3.36 (GND1__4), U3.37 (GND1__5), U3.38 (GND1__6), U3.39 (GND1__7), U3.40 (GND1__8), U3.41 (GND1__9), U3.42 (GND1__10), U3.43 (GND1__11), U3.44 (GND1__12), U3.45 (GND1__13), U3.46 (GND1__14), U3.47 (GND2), U3.48 (GND2__1), U3.49_1 (GND2__2), U3.49_2 (GND2__3), U3.49_3 (GND2__4), U3.49_4 (GND2__5), U3.49_5 (GND2__6), U3.49_6 (GND2__7), U3.49_7 (GND2__8), U3.49_8 (GND2__9), U3.49_9 (GND2__10), U3.50 (GND2__11), U3.51 (GND2__12), U3.52 (GND2__13), U3.53 (GND2__14)
GPIO9: J26.3, U3.23 (IO9)
MOD_CS: IC2.1 (GPB1), J10.1
MOD_ExB2: IC2.2 (GPB2), J19.1
MOD_ExB3: IC2.3 (GPB3), J20.1
MOD_ExB4: IC2.4 (GPB4), J21.1
MOD_ExB5: IC2.5 (GPB5), J22.1
MOD_ExB6: IC2.6 (GPB6), J23.1
MOD_IO15: J16.1, U3.20 (IO15)
MOD_IO18: J15.1, U3.24 (IO18)
MOD_IO19: J14.1, U3.25 (IO19)
MOD_IO20: J13.1, U3.26 (IO20)
MOSI: J5.11, J12.1, U3.10 (IO5)
MOTOR_DIODE_IN: C14.2, D2.3 (A3), M1.2 (-), Q5.3 (C)
unnamed: C2.1, J5.20
unnamed: C6.1, J5.7
unnamed: C8.1, J5.5
unnamed: C9.1, J5.3
unnamed: C10.1, J5.1
unnamed: C3.1, D5.2 (A2), D5.6 (C1)
unnamed: C3.2, D5.3 (A3), L1.1, Q1.3 (D)
unnamed: IC2.7 (GPB7), R19.1
unnamed: IC3.5 (PROG), R15.2
unnamed: IC3.1 (STAT), JP2.1 (A), R16.2
unnamed: J4.A5 (CC1), R5.1
unnamed: J4.B5 (CC2), R4.1
unnamed: J17.1, U3.27 (IO21)
unnamed: Q5.1 (B), R17.1
unnamed: R3.2, U3.22 (IO8)
PREVGH: C5.1, D5.4 (C3), J5.4
PREVGL: D5.1 (A1), J5.2
RES: J5.15, R20.2, U3.5 (IO2)
RESE: J5.22, Q1.2 (S), R9.2
RX: J28.1, U3.30 (RXD0)
SCK: J5.12, J11.1, U3.16 (IO7)
SCL: AC1.12 (SCX), AC2.B2 (SCL), IC2.9 (SCL), J8.1, R1.2, U3.29 (IO23)
SDA: AC1.2 (SDX), AC2.C2 (SDA), IC2.10 (SDA), J9.1, R2.2, U3.28 (IO22)
STAT_IN: IC2.21 (GPA6), JP2.2 (B), R6.1
STAT_OUT: IC2.22 (GPA7), R6.2
TX: J28.2, U3.31 (TXD0)
VBUS: C21.1, C25.1, D2.1 (A1), D4.1 (A1), IC3.4 (VDD), J4.A4 (VBUS_1), J4.A9 (VBUS_2), J7.1, R13.1, R19.2
VIB_PWM: R17.2, U3.19 (IO14)

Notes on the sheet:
This resistor may not be needed
->-
ESP32-C6-MINI-1-N4
the trace going to the diode needs to be shorter than the trace going to the transistor
18pF should be fineee
5V Input / USB C
Battery Charger
Buttons
connect the power to the C11 capacitor
Vibration Motor
max 0.5 A
GPIO Expander
Crystal
Module
3.3V Regulator / Input
https://v4.cecdn.yun300.cn/100001_1909185148/GDEY0154D67-new.pdf
Debug Pins
this needs to be near connector
Accelerometer
E-Paper Driver

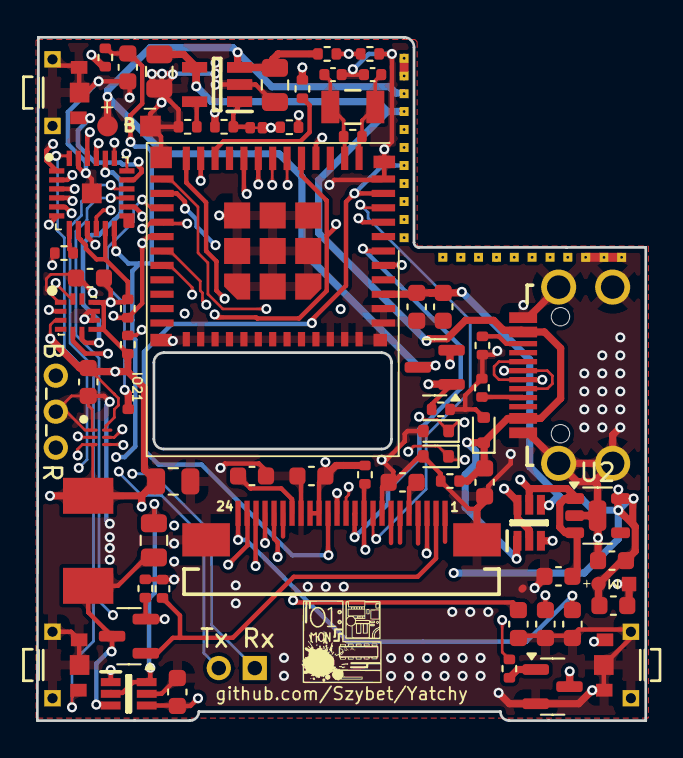
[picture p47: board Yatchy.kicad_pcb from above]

Board: 4 copper layers, 33.8 x 38.0 mm, 90 parts (0 on the bottom side), 62 nets.

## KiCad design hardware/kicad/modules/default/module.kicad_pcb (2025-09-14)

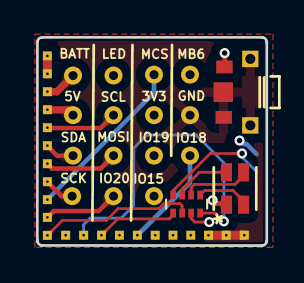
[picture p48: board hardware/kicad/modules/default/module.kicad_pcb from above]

Board: 4 copper layers, 12.7 x 11.6 mm, 41 parts (1 on the bottom side), 23 nets.

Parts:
D1: LED; LED_0402_1005Metric
J1, J2, J3, J4, J5, J6, J7, J8, J9, J10, J11, J12, J13, J14, J15, J16, J17, J18, J19, J20, J21, J22: MOD_CONN; mod_Connector
LED1: CLMVC-FKA-CL1D1L71BB7C3C3; CLMVC-FKA-CL1D1L71BB7C3C3_CRE
RN1: 330 ohm; R_Array_Concave_4x0402
SW2: EVP-AKE31A; SW_EVP-AKE31A_PAN
TP1, TP2, TP3, TP4, TP5, TP6, TP7, TP8, TP9, TP10, TP11, TP12, TP13, TP14, TP15: TestPoint; TestPoint_THTPad_D1.0mm_Drill0.5mm

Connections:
+3V3: D1.2 (A), J5.1, J6.1, LED1.1, TP3.1
+BATT: J4.1, TP2.1
BTN_4: J22.1, SW2.1
GND: J1.1, J2.1, J3.1, SW2.2, SW2.3 (side), SW2.4 (side), SW2.5 (middle), TP1.1
MOD_CS: J10.1, TP7.1
MOD_ExB2: J17.1, RN1.2 (R2.1)
MOD_ExB3: J18.1, RN1.3 (R3.1)
MOD_ExB4: J19.1, RN1.4 (R4.1)
MOD_ExB5: J20.1, RN1.1 (R1.1), TP14.1
MOD_ExB6: J21.1, TP15.1
MOD_IO15: J16.1, TP13.1
MOD_IO18: J15.1, TP12.1
MOD_IO19: J14.1, TP11.1
MOD_IO20: J13.1, TP10.1
MOSI: J12.1, TP9.1
unnamed: D1.1 (K), RN1.8 (R1.2)
unnamed: LED1.2, RN1.7 (R2.2)
unnamed: LED1.3, RN1.6 (R3.2)
unnamed: LED1.4, RN1.5 (R4.2)
SCK: J11.1, TP8.1
SCL: J8.1, TP5.1
SDA: J9.1, TP6.1
VBUS: J7.1, TP4.1

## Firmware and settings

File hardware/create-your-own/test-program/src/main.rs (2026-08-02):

#![no_std]
#![no_main]

use core::mem::MaybeUninit;
use esp_println::logger::init_logger;
use log::{debug, error, info};

use embassy_executor::Spawner;
use esp_backtrace as _;
#[cfg(feature = "usb_jtag")]
use esp_hal::usb_serial_jtag::UsbSerialJtag;
use esp_hal::{interrupt::software::SoftwareInterruptControl, timer::timg::TimerGroup};
#[cfg(feature = "esp32c6")]
mod esp32c6;
#[cfg(feature = "esp32c6")]
use esp32c6::{actions, actions::reset_actions, flex_io::FlexIo, gpio_action::gpio_reset};

#[cfg(feature = "esp32s3")]
mod esp32s3;
#[cfg(feature = "esp32s3")]
use esp32s3::{actions, actions::reset_actions, flex_io::FlexIo, gpio_action::gpio_reset};

fn heap_init() {
    const HEAP_SIZE: usize = 32 * 1024;
    static mut HEAP: MaybeUninit<[u8; HEAP_SIZE]> = MaybeUninit::uninit();

    unsafe {
        esp_alloc::HEAP.add_region(esp_alloc::HeapRegion::new(
            core::ptr::addr_of_mut!(HEAP) as *mut u8,
            HEAP_SIZE,
            esp_alloc::MemoryCapability::Internal.into(),
        ));
    }
}

const MAX_BUFFER_SIZE: usize = 512;

#[derive(Debug, PartialEq, Clone, Copy)]
pub enum CurrentAction {
    Gpio(u32),
    SelfCheckGpio(),
}

esp_bootloader_esp_idf::esp_app_desc!();

#[esp_rtos::main]
async fn main(_spawner: Spawner) {
    init_logger(log::LevelFilter::Info);

    info!("Heap init");
    heap_init();

    info!("Getting the hardware");
    let peripherals = esp_hal::init(esp_hal::Config::default());

    let _sw_int = SoftwareInterruptControl::new(peripherals.SW_INTERRUPT);
    let timg0 = TimerGroup::new(peripherals.TIMG0);
    #[cfg(target_arch = "riscv32")]
    esp_rtos::start(timg0.timer0, _sw_int.software_interrupt0);
    #[cfg(not(target_arch = "riscv32"))]
    esp_rtos::start(timg0.timer0);

    let mut gpios = FlexIo {
        current_output: None,
        #[cfg(feature = "esp32c6")]
        gpio0: esp_hal::gpio::Flex::new(peripherals.GPIO0),
        #[cfg(feature = "esp32c6")]
        gpio1: esp_hal::gpio::Flex::new(peripherals.GPIO1),
        #[cfg(feature = "esp32c6")]
        gpio2: esp_hal::gpio::Flex::new(peripherals.GPIO2),
        #[cfg(feature = "esp32c6")]
        gpio3: esp_hal::gpio::Flex::new(peripherals.GPIO3),
        #[cfg(feature = "esp32c6")]
        gpio4: esp_hal::gpio::Flex::new(peripherals.GPIO4),
        #[cfg(feature = "esp32c6")]
        gpio5: esp_hal::gpio::Flex::new(peripherals.GPIO5),
        #[cfg(feature = "esp32c6")]
        gpio6: esp_hal::gpio::Flex::new(peripherals.GPIO6),
        #[cfg(feature = "esp32c6")]
        gpio7: esp_hal::gpio::Flex::new(peripherals.GPIO7),
        #[cfg(feature = "esp32c6")]
        gpio10: esp_hal::gpio::Flex::new(peripherals.GPIO10),
        #[cfg(feature = "esp32c6")]
        gpio11: esp_hal::gpio::Flex::new(peripherals.GPIO11),
        #[cfg(all(feature = "esp32c6", feature = "uart"))]
        gpio12: esp_hal::gpio::Flex::new(peripherals.GPIO12),
        #[cfg(all(feature = "esp32c6", feature = "uart"))]
        gpio13: esp_hal::gpio::Flex::new(peripherals.GPIO13),
        #[cfg(feature = "esp32c6")]
        gpio14: esp_hal::gpio::Flex::new(peripherals.GPIO14),
        #[cfg(feature = "esp32c6")]
        gpio15: esp_hal::gpio::Flex::new(peripherals.GPIO15),
        #[cfg(feature = "esp32c6")]
        gpio18: esp_hal::gpio::Flex::new(peripherals.GPIO18),
        #[cfg(feature = "esp32c6")]
        gpio19: esp_hal::gpio::Flex::new(peripherals.GPIO19),
        #[cfg(feature = "esp32c6")]
        gpio20: esp_hal::gpio::Flex::new(peripherals.GPIO20),
        #[cfg(feature = "esp32c6")]
        gpio21: esp_hal::gpio::Flex::new(peripherals.GPIO21),
        #[cfg(all(feature = "esp32c6", feature = "i2c"))]
        gpio22: esp_hal::gpio::Flex::new(peripherals.GPIO22),
        #[cfg(all(feature = "esp32c6", feature = "i2c"))]
        gpio23: esp_hal::gpio::Flex::new(peripherals.GPIO23),

        #[cfg(feature = "esp32s3")]
        gpio0: esp_hal::gpio::Flex::new(peripherals.GPIO0),
        #[cfg(feature = "esp32s3")]
        gpio1: esp_hal::gpio::Flex::new(peripherals.GPIO1),
        #[cfg(feature = "esp32s3")]
        gpio2: esp_hal::gpio::Flex::new(peripherals.GPIO2),
        #[cfg(feature = "esp32s3")]
        gpio3: esp_hal::gpio::Flex::new(peripherals.GPIO3),
        #[cfg(feature = "esp32s3")]
        gpio4: esp_hal::gpio::Flex::new(peripherals.GPIO4),
        #[cfg(feature = "esp32s3")]
        gpio5: esp_hal::gpio::Flex::new(peripherals.GPIO5),
        #[cfg(feature = "esp32s3")]
        gpio6: esp_hal::gpio::Flex::new(peripherals.GPIO6),
        #[cfg(feature = "esp32s3")]
        gpio7: esp_hal::gpio::Flex::new(peripherals.GPIO7),
        #[cfg(feature = "esp32s3")]
        gpio8: esp_hal::gpio::Flex::new(peripherals.GPIO8),
        #[cfg(feature = "esp32s3")]
        gpio9: esp_hal::gpio::Flex::new(peripherals.GPIO9),
        #[cfg(feature = "esp32s3")]
        gpio10: esp_hal::gpio::Flex::new(peripherals.GPIO10),
        #[cfg(feature = "esp32s3")]
        gpio11: esp_hal::gpio::Flex::new(peripherals.GPIO11),
        #[cfg(feature = "esp32s3")]
        gpio12: esp_hal::gpio::Flex::new(peripherals.GPIO12),
        #[cfg(feature = "esp32s3")]
        gpio13: esp_hal::gpio::Flex::new(peripherals.GPIO13),
        #[cfg(feature = "esp32s3")]
        gpio14: esp_hal::gpio::Flex::new(peripherals.GPIO14),
        #[cfg(feature = "esp32s3")]
        gpio15: esp_hal::gpio::Flex::new(peripherals.GPIO15),
        #[cfg(feature = "esp32s3")]
        gpio16: esp_hal::gpio::Flex::new(peripherals.GPIO16),
        #[cfg(feature = "esp32s3")]
        gpio17: esp_hal::gpio::Flex::new(peripherals.GPIO17),
        #[cfg(feature = "esp32s3")]
        gpio18: esp_hal::gpio::Flex::new(peripherals.GPIO18),
        #[cfg(all(feature = "esp32s3", not(feature = "usb_jtag")))]
        gpio19: esp_hal::gpio::Flex::new(peripherals.GPIO19),
        #[cfg(all(feature = "esp32s3", not(feature = "usb_jtag")))]
        gpio20: esp_hal::gpio::Flex::new(peripherals.GPIO20),
        #[cfg(feature = "esp32s3")]
        gpio21: esp_hal::gpio::Flex::new(peripherals.GPIO21),
        #[cfg(feature = "esp32s3")]
        gpio34: esp_hal::gpio::Flex::new(peripherals.GPIO34),
        #[cfg(feature = "esp32s3")]
        gpio35: esp_hal::gpio::Flex::new(peripherals.GPIO35),
        #[cfg(feature = "esp32s3")]
        gpio36: esp_hal::gpio::Flex::new(peripherals.GPIO36),
        #[cfg(feature = "esp32s3")]
        gpio37: esp_hal::gpio::Flex::new(peripherals.GPIO37),
        #[cfg(feature = "esp32s3")]
        gpio38: esp_hal::gpio::Flex::new(peripherals.GPIO38),
        #[cfg(feature = "esp32s3")]
        gpio39: esp_hal::gpio::Flex::new(peripherals.GPIO39),
        #[cfg(feature = "esp32s3")]
        gpio40: esp_hal::gpio::Flex::new(peripherals.GPIO40),
        #[cfg(feature = "esp32s3")]
        gpio41: esp_hal::gpio::Flex::new(peripherals.GPIO41),
        #[cfg(feature = "esp32s3")]
        gpio42: esp_hal::gpio::Flex::new(peripherals.GPIO42),
        #[cfg(all(feature = "esp32s3", not(feature = "uart")))]
        gpio43: esp_hal::gpio::Flex::new(peripherals.GPIO43),
        #[cfg(all(feature = "esp32s3", not(feature = "uart")))]
        gpio44: esp_hal::gpio::Flex::new(peripherals.GPIO44),
        #[cfg(feature = "esp32s3")]
        gpio45: esp_hal::gpio::Flex::new(peripherals.GPIO45),
        #[cfg(feature = "esp32s3")]
        gpio46: esp_hal::gpio::Flex::new(peripherals.GPIO46),
        #[cfg(feature = "esp32s3")]
        gpio47: esp_hal::gpio::Flex::new(peripherals.GPIO47),
        #[cfg(feature = "esp32s3")]
        gpio48: esp_hal::gpio::Flex::new(peripherals.GPIO48),
    };

    gpio_reset(&mut gpios).await;
    embassy_time::Timer::after_millis(1000).await;

    #[cfg(feature = "usb_jtag")]
    info!("Initializing usb jtag communication");

    #[cfg(feature = "uart")]
    info!("Initializing uart communication");

    #[cfg(feature = "uart")]
    let (mut rx, mut tx) = {
        #[cfg(feature = "esp32c6")]
        {
            esp_hal::uart::Uart::new(peripherals.UART0, esp_hal::uart::Config::default())
                .unwrap()
                .with_rx(peripherals.GPIO17)
                .with_tx(peripherals.GPIO16)
                .into_async()
                .split()
        }
        #[cfg(feature = "esp32s3")]
        {
            esp_hal::uart::Uart::new(peripherals.UART0, esp_hal::uart::Config::default())
                .unwrap()
                .with_rx(peripherals.GPIO44)
                .with_tx(peripherals.GPIO43)
                .into_async()
                .split()
        }
    };

    #[cfg(feature = "usb_jtag")]
    let (mut rx, mut tx) = UsbSerialJtag::new(peripherals.USB_DEVICE)
        .into_async()
        .split();

    let mut string_buffer: heapless::Vec<u8, MAX_BUFFER_SIZE> = heapless::Vec::new();

    let mut cur_act: Option<CurrentAction> = None;
    let mut started_typing = false;
    loop {
        let mut is_newline = false;
        let mut readed = false;

        let mut small_buf = [0u8; 1];

        #[cfg(feature = "uart")]
        {
            if rx.read_ready() {
                rx.read(&mut small_buf).ok();
                readed = true;
            }
        }

        #[cfg(feature = "usb_jtag")]
        {
            let amount = rx.drain_rx_fifo(&mut small_buf);
            if amount != 0 {
                readed = true;
            }
        }

        if readed {
            let byte = small_buf[0];
            string_buffer.push(byte).unwrap();
            debug!("Received character: {}", byte);
            let _ = tx.write(&[byte]);

            if byte == 13 {
                debug!("Received a new line");
                is_newline = true;
                started_typing = false;
            } else {
                started_typing = true;
                continue;
            }
        }

        #[cfg(feature = "init_test")]
        actions::check_actions(&mut gpios).await;

        if started_typing && !is_newline {
            embassy_time::Timer::after_millis(50).await;
            continue;
        }

        if is_newline {
            if !string_buffer.is_empty() {
                string_buffer.pop();
            }
            if let Ok(action_str) = core::str::from_utf8(&string_buffer) {
                let cur_act_tmp = cur_act;
                if action_str == "exit" {
                    info!("Exiting the current action");
                    reset_actions(&mut gpios).await;
                    cur_act = None;
                } else if let Some(new_act) = gpios.handle_command(action_str) {
                    cur_act = Some(new_act);
                } else {
                    error!("Unknown action: {}", action_str);
                }

                if cur_act_tmp != cur_act {
                    info!("Current action: {:?}", cur_act);
                }
            }
            string_buffer.clear();
        }

        if !readed && cur_act.is_none() {
            embassy_time::Timer::after_millis(200).await;
            continue;
        }

        actions::manage_action(&mut cur_act, &mut gpios).await;
    }
}

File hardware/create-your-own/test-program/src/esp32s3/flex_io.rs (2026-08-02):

use crate::CurrentAction;
use esp_hal::gpio::Flex;

pub struct FlexIo<'a> {
    pub current_output: Option<u32>,
    pub gpio0: Flex<'a>,
    pub gpio1: Flex<'a>,
    pub gpio2: Flex<'a>,
    pub gpio3: Flex<'a>,
    pub gpio4: Flex<'a>,
    pub gpio5: Flex<'a>,
    pub gpio6: Flex<'a>,
    pub gpio7: Flex<'a>,
    pub gpio8: Flex<'a>,
    pub gpio9: Flex<'a>,
    pub gpio10: Flex<'a>,
    pub gpio11: Flex<'a>,
    pub gpio12: Flex<'a>,
    pub gpio13: Flex<'a>,
    pub gpio14: Flex<'a>,
    pub gpio15: Flex<'a>,
    pub gpio16: Flex<'a>,
    pub gpio17: Flex<'a>,
    pub gpio18: Flex<'a>,
    #[cfg(all(feature = "esp32s3", not(feature = "usb_jtag")))]
    pub gpio19: Flex<'a>,
    #[cfg(all(feature = "esp32s3", not(feature = "usb_jtag")))]
    pub gpio20: Flex<'a>,
    pub gpio21: Flex<'a>,
    pub gpio34: Flex<'a>,
    pub gpio35: Flex<'a>,
    pub gpio36: Flex<'a>,
    pub gpio37: Flex<'a>,
    pub gpio38: Flex<'a>,
    pub gpio39: Flex<'a>,
    pub gpio40: Flex<'a>,
    pub gpio41: Flex<'a>,
    pub gpio42: Flex<'a>,
    #[cfg(all(feature = "esp32s3", not(feature = "uart")))]
    pub gpio43: Flex<'a>,
    #[cfg(all(feature = "esp32s3", not(feature = "uart")))]
    pub gpio44: Flex<'a>,
    pub gpio45: Flex<'a>,
    pub gpio46: Flex<'a>,
    pub gpio47: Flex<'a>,
    pub gpio48: Flex<'a>,
}

impl<'a> FlexIo<'a> {
    pub fn handle_command(&self, action: &str) -> Option<CurrentAction> {
        if action.starts_with("gpio") {
            let num_str = &action[4..];
            if let Ok(num) = num_str.parse::<u32>() {
                if self.exists(num) {
                    return Some(CurrentAction::Gpio(num));
                }
            }
        }
        if action == "self_check_gpio" {
            return Some(CurrentAction::SelfCheckGpio());
        }
        None
    }

    fn exists(&self, index: u32) -> bool {
        match index {
            0..=21 | 34..=48 => true,
            _ => false,
        }
    }

    pub fn get_pin(&mut self, index: u32) -> Option<&mut Flex<'a>> {
        match index {
            0 => Some(&mut self.gpio0),
            1 => Some(&mut self.gpio1),
            2 => Some(&mut self.gpio2),
            3 => Some(&mut self.gpio3),
            4 => Some(&mut self.gpio4),
            5 => Some(&mut self.gpio5),
            6 => Some(&mut self.gpio6),
            7 => Some(&mut self.gpio7),
            8 => Some(&mut self.gpio8),
            9 => Some(&mut self.gpio9),
            10 => Some(&mut self.gpio10),
            11 => Some(&mut self.gpio11),
            12 => Some(&mut self.gpio12),
            13 => Some(&mut self.gpio13),
            14 => Some(&mut self.gpio14),
            15 => Some(&mut self.gpio15),
            16 => Some(&mut self.gpio16),
            17 => Some(&mut self.gpio17),
            18 => Some(&mut self.gpio18),
            #[cfg(all(feature = "esp32s3", not(feature = "usb_jtag")))]
            19 => Some(&mut self.gpio19),
            #[cfg(all(feature = "esp32s3", not(feature = "usb_jtag")))]
            20 => Some(&mut self.gpio20),
            21 => Some(&mut self.gpio21),
            34 => Some(&mut self.gpio34),
            35 => Some(&mut self.gpio35),
            36 => Some(&mut self.gpio36),
            37 => Some(&mut self.gpio37),
            38 => Some(&mut self.gpio38),
            39 => Some(&mut self.gpio39),
            40 => Some(&mut self.gpio40),
            41 => Some(&mut self.gpio41),
            42 => Some(&mut self.gpio42),
            #[cfg(all(feature = "esp32s3", not(feature = "uart")))]
            43 => Some(&mut self.gpio43),
            #[cfg(all(feature = "esp32s3", not(feature = "uart")))]
            44 => Some(&mut self.gpio44),
            45 => Some(&mut self.gpio45),
            46 => Some(&mut self.gpio46),
            47 => Some(&mut self.gpio47),
            48 => Some(&mut self.gpio48),
            _ => None,
        }
    }
}

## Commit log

2024-08-04 any pin flex pin madness, not yet working
    [actions.rs, flex_io.rs, gpio_action.rs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]
2024-11-07 add hardware
    [BAT54TW-7-F.stp, BMA456.stp, BMA530.stp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]
2024-11-29 ignore pin 13 and disable jtag when uart
2024-12-01 change motor transistor name
    [Yatchy.kicad_pcb, Yatchy.kicad_sch]
2024-12-20 add wv2c
    [watchyv2-calculations.ods]
2024-12-25 fix module 3d models
    [module.kicad_pcb]
2025-01-31 change tvs diode fix module and calc
    [Calc.ods, Yatchy.kicad_pcb, Yatchy.kicad_sch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]
2025-01-31 move components
    [components-calc.ods]
2025-02-01 remove mouse bites
    [Yatchy.kicad_pcb, Yatchy.kicad_sch]
2025-02-01 fix outline
    [Yatchy.kicad_pcb]
2025-04-15 brick case
    [Brick case for 30x20x5mm.step]
2025-04-25 reminders of risk
    [components-calc.ods]
2025-04-26 fix test program I fogor wat
    [flex_io.rs, gpio_action.rs, main.rs]
2025-05-12 fix components-calc based on bom file, add 1K resistor to gpio expander 5V connection, change 50K resistor to 100K
    [Yatchy.kicad_pcb, Yatchy.kicad_sch, components-calc.ods]
2025-07-04 case patches
    [better_strap_dot.stl, case_front_v2.step, motor_cover_thinner.step]
2025-07-22 connect mcp reset pin with esp32c6
    [Yatchy.kicad_pcb, Yatchy.kicad_sch]
2025-08-03 add 1A ldo
    [components-calc.ods]
2025-08-23 Some quality of life improvements to the pcb, applied suggestions to the pcb
    [Yatchy.kicad_pcb]
2025-08-23 zone refill forgot
    [Yatchy.kicad_pcb]
2025-08-25 improve module silkscreen
    [module.kicad_pcb, module.kicad_sch]
2025-08-27 Add screen, expose test point
    [Waveshare 1.54 (B) E ink - Display Flush Folded.stp, Yatchy.kicad_pcb, Yatchy.kicad_sch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]
2025-08-27 fix dfm and screen footprint
    [Yatchy.kicad_pcb]
2025-08-28 Add silkscreen
    [Yatchy.kicad_pcb]
2025-08-31 add thermal pad voltage regulator
    [Yatchy.kicad_pcb]
2025-09-12 Automatic generation of schematics and iboms
2025-09-14 add new module
    [AST0760_MAL.step, BAT54TW-7-F.stp, CLMVC-FKA-CL1D1L71BB7C3C3_CRE.step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]
2025-09-14 rename & improve site
    [module.kicad_pcb, module.kicad_sch]
2025-09-16 add case
2025-10-15 Update and rename yatchy case for 20mm one piece strap.step to thicc-case-for-20mm-one-piece-strap.step
    [thicc-case-for-20mm-one-piece-strap.step]
2026-04-24 michal case
    [michal-gameboy-bottom.3mf, michal-gameboy-top.3mf, michal-gameboy.FCStd]
2026-08-18 gameboy case update
    [michal-gameboy-bottom.3mf, michal-gameboy-top.3mf, michal-gameboy.FCStd]
